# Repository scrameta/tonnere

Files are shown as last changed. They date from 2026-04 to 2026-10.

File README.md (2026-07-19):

# Project Tonnere

The EclaireXL was a partially open Atari XL FPGA implementation designed almost
a decade ago. This project is intended to be a fully open community follow-up
version. (It is being renamed **MegaXE**; *tonnere* — deliberately misspelt, to
match "EclaireXL" — is French for thunder, following on from the EclaireXL's
lightning.)

## The Atari core

The FPGA Atari core itself is **not** duplicated here. It lives in the shared
[**atari_xl_fpga_common**](https://github.com/scrameta/atari_xl_fpga_common)
repository — the same core used by the multi-board
[atari_xl_fpga](https://github.com/scrameta/atari_xl_fpga) project — and is
included in this repo as a git submodule at `atari_800xl/common`. This board
project provides the hardware design plus the board-specific top level, clocking,
pin mapping and I/O wrapped around that common core.

## Getting the code

The shared core is a submodule, so clone recursively:

```sh
git clone --recursive https://github.com/scrameta/tonnere

# …or, if you already cloned without --recursive:
git submodule update --init --recursive
```

The core then appears under `atari_800xl/common`. To move onto a newer core
revision, bump the submodule pointer:

```sh
cd atari_800xl/common
git checkout <desired-commit-or-branch>
cd -
git add atari_800xl/common
git commit -m "Bump common core to <rev>"
```

See the
[common repo](https://github.com/scrameta/atari_xl_fpga_common#using-this-repository)
for more on the submodule workflow.

## Status

For now there is only a hardware design, from which a physical board has been
produced. The design goals of this are described below.

## Memory

3 independent banks of RAM from FPGA

- 512KB 16-bit wide 10ns SRAM (for VBXE)
- 2048KB 16-bit wide 10ns SRAM (primary Atari core)
- 32MB 16-bit wide SDRAM (secondary Atari core etc - for large memory expansions, cartridge emulation etc)

## Video output

- HDMI driven directly by FPGA
- Analog video driven by FPGA (3 pins/channel - ~8-bit/channel resolution) filtered/buffered by THS7316.
- NTSC in 480i or 480p, PAL in 576i or 576p
- Polyphasic and area-based scaler allowing 720p, 1080i etc

## Audio output

- PCM5102A DAC

## Audio input

- 12-bit ADC for PBI, SIO, 3.5mm left/right on STM microcontroller

## Joystick ports 1-4

- Directly connected to FPGA (via level shifters)
- Paddle support using STM ADC inputs

## Six USB ports

- 1 USB A internal for keyboard
- 3 USB A external for joystick, keyboard etc
- 1 USB C for power only (next to power switch)
- 1 rear USB C for STM32 DFU (to program it), or to be a mass-storage slave to a PC to copy data on.

## Atari peripheral emulator (ESP32 microcontroller/almost Fujinet)

- Wifi support
- Serial connection to STM32
- SPI master to FPGA (for DMA to RAM, faster than serial via STM)
- SIO pins (all)
- Audio out DAC goes to SIO audio in
- Slave to STM32
- Slave to Atari via SIO
- JTAG for debugging

## Firmware/control (STM32)

- SPI master to FPGA SPI flash chip (to program)
- Can restart FPGA
- SRAM port connected to FPGA (for DMA to Atari core RAM + RAM banks)
- IRQ from FPGA
- 4-bit external SD card interface
- SPI to internal micro SD card (will appear as IDE hard drive to Atari core)
- ADC for sampling (see audio in)
- Serial connection for communication for Atari peripheral emulator
- USB port + stack
- DFU mode for programming, can then program FPGA flash and ESP32 via serial (+BOOT etc).
- HDMI i2c link (to get mode support)
- PLL i2c link (6 programmable clocks for FPGA)
- SWD port for debugging
- UART port for debugging/expansion
- Will run menus etc, via DMA to Atari core (+ potentially framebuffer)

## Atari core (Cyclone 10 LP FPGA)

- Core Atari XL and Atari 800 support
- 2x/4x colour clock Antic/GTIA support
- VBXE
- PokeyMAX
- HDD via IDE emulation on microsd
- Turbo freezer
- Common cartridge banking logic (on RAM)

## Atari ports

- Left cartridge
- PBI with standard extensions (enabled/selected via jumper), 50 pin edge and 50 pin header option.
- SIO (with motor control, without 12V)
- Start/select/option/reset switch headers
- 4 joystick ports

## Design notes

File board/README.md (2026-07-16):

# Board status
## 0.51

| Component | Status | Comment |
| --- | --- | --- |
| Audio DAC |  🟢 | Played a multi-frequency sine wave fine |
| ESP32 |  🟢 | Ran simple pin toggler, also checked it appears on JTAG | 
| ESP32 audio DAC | ⚪ | |
| ESP32 WIFI | ⚪ | |
| FPGA |  🟢 | Working fine. Caution: Do not use clock input pins as outputs!  | 
| FPGA FLASH |  🟢 | Working fine. Only tested one IC.  | 
| HDMI port |  🟢 | Tested DVI video output  | 
| JOYSTICK DIR |  🟢 | Tested toggling pins |
| JOYSTICK PADDLES  | ⚪ |  |
| PLL1 |  🟢 | Programmed via I2C and checked they produce clocks |
| PLL2 |  🟢 | Programmed via I2C and checked they produce clocks |
| SDCARD(EXT) | ⚪ |  | 
| SDCARD(INT) | ⚪ |  | 
| SDRAM |  🟢 | Boots to ready | 
| SRAM1 |  🟡 | Used input pins on FPGA, had to correct with a few wires  | 
| SRAM2 |  🟡 | Used input pins on FPGA, had to correct with a few wires  | 
| STM32 ADC | ⚪ |  | 
| STM32 CORE |  🟢 | Code running fine. SWD works. USART debug works. | 
| STM32 DFU |  🟡 | DFU slow to start due to PB5 connected to FPGA flash chip during boot  | 
| STM32 RTC |  ⚪ | | 
| STM32 FSMC |  🟢 | Checked basic SRAM access via FPGA from STM | 
| PBI |  🟢 | Tested toggling pins | 
| SIO |  🟡 | Tested toggling pins. Motor control did not go via level shifter. | 
| USB |  🟢 | Tested keyboard in all ports. STM needed patches hub (class + reconnect fix) |
| Video DAC |  🟡 | Single pin was too aggressive for sigma delta (very low oversampling). Too noisy. Added 2nd pin and used fixed patterns. Achieved 6-bit |

## 0.60

Not made yet...

## Key
| Symbol | Status |
| --- | --- |
| ⚪ | Not checked yet |
| 🔴 | Failed |
| 🟡 | Works with workaround |
| 🟢 | Passed |

Passed does not mean thoroughly checked...

<!--
| Feature A | ⚪ | Not checked yet |
| Feature C | 🟡 | Works with workaround |
| Feature D | 🟢 | Passed |
-->

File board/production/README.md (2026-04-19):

# Actual board production files
Not done as tags but as an explicit file per version, for ease of visibility/access
Repo should be tagged though as of this version

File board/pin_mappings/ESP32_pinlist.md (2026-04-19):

# ESP32 module (U34: ESP32‑WROVER‑E) pin usage summary and pinlist

Derived from the KiCad netlist (`tonnere.net`). The ESP32 GPIO matrix allows
flexible peripheral routing, so this is primarily a *wiring* pinlist showing
which module pads are used and what they connect to.

## Connectivity overview

- **SPI to FPGA**: 4 pins (SCK/MOSI/MISO/CS) — direct to Cyclone 10 U30,
  no level-shifter. FPGA is bus master.
- **Atari SIO**: 8 pins — directly wired to the SIO signals (shared with FPGA
  U30 via bus switch U31). The ESP32 can participate in SIO traffic
  independently of the FPGA.
- **UART to STM32**: 2 pins (RXD0/TXD0) — direct to STM32 USART6 (PC6/PC7).
  Also broken out on J18 (ESP PGM header).
- **GPIO handshake to/from STM32**: 4 pins — 3 input-only (SGPI0-2 from
  STM32 PG8-10) + 1 output (SGPIO to STM32 PA9). None pass through the FPGA.
- **JTAG**: 4 pins (optional, directly on ESP GPIOs via GPIO matrix).
- **Audio**: 1 pin (ESPAUD.SIO via bus switch U31).
- **BOOT/EN**: IO0 (boot strap) and EN (chip enable), directly also connected to
  STM32 (PG6/PG7) and broken out on J18 header.

## Pinlist
| Module pad | ESP32 signal | GPIO | Function | Net | Notes |
|---:|---|---|---|---|---|
| 3 | EN |  | EN (chip enable/reset) | /ESP32/ESP.EN | Pull-up (R99); also on J18 ESP PGM header |
| 4 | SENSOR_VP/IO36 | IO36 | GPIO from STM32 | /ESP32/ESP.SGPI0 | Input-only; <- STM32 PG8 |
| 5 | SENSOR_VN/IO39 | IO39 | GPIO from STM32 | /ESP32/ESP.SGPI1 | Input-only; <- STM32 PG9 |
| 6 | IO34 | IO34 | GPIO from STM32 | /ESP32/ESP.SGPI2 | Input-only; <- STM32 PG10 |
| 7 | IO35 | IO35 | Atari SIO | /AtariInterfaces/SIO.MOTOR | Also to FPGA U30; ext pull-up +5V (R30) |
| 8 | IO32 | IO32 | Atari SIO | /AtariInterfaces/SIO.INTERRUPT | Also to FPGA U30; ext pull-up +5V (RN3) |
| 9 | IO33 | IO33 | Atari SIO | /AtariInterfaces/SIO.COMMAND | Also to FPGA U30; ext pull-up +5V (RN3) |
| 10 | IO25 | IO25 | Atari SIO | /AtariInterfaces/SIO.DATA_IN | Also to FPGA U30; ext pull-up +5V (RN4) |
| 11 | IO26 | IO26 | Audio SIO | /Audio/ESPAUD.SIO | Audio SIO; via bus switch U31 |
| 12 | IO27 | IO27 | Atari SIO | /AtariInterfaces/SIO.PROCEED | Also to FPGA U30; ext pull-up +5V (RN3) |
| 13 | IO14 | IO14 | JTAG (optional) | /ESP32/ESPJTAG.TMS | Via GPIO matrix |
| 14 | IO12 | IO12 | JTAG (optional) | /ESP32/ESPJTAG.TDI | Via GPIO matrix |
| 16 | IO13 | IO13 | JTAG (optional) | /ESP32/ESPJTAG.TCK | Via GPIO matrix |
| 23 | IO15 | IO15 | JTAG (optional) | /ESP32/ESPJTAG.TDO | Via GPIO matrix |
| 24 | IO2 | IO2 | GPIO to STM32 | /ESP32/ESP.SGPIO | -> STM32 PA9 |
| 25 | IO0 | IO0 | BOOT strap (GPIO0) | /ESP32/ESP.BOOT | Low=bootloader; also STM32 PG6 and J18 header |
| 26 | IO4 | IO4 | Atari SIO | /AtariInterfaces/SIO.CLOCK_OUT | Also to FPGA U30; ext pull-up +5V (RN4) |
| 29 | IO5 | IO5 | SPI to FPGA (U30) | /ESP32/ESP.CS | CS active low; pull-up to +3V3 (R94) |
| 30 | IO18 | IO18 | SPI to FPGA (U30) | /ESP32/ESP.SCK | Direct to FPGA U30 |
| 31 | IO19 | IO19 | SPI to FPGA (U30) | /ESP32/ESP.MISO | Direct to FPGA U30 |
| 33 | IO21 | IO21 | Atari SIO | /AtariInterfaces/SIO.CLOCK_IN | Also to FPGA U30; ext pull-up +5V (RN4) |
| 34 | RXD0 | RXD0 | UART to STM32 | /ESP32/UART1.TX | STM32 USART6 RX (PC7); also on J18 header |
| 35 | TXD0 | TXD0 | UART to STM32 | /ESP32/UART1.RX | STM32 USART6 TX (PC6); also on J18 header |
| 36 | IO22 | IO22 | Atari SIO | /AtariInterfaces/SIO.DATA_OUT | Also to FPGA U30; ext pull-up +5V (RN4) |
| 37 | IO23 | IO23 | SPI to FPGA (U30) | /ESP32/ESP.MOSI | Direct to FPGA U30 |

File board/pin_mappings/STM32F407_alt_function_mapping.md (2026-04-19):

# STM32F407ZG (U19) pin usage and alternate functions (from tonnere.net)

## FSMC (47 pins)
AF used: **AF12** (FSMC/FMC). Total FSMC-related pins in netlist: 47.
See the CSV/XLSX for the full per-pin list.

## SPI (4 pins)
| STM32 pin | Package pin | Signal | AF | Net | Note |
|---|---:|---|---|---|---|
| PB4 | 134 | SPI1_MISO | AF5 | /FPGA/SPI.MISO |  |
| PB5 | 135 | SPI1_MOSI | AF5 | /FPGA/SPI.MOSI |  |
| PB6 | 136 | SPI1_NSS1 (GPIO or NSS) | AF5 | /FPGA/SPI.CS1 | Chip-select likely GPIO (or SPI NSS depending config) |
| PB7 | 137 | SPI1_NSS2 (GPIO) | AF5 | /FPGA/SPI.CS2 | Chip-select likely GPIO (or SPI NSS depending config) |

## USART/UART (7 pins)
| STM32 pin | Package pin | Signal | AF | Net | Note |
|---|---:|---|---|---|---|
| PB10 | 69 | USART3_TX | AF7 (USART3) | /Microcontroller/USART1.TX |  |
| PB11 | 70 | USART3_RX | AF7 (USART3) | /Microcontroller/USART1.RX |  |
| PB12 | 73 | USART3_CK | AF7 (USART3) | /Microcontroller/USART1.CK |  |
| PB13 | 74 | USART3_CTS | AF7 (USART3) | /Microcontroller/USART1.CTS |  |
| PB14 | 75 | USART3_RTS | AF7 (USART3) | /Microcontroller/USART1.RTS |  |
| PC6 | 96 | USART6_TX | AF8 (USART6) | /ESP32/UART1.TX |  |
| PC7 | 97 | USART6_RX | AF8 (USART6) | /ESP32/UART1.RX |  |

## I2C (3 pins)
| STM32 pin | Package pin | Signal | AF | Net | Note |
|---|---:|---|---|---|---|
| PB8 | 139 | I2C1_SCL | AF4 | /Microcontroller/STM.SCL |  |
| PB9 | 140 | I2C1_SDA | AF4 | /Microcontroller/STM.SDA |  |
| PC5 | 45 | I2C | AF4 | /Microcontroller/STM.I2CRESET | Reset line for I2C devices? (GPIO) |

## GPIO/Other (46 pins)
| STM32 pin | Package pin | Signal | AF | Net | Note |
|---|---:|---|---|---|---|
| PA0 | 34 | JOY2.POT4 | None | /AtariInterfaces/JOY2.POT4 | Analog input (ADC) for paddle/pot |
| PA1 | 35 | JOY2.POT5 | None | /AtariInterfaces/JOY2.POT5 | Analog input (ADC) for paddle/pot |
| PA13 | 105 | Net-(J9-Pin_2) | None | Net-(J9-Pin_2) |  |
| PA14 | 109 | Net-(J9-Pin_3) | None | Net-(J9-Pin_3) |  |
| PA2 | 36 | STMAUD.ADC.L | None | /Audio/STMAUD.ADC.L |  |
| PA3 | 37 | STMAUD.ADC.R | None | /Audio/STMAUD.ADC.R |  |
| PA4 | 40 | JOY2.POT6 | None | /AtariInterfaces/JOY2.POT6 | Analog input (ADC) for paddle/pot |
| PA5 | 41 | JOY2.POT7 | None | /AtariInterfaces/JOY2.POT7 | Analog input (ADC) for paddle/pot |
| PA6 | 42 | STMAUD.ADC.PBI | None | /Audio/STMAUD.ADC.PBI |  |
| PA7 | 43 | STMAUD.ADC.SIO | None | /Audio/STMAUD.ADC.SIO |  |
| PB2 | 48 | BOOT1 | None | /Microcontroller/BOOT1 |  |
| PB3 | 133 | Net-(U19-PB3) | None | Net-(U19-PB3) |  |
| PC0 | 26 | JOY.POT0 | None | /AtariInterfaces/JOY.POT0 | Analog input (ADC) for paddle/pot |
| PC1 | 27 | JOY.POT1 | None | /AtariInterfaces/JOY.POT1 | Analog input (ADC) for paddle/pot |
| PC10 | 111 | Net-(RN10-R2.2) | None | Net-(RN10-R2.2) |  |
| PC11 | 112 | Net-(RN10-R1.2) | None | Net-(RN10-R1.2) |  |
| PC12 | 113 | Net-(RN7-R4.2) | None | Net-(RN7-R4.2) |  |
| PC13 | 7 | Net-(RN7-R3.2) | None | Net-(RN7-R3.2) |  |
| PC14 | 8 | Net-(U19-PC14) | None | Net-(U19-PC14) |  |
| PC15 | 9 | Net-(U19-PC15) | None | Net-(U19-PC15) |  |
| PC2 | 28 | JOY.POT2 | None | /AtariInterfaces/JOY.POT2 | Analog input (ADC) for paddle/pot |
| PC3 | 29 | JOY.POT3 | None | /AtariInterfaces/JOY.POT3 | Analog input (ADC) for paddle/pot |
| PC8 | 98 | Net-(RN10-R4.2) | None | Net-(RN10-R4.2) |  |
| PC9 | 99 | Net-(RN10-R3.2) | None | Net-(RN10-R3.2) |  |
| PD2 | 116 | Net-(RN7-R1.2) | None | Net-(RN7-R1.2) |  |
| PD3 | 117 | Net-(RN7-R2.2) | None | Net-(RN7-R2.2) |  |
| PF10 | 22 | Net-(J10-Pin_3) | None | Net-(J10-Pin_3) |  |
| PF6 | 18 | Net-(J10-Pin_7) | None | Net-(J10-Pin_7) |  |
| PF7 | 19 | Net-(J10-Pin_6) | None | Net-(J10-Pin_6) |  |
| PF8 | 20 | Net-(J10-Pin_5) | None | Net-(J10-Pin_5) |  |
| PF9 | 21 | Net-(J10-Pin_4) | None | Net-(J10-Pin_4) |  |
| PG11 | 126 | FPGA.PS_N | None | /FPGA/FPGA.PS_N |  |
| PG12 | 127 | FPGA.IRQ | None | /FPGA/FPGA.IRQ |  |
| PG13 | 128 | FPGA.CONFIG_N | None | /FPGA/FPGA.CONFIG_N |  |
| PG14 | 129 | FPGA.STATUS_N | None | /FPGA/FPGA.STATUS_N |  |
| PG15 | 132 | FPGA.CONF_DONE | None | /FPGA/FPGA.CONF_DONE |  |
| PG6 | 91 | ESP.BOOT | None | /ESP32/ESP.BOOT |  |
| PG7 | 92 | ESP.EN | None | /ESP32/ESP.EN |  |
| PG8 | 93 | ESP.SGPI0 | None | /ESP32/ESP.SGPI0 |  |
| PG9 | 124 | ESP.SGPI1 | None | /ESP32/ESP.SGPI1 |  |
| PG10 | 125 | ESP.SGPI2 | None | /ESP32/ESP.SGPI2 |  |
| PA9 | 101 | ESP.SGPIO | None | /ESP32/ESP.SGPIO |  |
| PH0 | 23 | Net-(U19-PH0) | None | Net-(U19-PH0) |  |
| PH1 | 24 | Net-(U19-PH1) | None | Net-(U19-PH1) |  |
| nan | 25 | NRST | None | /Microcontroller/NRST |  |
| nan | 138 | Net-(JP1-C) | None | Net-(JP1-C) |  |

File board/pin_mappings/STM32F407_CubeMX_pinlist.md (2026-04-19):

# STM32F407ZG (U19) CubeMX-style summary and pinlist

Derived from the KiCad netlist (`tonnere.net`). Reflects which STM32 pins are
wired to which functions, with alternate-function assignments where applicable.

## Peripheral summary

- **FMC/FSMC** (AF12): 47 pins — external bus to FPGA U30 (address/data/control).
  Direct wiring, no bus switch.
- **SPI** (AF5): 4 pins (PB3-PB7) — shared active-serial/SD/flash SPI bus.
  PB3 (SCK) via series R52.  PB6/PB7 are chip-selects (CS1=SD, CS2=FPGA flash).
- **USART3** (AF7): 5 pins (PB10-PB14) — general-purpose USART.
  Note: net labels say USART1 but the STM32 AF7 on PB10-14 is USART3.
- **USART6** (AF8): 2 pins (PC6/PC7) — UART to ESP32 (RXD0/TXD0).
  Also broken out on J18 (ESP PGM header).
- **I2C1** (AF4): 2 pins (PB8/PB9) + 1 GPIO reset (PC5).
- **SDIO** (AF12): 6 pins (PC8-PC12, PD2) — SD card interface via series
  resistor networks RN7 (CMD/CK) and RN10 (D0-D3). PC13 is SD card detect (GPIO).
- **Debug**: PA13/PA14 (SWDIO/SWCLK) on J9 SWD header.
  PC14/PC15 are OSC32_IN/OUT (32.768 kHz RTC crystal Y2).
- **ADC analog inputs**: joystick pots (PA0-1/PA4-5/PC0-3) and audio ADC (PA2-3/PA6-7).
- **ESP32 GPIO**: PG6/PG7 -> ESP32 IO0/EN (boot/reset control, also on J18).
  PG8-10 -> ESP32 input-only SGPI0-2.  PA9 <- ESP32 SGPIO (IO2).
- **FPGA control**: PG11 -> MSEL1, PG12 <- IRQ, PG13 -> nCONFIG,
  PG14 <- nSTATUS, PG15 <- CONF_DONE.

## Pinlist
| STM32 pin | LQFP pin | Mode (CubeMX) | AF | User label | Net | Notes |
|---|---:|---|---|---|---|---|
| PA13 | 105 | Debug |  | SWDIO | Net-(J9-Pin_2) | J9 SWD header pin 2 |
| PA14 | 109 | Debug |  | SWCLK | Net-(J9-Pin_3) | J9 SWD header pin 3 |
| PA11 | 103 | FSMC (AF12) | AF12 | FSMC | Net-(U19-PA11) |  |
| PA12 | 104 | FSMC (AF12) | AF12 | FSMC | Net-(U19-PA12) |  |
| PD0 | 114 | FSMC (AF12) | AF12 | FSMC_D2 | /FPGA/FSMC.D2 |  |
| PD1 | 115 | FSMC (AF12) | AF12 | FSMC_D3 | /FPGA/FSMC.D3 |  |
| PD10 | 79 | FSMC (AF12) | AF12 | FSMC_D15 | /FPGA/FSMC.D15 |  |
| PD11 | 80 | FSMC (AF12) | AF12 | FSMC_A16 | /FPGA/FSMC.A16 |  |
| PD12 | 81 | FSMC (AF12) | AF12 | FSMC_A17 | /FPGA/FSMC.A17 |  |
| PD13 | 82 | FSMC (AF12) | AF12 | FSMC_A18 | /FPGA/FSMC.A18 |  |
| PD14 | 85 | FSMC (AF12) | AF12 | FSMC_D0 | /FPGA/FSMC.D0 |  |
| PD15 | 86 | FSMC (AF12) | AF12 | FSMC_D1 | /FPGA/FSMC.D1 |  |
| PD4 | 118 | FSMC (AF12) | AF12 | FSMC_NOE | /FPGA/FSMC.NOE |  |
| PD5 | 119 | FSMC (AF12) | AF12 | FSMC_NWE | /FPGA/FSMC.NWE |  |
| PD6 | 122 | FSMC (AF12) | AF12 | FSMC_NWAIT | /FPGA/FSMC.NWAIT |  |
| PD7 | 123 | FSMC (AF12) | AF12 | FSMC_NE1 | /FPGA/FSMC.NE1 |  |
| PD8 | 77 | FSMC (AF12) | AF12 | FSMC_D13 | /FPGA/FSMC.D13 |  |
| PD9 | 78 | FSMC (AF12) | AF12 | FSMC_D14 | /FPGA/FSMC.D14 |  |
| PE0 | 141 | FSMC (AF12) | AF12 | FSMC_NBL0 | /FPGA/FSMC.NBL0 |  |
| PE1 | 142 | FSMC (AF12) | AF12 | FSMC_NBL1 | /FPGA/FSMC.NBL1 |  |
| PE10 | 63 | FSMC (AF12) | AF12 | FSMC_D7 | /FPGA/FSMC.D7 |  |
| PE11 | 64 | FSMC (AF12) | AF12 | FSMC_D8 | /FPGA/FSMC.D8 |  |
| PE12 | 65 | FSMC (AF12) | AF12 | FSMC_D9 | /FPGA/FSMC.D9 |  |
| PE13 | 66 | FSMC (AF12) | AF12 | FSMC_D10 | /FPGA/FSMC.D10 |  |
| PE14 | 67 | FSMC (AF12) | AF12 | FSMC_D11 | /FPGA/FSMC.D11 |  |
| PE15 | 68 | FSMC (AF12) | AF12 | FSMC_D12 | /FPGA/FSMC.D12 |  |
| PE3 | 2 | FSMC (AF12) | AF12 | FSMC_A19 | /FPGA/FSMC.A19 |  |
| PE4 | 3 | FSMC (AF12) | AF12 | FSMC_A20 | /FPGA/FSMC.A20 |  |
| PE5 | 4 | FSMC (AF12) | AF12 | FSMC_A21 | /FPGA/FSMC.A21 |  |
| PE6 | 5 | FSMC (AF12) | AF12 | FSMC_A22 | /FPGA/FSMC.A22 |  |
| PE7 | 58 | FSMC (AF12) | AF12 | FSMC_D4 | /FPGA/FSMC.D4 |  |
| PE8 | 59 | FSMC (AF12) | AF12 | FSMC_D5 | /FPGA/FSMC.D5 |  |
| PE9 | 60 | FSMC (AF12) | AF12 | FSMC_D6 | /FPGA/FSMC.D6 |  |
| PF0 | 10 | FSMC (AF12) | AF12 | FSMC_A0 | /FPGA/FSMC.A0 |  |
| PF1 | 11 | FSMC (AF12) | AF12 | FSMC_A1 | /FPGA/FSMC.A1 |  |
| PF12 | 50 | FSMC (AF12) | AF12 | FSMC_A6 | /FPGA/FSMC.A6 |  |
| PF13 | 53 | FSMC (AF12) | AF12 | FSMC_A7 | /FPGA/FSMC.A7 |  |
| PF14 | 54 | FSMC (AF12) | AF12 | FSMC_A8 | /FPGA/FSMC.A8 |  |
| PF15 | 55 | FSMC (AF12) | AF12 | FSMC_A9 | /FPGA/FSMC.A9 |  |
| PF2 | 12 | FSMC (AF12) | AF12 | FSMC_A2 | /FPGA/FSMC.A2 |  |
| PF3 | 13 | FSMC (AF12) | AF12 | FSMC_A3 | /FPGA/FSMC.A3 |  |
| PF4 | 14 | FSMC (AF12) | AF12 | FSMC_A4 | /FPGA/FSMC.A4 |  |
| PF5 | 15 | FSMC (AF12) | AF12 | FSMC_A5 | /FPGA/FSMC.A5 |  |
| PG0 | 56 | FSMC (AF12) | AF12 | FSMC_A10 | /FPGA/FSMC.A10 |  |
| PG1 | 57 | FSMC (AF12) | AF12 | FSMC_A11 | /FPGA/FSMC.A11 |  |
| PG2 | 87 | FSMC (AF12) | AF12 | FSMC_A12 | /FPGA/FSMC.A12 |  |
| PG3 | 88 | FSMC (AF12) | AF12 | FSMC_A13 | /FPGA/FSMC.A13 |  |
| PG4 | 89 | FSMC (AF12) | AF12 | FSMC_A14 | /FPGA/FSMC.A14 |  |
| PG5 | 90 | FSMC (AF12) | AF12 | FSMC_A15 | /FPGA/FSMC.A15 |  |
| NRST | 25 | GPIO (TBD) |  | NRST | /Microcontroller/NRST |  |
| Net-(JP1-C) | 138 | GPIO (TBD) |  | Net-(JP1-C) | Net-(JP1-C) |  |
| PA0 | 34 | GPIO (TBD) |  | JOY2.POT4 | /AtariInterfaces/JOY2.POT4 | Analog input (ADC) for paddle/pot |
| PA1 | 35 | GPIO (TBD) |  | JOY2.POT5 | /AtariInterfaces/JOY2.POT5 | Analog input (ADC) for paddle/pot |
| PA2 | 36 | GPIO (TBD) |  | STMAUD.ADC.L | /Audio/STMAUD.ADC.L |  |
| PA3 | 37 | GPIO (TBD) |  | STMAUD.ADC.R | /Audio/STMAUD.ADC.R |  |
| PA4 | 40 | GPIO (TBD) |  | JOY2.POT6 | /AtariInterfaces/JOY2.POT6 | Analog input (ADC) for paddle/pot |
| PA5 | 41 | GPIO (TBD) |  | JOY2.POT7 | /AtariInterfaces/JOY2.POT7 | Analog input (ADC) for paddle/pot |
| PA6 | 42 | GPIO (TBD) |  | STMAUD.ADC.PBI | /Audio/STMAUD.ADC.PBI |  |
| PA7 | 43 | GPIO (TBD) |  | STMAUD.ADC.SIO | /Audio/STMAUD.ADC.SIO |  |
| PA9 | 101 | GPIO (TBD) |  | ESP.SGPIO | /ESP32/ESP.SGPIO | ESP32 IO2 (SGPIO) via R92 |
| PB2 | 48 | GPIO (TBD) |  | BOOT1 | /Microcontroller/BOOT1 |  |
| PC0 | 26 | GPIO (TBD) |  | JOY.POT0 | /AtariInterfaces/JOY.POT0 | Analog input (ADC) for paddle/pot |
| PC1 | 27 | GPIO (TBD) |  | JOY.POT1 | /AtariInterfaces/JOY.POT1 | Analog input (ADC) for paddle/pot |
| PC2 | 28 | GPIO (TBD) |  | JOY.POT2 | /AtariInterfaces/JOY.POT2 | Analog input (ADC) for paddle/pot |
| PC3 | 29 | GPIO (TBD) |  | JOY.POT3 | /AtariInterfaces/JOY.POT3 | Analog input (ADC) for paddle/pot |
| PD3 | 117 | GPIO (TBD) |  | Net-(RN7-R2.2) | Net-(RN7-R2.2) |  |
| PF10 | 22 | GPIO (TBD) |  | Net-(J10-Pin_3) | Net-(J10-Pin_3) |  |
| PF6 | 18 | GPIO (TBD) |  | Net-(J10-Pin_7) | Net-(J10-Pin_7) |  |
| PF7 | 19 | GPIO (TBD) |  | Net-(J10-Pin_6) | Net-(J10-Pin_6) |  |
| PF8 | 20 | GPIO (TBD) |  | Net-(J10-Pin_5) | Net-(J10-Pin_5) |  |
| PF9 | 21 | GPIO (TBD) |  | Net-(J10-Pin_4) | Net-(J10-Pin_4) |  |
| PG10 | 125 | GPIO (TBD) |  | ESP.SGPI2 | /ESP32/ESP.SGPI2 | ESP32 input-only IO34 (SGPI2) |
| PG11 | 126 | GPIO (TBD) |  | FPGA.PS_N | /FPGA/FPGA.PS_N |  |
| PG12 | 127 | GPIO (TBD) |  | FPGA.IRQ | /FPGA/FPGA.IRQ |  |
| PG13 | 128 | GPIO (TBD) |  | FPGA.CONFIG_N | /FPGA/FPGA.CONFIG_N |  |
| PG14 | 129 | GPIO (TBD) |  | FPGA.STATUS_N | /FPGA/FPGA.STATUS_N |  |
| PG15 | 132 | GPIO (TBD) |  | FPGA.CONF_DONE | /FPGA/FPGA.CONF_DONE |  |
| PG6 | 91 | GPIO (TBD) |  | ESP.BOOT | /ESP32/ESP.BOOT | ESP32 IO0 boot strap; also on J18 header |
| PG7 | 92 | GPIO (TBD) |  | ESP.EN | /ESP32/ESP.EN | ESP32 EN; also on J18 header |
| PG8 | 93 | GPIO (TBD) |  | ESP.SGPI0 | /ESP32/ESP.SGPI0 | ESP32 input-only IO36 (SGPI0) |
| PG9 | 124 | GPIO (TBD) |  | ESP.SGPI1 | /ESP32/ESP.SGPI1 | ESP32 input-only IO39 (SGPI1) |
| PH0 | 23 | GPIO (TBD) |  | Net-(U19-PH0) | Net-(U19-PH0) |  |
| PH1 | 24 | GPIO (TBD) |  | Net-(U19-PH1) | Net-(U19-PH1) |  |
| PB8 | 139 | I2C (AF4) | AF4 | I2C1_SCL | /Microcontroller/STM.SCL |  |
| PB9 | 140 | I2C (AF4) | AF4 | I2C1_SDA | /Microcontroller/STM.SDA |  |
| PC5 | 45 | I2C (AF4) | AF4 | I2C | /Microcontroller/STM.I2CRESET | Reset line for I2C devices? (GPIO) |
| PC14 | 8 | RTC |  | OSC32_IN | Net-(U19-PC14) | 32.768 kHz crystal Y2 |
| PC15 | 9 | RTC |  | OSC32_OUT | Net-(U19-PC15) | 32.768 kHz crystal Y2 |
| PC10 | 111 | SDIO (AF12) | AF12 | SDIO_D2 | Net-(RN10-R2.2) | Via RN10 to SD card D2 |
| PC11 | 112 | SDIO (AF12) | AF12 | SDIO_D3 | Net-(RN10-R1.2) | Via RN10 to SD card D3 |
| PC12 | 113 | SDIO (AF12) | AF12 | SDIO_CK | Net-(RN7-R4.2) | Via RN7 to SD card CLK |
| PC13 | 7 | SDIO |  | SD_DETECT | Net-(RN7-R3.2) | Via RN7 to SD card detect |
| PC8 | 98 | SDIO (AF12) | AF12 | SDIO_D0 | Net-(RN10-R4.2) | Via RN10 to SD card D0 |
| PC9 | 99 | SDIO (AF12) | AF12 | SDIO_D1 | Net-(RN10-R3.2) | Via RN10 to SD card D1 |
| PD2 | 116 | SDIO (AF12) | AF12 | SDIO_CMD | Net-(RN7-R1.2) | Via RN7 to SD card CMD |
| PB3 | 133 | SPI (AF5) | AF5 | SPI1_SCK | Net-(U19-PB3) | Via series R52 to SPI.SCK bus |
| PB4 | 134 | SPI (AF5) | AF5 | SPI1_MISO | /FPGA/SPI.MISO |  |
| PB5 | 135 | SPI (AF5) | AF5 | SPI1_MOSI | /FPGA/SPI.MOSI |  |
| PB6 | 136 | SPI (AF5) | AF5 | SPI1_NSS1 (GPIO or NSS) | /FPGA/SPI.CS1 | Chip-select likely GPIO (or SPI NSS depending config) |
| PB7 | 137 | SPI (AF5) | AF5 | SPI1_NSS2 (GPIO) | /FPGA/SPI.CS2 | Chip-select likely GPIO (or SPI NSS depending config) |
| PB10 | 69 | USART/UART (AF7 (USART3)) | AF7 (USART3) | USART3_TX | /Microcontroller/USART1.TX |  |
| PB11 | 70 | USART/UART (AF7 (USART3)) | AF7 (USART3) | USART3_RX | /Microcontroller/USART1.RX |  |
| PB12 | 73 | USART/UART (AF7 (USART3)) | AF7 (USART3) | USART3_CK | /Microcontroller/USART1.CK |  |
| PB13 | 74 | USART/UART (AF7 (USART3)) | AF7 (USART3) | USART3_CTS | /Microcontroller/USART1.CTS |  |
| PB14 | 75 | USART/UART (AF7 (USART3)) | AF7 (USART3) | USART3_RTS | /Microcontroller/USART1.RTS |  |
| PC6 | 96 | USART/UART (AF8 (USART6)) | AF8 (USART6) | USART6_TX | /ESP32/UART1.TX | ESP32 RXD0; also on J18 header |
| PC7 | 97 | USART/UART (AF8 (USART6)) | AF8 (USART6) | USART6_RX | /ESP32/UART1.RX | ESP32 TXD0; also on J18 header |

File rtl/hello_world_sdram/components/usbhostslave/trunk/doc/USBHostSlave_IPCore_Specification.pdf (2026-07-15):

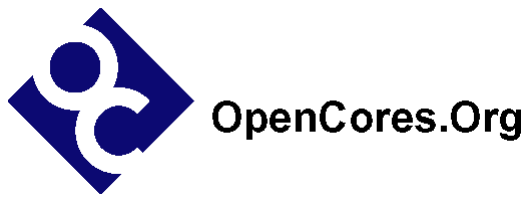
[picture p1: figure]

# USBHostSlave IP Core Specification

### Author: Steve Fielding sfielding@base2designs.com

### Rev. 1.2 June 8, 2008

OpenCores | 6/8/2008

This page has been intentionally left blank.

www.opencores.org | Rev 1.2 | ii

## Revision History

Rev. | Date | Author | Description
0.1 | 10/01/04 | Sfielding | Created
0.2 | 12/05/04 | Sfielding | Fixed frame_num register description
0.3 | 01/11/05 | Sfielding | Added host slave mode register
0.4 | 01/25/05 | Sfielding | Added Version number register, and changed host and slave frameNum registers
0.5 | 02/10/05 | Sfielding | Added instructions for clearing interrupt registers
0.6 | 02/25/05 | Sfielding | Added isochronous mode control. Altered descriptions of endpoint control and status registers
0.7 | 06/04/05 | Sfielding | Added SOF timer register Split version number into major, and minor Added HOST_RX_FIFO_DATA reg to register memory map
1.0 | 10/14/05 | Sfielding | Seperated bus clock and usb clock. Updated Wishbone datasheet. Removed Tx and Rx fifo status registers, and removed TX fifo data count register. Added RESET_CORE bit to HOST_SLAVE_CONTROL_REG. Fixed slave mode bug which caused receive fifo to be filled with incoming data when the slave was responding with a NAK, and the data should have been discarded.
1.1 | 3/24/06 | Sfielding | Fixed 48MHz clock tolerance requirement, and added note to clock chapter about 48MHz oscillator on Development boards.
1.2 | 6/06/08 | Sfielding | Added slave register descriptions, and pin descriptions for VBUS detect, and D+ D- pull-up control. Changed minimum bus clock frequency.
www.opencores.org | Rev 1.2 | iii

# Contents

www.opencores.org | Rev 1.2 | iv

1

# Introduction

USBHostSlave is a USB 1.1 Host and Device IP core.
– Supports full speed (12Mbps) and low speed (1.5Mbps) operation.
– USB Device has four endpoints, each with their own independent FIFO.
– Supports the four types of USB data transfer; control, bulk, interrupt, and isochronous transfers.
– Host can automatically generate SOF packets.
– 8-bit Wishbone slave bus interface.
– FIFO depth configurable via parameters.
www.opencores.org | Rev 1.1 | 1 of 30

2

# Architecture

The USBhostSlave IP core consists of five major functional blocks (see Figure (1) ). USBSerialInterfaceEngine – Supports the lowest level of the USB 1.1 protocol layer. On the transmit path, USBSerialInterfaceEngine implements, sync insertion, CRC calculation and insertion, parallel to serial conversion, bit stuffing, and NRZI encoding. On the receive path, USBSerialInterfaceEngine, implements connection state detection, sync detection and stripping, clock recovery, NRZI decoding, bit de-stuffing, CRC calculation and checking, and serial to parallel conversion.
HostSlaveMux – Allows host and slave controllers to share access to the USBSerialInterfaceEngine.
USBSlaveControl – Supports the USB 1.1 Device specific portion of the USB 1.1 protocol layer. Supports all USB 1.1 transaction types; bulk, setup, interrupt, and isochronous.
USBHostControl – Supports the USB 1.1 Host specific portion of the USB 1.1 protocol layer. Supports all USB 1.1 transaction types; bulk, setup, interrupt, and isochronous. Supports automatic preamble insertion, and automatic SOF generation and transmission WishBoneBI – Provides Wishbone compatible interface to host/slave controllers and the transmit/receive FIFOs.

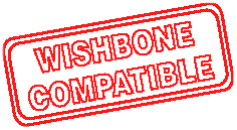
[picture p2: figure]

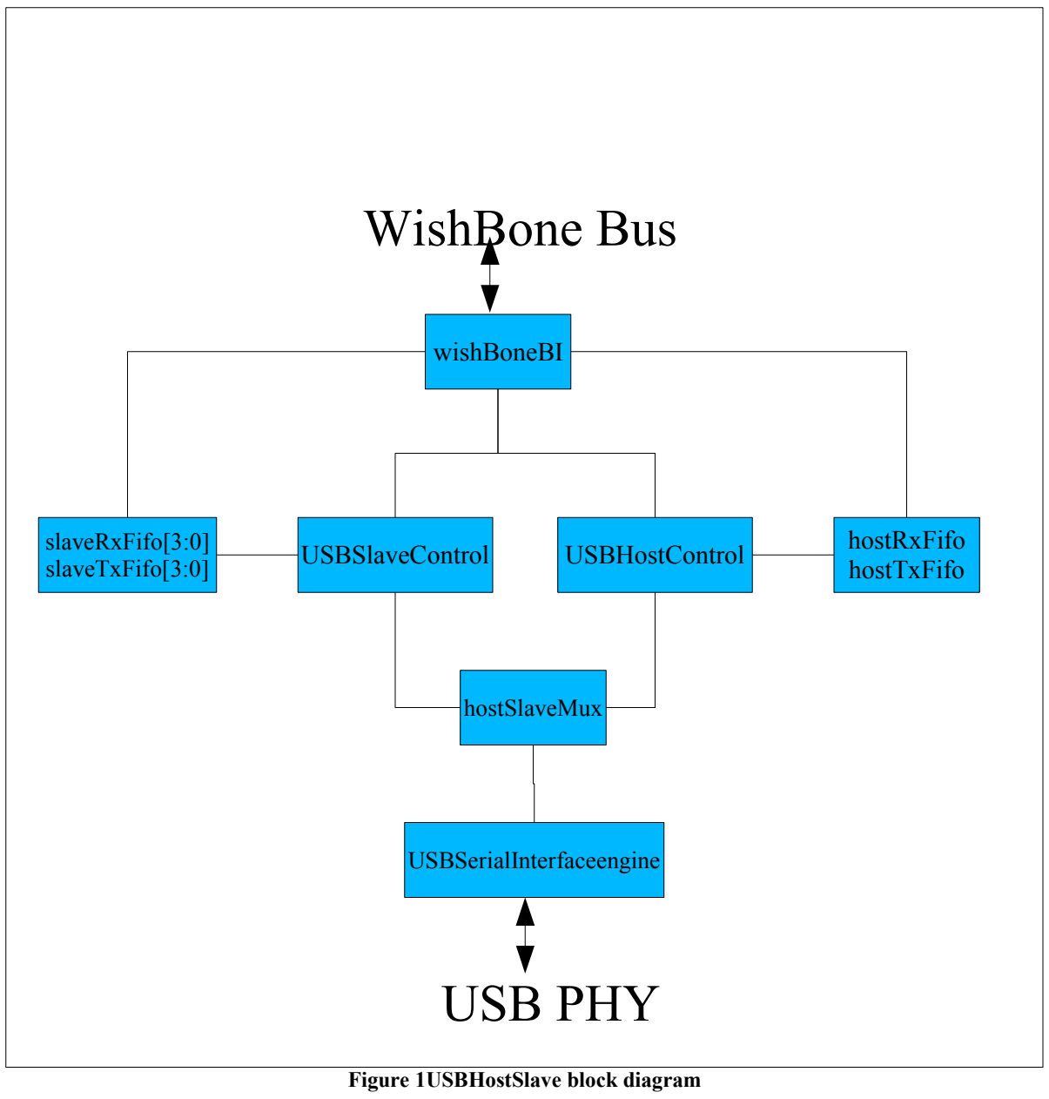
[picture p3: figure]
Figure 1USBHostSlave block diagram; wishBoneBI; WishBone Bus; hostTxFifo; slaveRxFifo[3:0] slaveTxFifo[3:0]; hostSlaveMux; USBSerialInterfaceengine; USB PHY

USBSlaveControl | USBHostControl | hostRxFifo

3

# Operation

Consider a system consisting of a USBHostSlave IP core, a USB PHY (eg Fairchild USB1T11A), and a microprocessor (see figure (2) ).

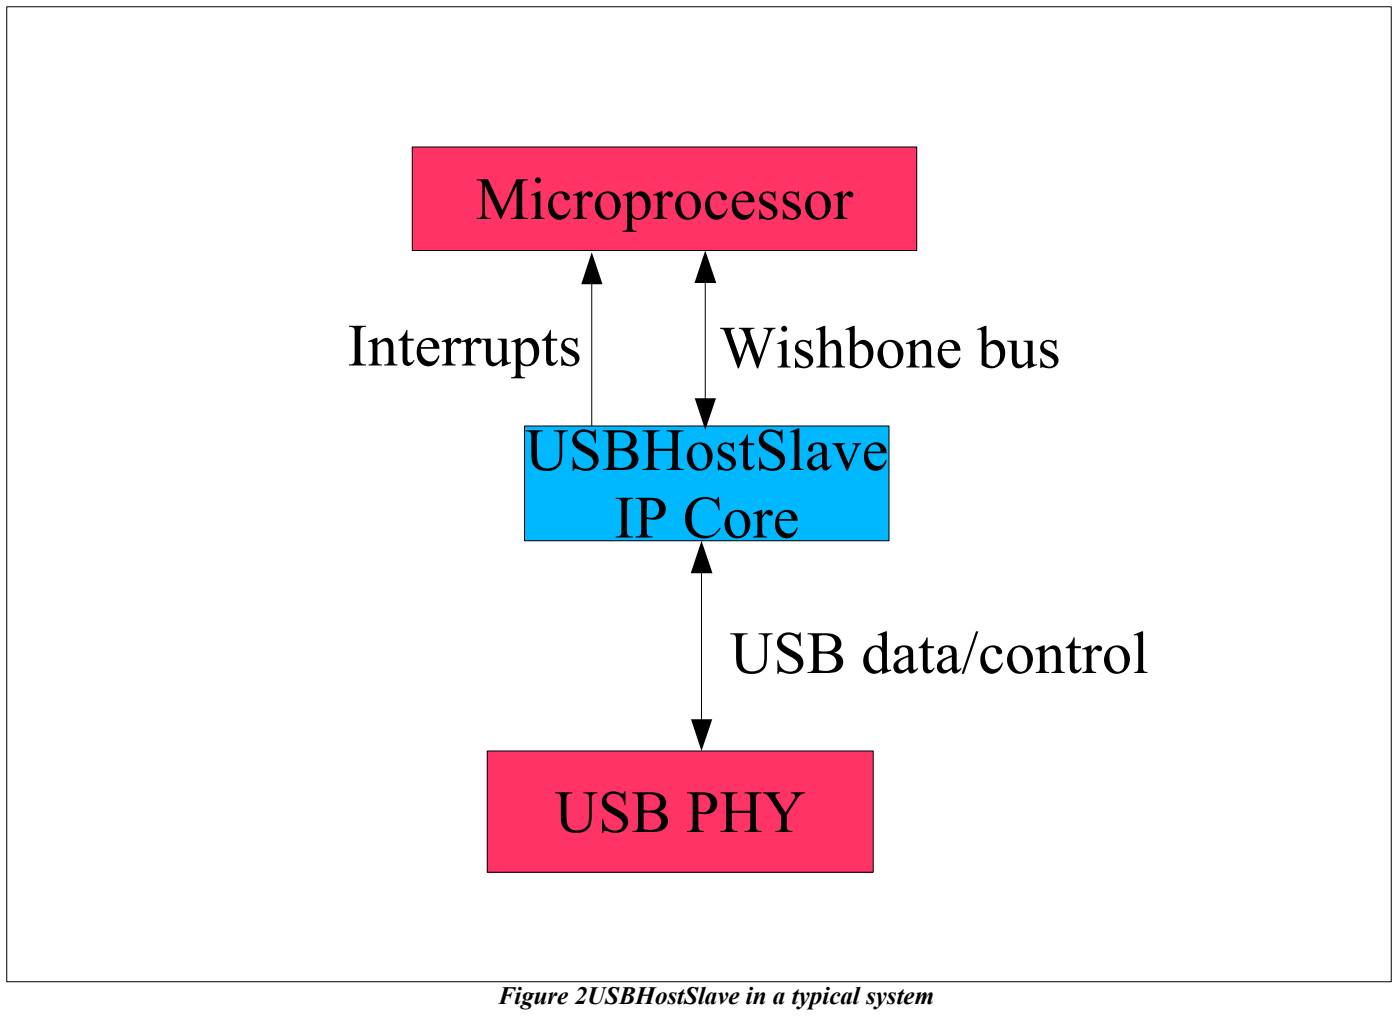
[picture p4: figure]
USBHostSlave IP Core; Wishbone bus; USB data/control; Interrupts; Microprocessor; USB PHY

Figure 2USBHostSlave in a typical system

There are two scenarios to consider. Firstly where a USBHostSlave is configured as a USB Host, and the second where it is configured as USB Device.
Let's consider the Host configuration first. On power up, the microprocessor will configure USBHostSlave as a USB Host. If the Host is not connected to a USB Device, then USBHostSlave will report that the USB line is in a disconnect state. When the Host is connected to a Device, USBHostSlave will report the connection event and the connection speed. Now the following USBHostSlave parameters can be configured;
- USB speed.
- USB polarity.
- The USB address of the attached Device (Address zero is the default Device address).
- The USB endpoint (endpoint zero is used for set up) within the attached Device.
Now that the Host has been configured, the Host can attempt to complete a transfer with the attached USB Device. Let's use the example of the Host sending data to the USB Device. First the USBHostSlave transmit FIFO will be loaded with data, then the transaction type will be set, and finally the transaction request flag will be set. The microprocessor detects that the transaction is complete by checking for the transaction done flag to be set, or waiting for the transaction done interrupt.

Now let's take a look at the case where USBHostSlave is configured as a USB Device. On power up, the microprocessor will configure USBHostSlave as a USB Device. If the Device is not connected to a USB Host, then USBHostSlave will report that the USB line is in a reset state. When the Device is connected to a Host, USBHostSlave will report the connection event and the connection speed. Now the following USBHostSlave parameters can be configured;
- USB speed.
- USB polarity.
- The USB address (Address zero is the default Device address).
- Set the global endpoint enable flag
If the Device is expecting a transaction then it must be prepared to accept the transaction. If an incoming data packet is expected then simply set the enable flag for the endpoint that is expecting a transaction, and wait for the transaction done flag (or transaction done interrupt) to be set. If the expected transaction involves outgoing data, then the endpoint FIFO will have to be loaded with data before the enable flag is set.

4

# Registers

### USB Host Slave Common Registers

Register Address | Name
0xe0 | HOST_SLAVE_CONTROL_REG
0xe1 | HOST_SLAVE_VERSION_REG

HOST_SLAVE_CONTROL_REG
Bit Position | Name | Description
0 | HOST_MODE | Set to 1 to enable host mode. Set to 0 to enable slave mode.
1 | RESET_CORE | Write only. Value is not latched. Set to 1 to reset all the logic including registers. Must wait 10 usbClk cycles for reset to complete.

HOST_SLAVE_VERSION_REG
Bit Position | Name | Description
[7:4] | VERSION_NUM_MAJOR | Major revision number
[3:0] | VERSION_NUM_MINOR | Minor revision number

### USB Host

Register Address | Name
0x0 | HOST_TX_CONTROL_REG
0x1 | HOST_TX_TRANS_TYPE_REG
0x2 | HOST_TX_LINE_CONTROL_REG
0x3 | HOST_TX_SOF_ENABLE_REG
0x4 | HOST_TX_ADDR_REG
0x5 | HOST_TX_ENDP_REG

Register Address | Name
0x6 | HOST_FRAME_NUM_MSP_REG
0x7 | HOST_FRAME_NUM_LSP_REG
0x8 | HOST_INTERRUPT_STATUS_REG
0x9 | HOST_INTERRUPT_MASK_REG
0xa | HOST_RX_STATUS_REG
0xb | HOST_RX_PID_REG
0xc | HOST_RX_ADDR_REG
0xd | HOST_RX_ENDP_REG
0xe | HOST_RX_CONNECT_STATE_REG
0xf | HOST_SOF_TIMER_MSB_REG
0x20 | HOST_RX_FIFO_DATA
0x21 | Reserved
0x22 | HOST_RX_FIFO_DATA_COUNT_MSB
0x23 | HOST_RX_FIFO_DATA_COUNT_LSB
0x24 | HOST_RX_FIFO_CONTROL_REG
0x30 | HOST_TX_FIFO_DATA
0x31 | Reserved
0x32 | Reserved
0x33 | Reserved
0x34 | HOST_TX_FIFO_CONTROL_REG

HOST_TX_CONTROL_REG
Bit Position | Name | Description
0 | TRANS_REQ_BIT | Set to 0 to disable transaction. Set to 1 to enable transaction, automatically cleared when transaction complete.
1 | SOF_SYNC_BIT | Set to 1 to syncrhonize transaction with the end of SOF transmission.Transaction will be scheduled for transmission immediately after SOF transmission.
2 | PREAMBLE_ENABLE_BIT | Set to 1 to enable preamble. Should only be enabled when the host is connected to a low speed device via a hub. The preamble is a token which is prefixed to all packet transmissions, and is transmitted at full speed irrespective of the state of the FULL_SPEED_LINE_RATE_BIT.

Bit Position | Name | Description
3 | ISO_ENABLE_BIT | Set to 1 to enable isochronous mode. In isochronous mode, no acknowledgements are sent or received. Note, the TRANS_TYPE_REG must be set to either IN_TRANS or OUTDATA0_TRANS. Isochronous mode is not allowed with any other transaction types.

HOST_RX_CONNECT_STATE_REG
Bit Position | Name | Description
[1:0] | RX_LINE_STATE | The contents of RX_CONNECT_STATE_REG reflect the current connection state, where; DISCONNECT = 0 LOW_SPEED_CONNECT = 1 FULL_SPEED_CONNECT = 2

HOST_INTERRUPT_STATUS_REG
Bit Position | Name | Description
0 | TRANS_DONE_BIT | Automatically set to 1 when a transaction is completed. Must be cleared by writing 1.
1 | RESUME_INT_BIT | Automatically set to 1 when resume state is detected. Must be cleared by writing 1.
2 | CONNECTION_EVENT_BIT | Automatically set to 1 when a connect or disconnect occurs. Must be cleared by writing 1.
3 | SOF_SENT_BIT | Automatically set to 1 when a SOF transmission occurs. Must be cleared by writing 1.

HOST_INTERRUPT_MASK_REG
Bit Position | Name | Description
0 | TRANS_DONE_BIT | Set to 1 to enable interrupt on transaction completion.
1 | RESUME_INT_BIT | Set to 1 to enable interrupt on resume detected.

Bit Position | Name | Description
2 | CONNECTION_EVENT_BIT | Set to 1 to enable interrupt on connect or disconnect event.
3 | SOF_SENT_BIT | Set to 1 to enable interrupt on SOF transmission.

HOST_RX_STATUS_REG
Bit Position | Name | Description
0 | CRC_ERROR_BIT | When set to 1, indicates CRC error detected on the last transaction.
1 | BIT_STUFF_ERROR_BIT | When set to 1, indicates bit stuff error detected on the last transaction.
2 | RX_OVERFLOW_BIT | When set to 1, indicates insufficient free space in RX fifo to accept entire data packet.
3 | RX_TIME_OUT_BIT | When set to 1, indicates no response from USB device.
4 | NAK_RXED_BIT | When set to 1, indicates NAK received from USB device.
5 | STALL_RXED_BIT | When set to 1, indicates STALL received from USB device.
6 | ACK_RXED_BIT | When set to 1, indicates ACK received from USB device.
7 | DATA_SEQUENCE_BIT | If the last transaction was of type IN_TRANS, then this bit indicates the sequence number of the last receive packet. DATA0 = 0, DATA1 = 1.

HOST_TX_TRANS_TYPE_REG
Bit Position | Name | Description
[1:0] | TRANSACTION_TYPE | SETUP_TRANS = 0 IN_TRANS = 1 OUTDATA0_TRANS = 2 OUTDATA1_TRANS = 3 These are the four basic types of transaction. The transaction types detailed in USB 1.1 (Setup, bulk, and isochronous) are composed of a series of one or more of these basic atomic transactions.

HOST_TX_LINE_CONTROL_REG

Bit Position | Name | Description
[1:0] | TX_LINE_STATE | When DIRECT_CONTROL_BIT=1,T X_LINE_STATE directly controls the state of the USB physical wires, where; TX_LINE_STATE [1] = D+ TX_LINE_STATE [0] = D-
2 | DIRECT_CONTROL_BIT | Set to 1 to allow direct control the state of the USB physical wires. Clear to 0 for normal operation.
3 | FULL_SPEED_LINE_POLARITY_BIT | Set to 1 to enable full speed line
| | polarity. That is J= differential
| | 1, K= differential 0.
| | Clear to zero to enable low
| | speed line poarity. That is J=
| | differential 0, K= differential 1.
| | If the host is communicating
| | with a full speed device, then
| | full speed line polarity should
| | be enabled. If the host is
| | communicating with a low
| | speed device directly then full
| | speed line polarity should be
| | disabled. If the host is
| | communicating with a low
| | speed device via a hub, then
| | full speed line polarity should
| | be enabled.
4 | FULL_SPEED_LINE_RATE_BIT | Set to 1 to enable full speed line
| | rate of 12Mbps. Clear to 0 to
| | enable low speed line rate of
| | 1.5Mbps. If the host is
| | communicating with a full
| | speed device, then full speed
| | line rate should be enabled. If
| | the host is communicating with
| | a low speed device full speed
| | line rate should be disabled.

HOST_TX_SOF_ENABLE_REG
Bit Position | Name | Description
0 | SOF_EN_BIT | If FULL_SPEED_LINE_POLARITY_BIT is set, then setting this bit to 1 to enables automatic transmission

Bit Position | Name | Description
| | of SOF tokens every 1mS. Note that SOF tokens will be transmitted at full speed line rate irrespective of the state of FULL_SPEED_LINE_RATE_BIT. If FULL_SPEED_LINE_POLARITY_BIT is clear, then setting this bit to 1 to enables automatic transmission of low speed EOP keep alive every 1mS. Transition from 0 to 1 causes transmission of resume state prior to EOP transmission. Note that this mode is only used when the host is connected directly to a low speed device. Clear to 0 to disable automatic SOF/EOP transmission, and allow any devices attached to the host to enter the suspend state.

HOST_TX_ADDR_REG
Bit Position | Name | Description
[6:0] | DEVICE_ADDRESS | USB Device address.

HOST_TX_ENDP_REG
Bit Position | Name | Description
[3:0] | ENDP_ADDRESS | Endpoint address.

HOST_FRAME_NUM_MSP_REG
Bit Position | Name | Description
[2:0] | FRAME_NUM_MSP | Most significant part of the frame number used for SOF transmission. That is FRAME_NUM_MSP = FRAME_NUM[10:8].

HOST_FRAME_NUM_LSP_REG
Bit Position | Name | Description
[7:0] | FRAME_NUM_LSP | Least significant part of the frame number used for SOF transmission. That is FRAME_NUM_LSP = FRAME_NUM[7:0].

HOST_SOF_TIMER_MSB_REG

Bit Position | Name | Description
[7:0] | HOST_SOF_TIMER_MSB | Most significant byte of the SOF timer used

Bit Position | Name | Description
| | for SOF transmission. Timer is incremented at 48MHz, thus there are 48000 ticks in a 1mS frame. This register can be used to calculate the number of ticks remaining in a frame. Trem = 0xbb - HOST_SOF_TIMER_MSB

HOST_RX_PID_REG
Bit Position | Name | Description
[3:0] | RECEIVE_PID | Packet identifier for the last packet received.

HOST_RX_ADDR_REG
Bit Position | Name | Description
[6:0] | RECEIVE_ADDRESS | Address from which the last receive packet was sent.

HOST_RX_ENDP_REG
Bit Position | Name | Description
[3:0] | RECEIVE_ENDP | End point from which the last receive packet was sent.

HOST_RX_FIFO_DATA
Bit Position | Name | Description
[7:0] | RX_FIFO_DATA | If the last transaction was an IN_TRANS, then the receive payload can be retrieved by reading RX_FIFO_DATA

HOST_TX_FIFO_DATA
Bit Position | Name | Description
[7:0] | TX_FIFO_DATA | Prior to requesting an OUTDATA0_TRANS or an OUTDATA1_TRANS , load transmit fifo with data by writing to TX_FIFO_DATA.

HOST_RX_FIFO_DATA_COUNT_MSB

Bit Position | Name | Description
[7:0] | FIFO_DATA_COUNT_MSB | MSByte of FIFO_DATA_COUNT. Indicates the number of data entries within the fifo.

HOST_RX_FIFO_DATA_COUNT_LSB
Bit Position | Name | Description
[7:0] | FIFO_DATA_COUNT_LSB | LSByte of FIFO_DATA_COUNT. Indicates the number of data entries within the fifo.

HOST_[T,R]X_FIFO_CONTROL
Bit Position | Name | Description
0 | FIFO_FORCE_EMPTY | Write only. Set to 1 to delete all the data samples within the fifo.

### USB Slave (Device)

Register Address | Name
0x40 | ENDPOINT0_CONTROL_REG
0x41 | ENDPOINT0_STATUS_REG
0x42 | ENDPOINT0_TRANSTYPE_STATUS_REG
0x43 | ENDPOINT0_NAK_TRANSTYPE_STATUS_REG
0x44 | ENDPOINT1_CONTROL_REG
0x45 | ENDPOINT1_STATUS_REG
0x46 | ENDPOINT1_TRANSTYPE_STATUS_REG
0x47 | ENDPOINT1_NAK_TRANSTYPE_STATUS_REG
0x48 | ENDPOINT2_CONTROL_REG
0x49 | ENDPOINT2_STATUS_REG
0x4a | ENDPOINT2_TRANSTYPE_STATUS_REG
0x4b | ENDPOINT2_NAK_TRANSTYPE_STATUS_REG

Register Address | Name
0x4c | ENDPOINT3_CONTROL_REG
0x4d | ENDPOINT3_STATUS_REG
0x4e | ENDPOINT3_TRANSTYPE_STATUS_REG
0x4f | ENDPOINT3_NAK_TRANSTYPE_STATUS_REG
0x50 | SC_CONTROL_REG
0x51 | SC_LINE_STATUS_REG
0x52 | SC_INTERRUPT_STATUS_REG
0x53 | SC_INTERRUPT_MASK_REG
0x54 | SC_ADDRESS
0x55 | SC_FRAME_NUM_MSP
0x56 | SC_FRAME_NUM_LSP
0x60 | EP0_RX_FIFO_DATA
0x61 | Reserved
0x62 | EP0_RX_FIFO_DATA_COUNT_MSB
0x63 | EP0_RX_FIFO_DATA_COUNT_LSB
0x64 | EP0_RX_FIFO_CONTROL_REG
0x70 | EP0_TX_FIFO_DATA
0x71 | Reserved
0x72 | Reserved
0x73 | Reserved
0x74 | EP0_TX_FIFO_CONTROL_REG
0x80 | EP1_RX_FIFO_DATA
0x81 | Reserved
0x82 | EP1_RX_FIFO_DATA_COUNT_MSB
0x83 | EP1_RX_FIFO_DATA_COUNT_LSB
0x84 | EP1_RX_FIFO_CONTROL_REG
0x90 | EP1_TX_FIFO_DATA
0x91 | Reserved
0x92 | Reserved
0x93 | Reserved
0x94 | EP1_TX_FIFO_CONTROL_REG
0xa0 | EP2_RX_FIFO_DATA
0xa1 | Reserved
0xa2 | EP2_RX_FIFO_DATA_COUNT_MSB
0xa3 | EP2_RX_FIFO_DATA_COUNT_LSB
0xa4 | EP2_RX_FIFO_CONTROL_REG
0xb0 | EP2_TX_FIFO_DATA
0xb1 | Reserved

Register Address | Name
0xb2 | Reserved
0xb3 | Reserved
0xb4 | EP2_TX_FIFO_CONTROL_REG
0xc0 | EP3_RX_FIFO_DATA
0xc1 | Reserved
0xc2 | EP3_RX_FIFO_DATA_COUNT_MSB
0xc3 | EP3_RX_FIFO_DATA_COUNT_LSB
0xc4 | EP3_RX_FIFO_CONTROL_REG
0xd0 | EP3_TX_FIFO_DATA
0xd1 | Reserved
0xd2 | Reserved
0xd3 | Reserved
0xd4 | EP3_TX_FIFO_CONTROL_REG

ENDPOINT[3..0]_CONTROL_REG
Bit Position | Name | Description
0 | ENDPOINT_ENABLE_BIT | Set to 1 to enable the endpoint. If endpoint is not enabled then it will not respond to any transactions. If endpoint is enabled, not ready, and not in isochronous mode, then all transactions will be NAK'd.
1 | ENDPOINT_READY_BIT | Set to 1 make the endpoint ready. If endpoint is enabled and ready then it can respond to a host inititiated transaction. Automatically cleared to 0 when transaction is complete.
2 | ENDPOINT_OUTDATA_SEQUENCE_BIT | If set to 1 then the endpoint will respond to a host IN request with a DATA1 packet, otherwise it will respond with a DATA0 packet.
3 | ENDPOINT_SEND_STALL_BIT | If set to 1 and endpoint is enabled, ready, and not in isochronous mode, then endpoint will send STALL in response to a host inititiated transaction.

Bit Position | Name | Description
4 | ENDPOINT_ISO_ENABLE_BIT | Set to 1 to enable isochronous transfers. In isochronous mode the endpoint does not send acknowledgements, nor does it expect to receive acknowledgements.

ENDPOINT[3..0]_STATUS_REG
Bit Position | Name | Description
0 | SC_CRC_ERROR_BIT | When set to 1, indicates CRC error detected on the last transaction.
1 | SC_BIT_STUFF_ERROR_BIT When set to 1, indicates bit stuff error | detected on the last transaction.
2 | SC_RX_OVERFLOW_BIT | When set to 1, indicates insufficient free space in RX fifo to accept entire data packet.
3 | SC_RX_TIME_OUT_BIT | When set to 1, indicates no response from USB host.
4 | SC_NAK_SENT_BIT | When set to 1, indicates NAK sent to USB host.
5 | SC_STALL_SENT_BIT | When set to 1, indicates STALL sent to USB host.
6 | SC_ACK_RXED_BIT | When set to 1, indicates ACK received from USB host.
7 | SC_DATA_SEQUENCE_BIT | If the last transaction was of type OUT_TRANS, then this bit indicates the sequence number of the last receive packet. DATA0 = 0, DATA1 = 1.

Note that SC_NAK_SENT_BIT refers to the last host inititiated transaction that occurred whilst the endpoint was enabled, but not ready. The other bits in this register are not effected by host transactions that are NAK'd, and they refer to the last transaction which
resulted in | ENDPOINT_READY_BIT being changed from 1 to 0.
SC_NAK_SENT_BIT is cleared to zero immediately after an enabled/ready transaction is completed. Note that the usb slave endpoint cannot NAK a host transmission when the endpoint is enabled and ready. So the NAK_SENT_BIT never refers to a transaction which resulted in ENDPOINT_READY_BIT being changed from 1 to 0

ENDPOINT[3..0]_TRANSTYPE_STATUS_REG
Bit Position | Name | Description
[1:0] | TRANSACTION_TYPE | SC_SETUP_TRANS = 0 SC_IN_TRANS = 1

Bit Position | Name | Description
| | SC_OUTDATA_TRANS = 2 This is the transaction type of the last transaction which resulted in ENDPOINT_READY_BIT being changed from 1 to 0

ENDPOINT[3..0]_NAK_TRANSTYPE_STATUS_REG
Bit Position | Name | Description
[1:0] | TRANSACTION_TYPE | SC_SETUP_TRANS = 0 SC_IN_TRANS = 1 SC_OUTDATA_TRANS = 2 This is the transaction type of the last transaction which resulted in a NAK being sent to the host.

SC_CONTROL_REG
Bit Position | Name | Description
0 | SC_GLOBAL_ENABLE_BIT | When cleared to 0, all endpoints are disabled, and the slave will not respond to any host inititiated transactions.
[2:1] | SC_TX_LINE_STATE | When SC_DIRECT_CONTROL_BIT=1 ,SC_TX_LINE_STATE directly controls the state of the USB physical wires, where; SC_TX_LINE_STATE [2] = D+ SC_TX_LINE_STATE [1] = D-
3 | SC_DIRECT_CONTROL_BIT | Set to 1 to allow direct control the state of the USB physical wires. Clear to 0 for normal operation.
4 | SC_FULL_SPEED_LINE_POLARITY_BIT | Set to 1 to enable full speed line polarity. That is J= differential 1, K= differential 0. Clear to zero to enable low speed line poarity. That is J= differential 0, K= differential 1.
5 | SC_FULL_SPEED_LINE_RATE_BIT | Set to 1 to enable full speed line rate of 12Mbps. Clear to 0 to enable low speed line rate of

Bit Position | Name | Description
| | 1.5Mbps.
6 | SC_CONNECT_TO_HOST_BIT | Controls the activation of the D+ and D- pull-ups. If set to 1, and FULL_SPEED_LINE_RATE is asserted, then the D+ line will be pulled high. If set to 1, and FULL_SPEED_LINE_RATE is de-asserted, then the D- line will be pulled high. If cleared to 0 then neither D+ or D- will be pulled high. The mechanism for controlling the pull up resistors is dependent on the USB PHY that is used.

SC_LINE_STATUS_REG
Bit Position | Name | Description
[1:0] | RX_LINE_STATE | The contents of RX_CONNECT_STATE_REG reflect the current connection state, where; RESET = 0 LOW_SPEED_CONNECT = 1 FULL_SPEED_CONNECT = 2
2 | VBUS_STATE | 1 = +5V USB supply present. 0 = +5V USB supply absent.

SC_INTERRUPT_STATUS_REG
Bit Position | Name | Description
0 | SC_TRANS_DONE_BIT | Set to 1 when a transaction is completed. Must be cleared by writing 1.
1 | SC_RESUME_INT_BIT | Set to 1 when resume state is detected. Must be cleared by writing 1.
2 | SC_RESET_EVENT_BIT | Set to 1 when a change in reset state (D+ and D- low) is detected. ie either entered or left reset state. Must be cleared by writing 1.
3 | SC_SOF_RECEIVED_BIT | Set to 1 when a SOF packet is received. Must be cleared by writing 1.
4 | SC_NAK_SENT_INT_BIT | Set to 1 when a NAK sent. Must be cleared by writing 1.

Bit Position | Name | Description
5 | VBUS_DET_INT_BIT | Set to 1 when a change VBUS presence is detected. Must be cleared by writing 1.

SC_INTERRUPT_MASK_REG
Bit Position | Name | Description
0 | SC_TRANS_DONE_BIT | Set to 1 to enable interrupt on transaction complete.
1 | SC_RESUME_INT_BIT | Set to 1 to enable interrupt on resume detected.
2 | SC_RESET_EVENT_BIT | Set to 1 to enable interrupt on reset detected.
3 | SC_SOF_RECEIVED_BIT | Set to 1 to enable interrupt on SOF received.
4 | SC_NAK_SENT_INT_BIT | Set to 1 to enable interrupt on NAK'd transaction.

SC_ADDRESS
Bit Position | Name | Description
[6:0] | DEVICE_ADDRESS | USB Device address.

SC_FRAME_NUM_MSP
Bit Position | Name | Description
[2:0] | SC_FRAME_NUM_MSP | Most significant part of the frame number received in the last SOF transmission. That is SC_FRAME_NUM_MSP = FRAME_NUM[10:8].

SC_FRAME_NUM_LSP
Bit Position | Name | Description
[7:0] | SC_FRAME_NUM_LSP | Least significant part of the frame number received in the last SOF transmission. That is SC_FRAME_NUM_LSP = FRAME_NUM[7:0].

EP[3..0]_TX_FIFO_DATA
Bit Position | Name | Description
[7:0] | TX_FIFO_DATA | Prior to receiving a IN_TRANS, load transmit fifo with data by writing to TX_FIFO_DATA.

EP[3..0]_RX_FIFO_DATA
Bit Position | Name | Description
[7:0] | RX_FIFO_DATA | After receiving an OUTDATA_TRANS, or a SETUP_TRANS, get receive data from fifo by reading from RX_FIFO_DATA.

EP[3..0]_RX_FIFO_DATA_COUNT_MSB
Bit Position | Name | Description
[7:0] | FIFO_DATA_COUNT_MSB | MSByte of FIFO_DATA_COUNT. Indicates the number of data samples within the fifo.

EP[3..0]_RX_FIFO_DATA_COUNT_LSB
Bit Position | Name | Description
[7:0] | FIFO_DATA_COUNT_LSB | LSByte of FIFO_DATA_COUNT. Indicates the number of data samples within the fifo.

EP[3..0]_[T,R]X_FIFO_CONTROL
Bit Position | Name | Description
0 | FIFO_FORCE_EMPTY | Write only. Set to 1 to delete all the data samples within the fifo.

5

# Clocks

Name | Source | Rates (MHz) | Remarks | Description
Max | Min | Res
usbClk | Input Pad | 48.024 | 47.976 | - | Duty cycle 50/50. | USB system clock.
clk_i | Input Pad | 240 | UsbClk/2 | | Duty cycle 50/50. | Wishbone bus clock.

Table 1: List of clocks

Several Development kits, such as the Altera Nios Development Kit Cyclone Edition, come with a 50MHz oscillator. Although the Cyclone PLL in the NIOS Development Kit can be used to derive a 48.076923MHz clock, and this complies with the low speed frequency tolerance (+/- 0.25%), it is not sufficient for full speed operation where a +/-0.05% frequency tolerance is required. The 48MHz socketed half can oscillator on the NIOS Development Kit can be replaced with a 50MHz oscillator (eg ECS ECS-2200B-480, Digikey part number XC280-ND)

6

# IO Ports

Port | Width | Direction | Description
usbClk | 1 | input | usb logic clock. 48MHz +/- 0.25%
clk_i | 1 | input | WISHBONE clock input. Can be asynchronous to usbClk. 24MHz <= clk_i <= 240MHz
rst_i | 1 | input | WISHBONE reset. Synchronous to clk_i. Resets all logic.
address_i | 8 | input | WISHBONE address input
data_i | 8 | input | WISHBONE data input
data_o | 8 | output | WISHBONE data output
writeEn | 1 | input | WISHBONE write enable
strobe_i | 1 | input | WISHBONE strobe input
ack_o | 1 | output | WISHBONE acknowledge output
hostSOFSentIntOut | 1 | output | Host SOF sent interrupt
hostConnEventIntOut | 1 | output | Host connection event interrupt
hostResumeIntOut | 1 | output | Host resume interrupt
hostTransDoneIntOut | 1 | output | Host transaction done interrupt
slaveSOFRxedIntOut | 1 | output | SlaveSOF received interrupt
slaveResetEventIntOut | 1 | output | Slave reset event interrupt
slaveResumeIntOut | 1 | output | Slave resume interrupt
slaveTransDoneIntOut | 1 | output | Slave transaction done interrupt
slaveNAKSentIntOut | 1 | output | Slave NAK sent interrupt
USBWireDataIn | 2 | input | USB wire differential data input USBWireDataIn[1] = D+ USBWireDataIn[0] = D-
USBWireDataOut | 2 | output | USB wire differential data output USBWireDataOut[1] = D+ USBWireDataOut[0] = D-
USBWireDataOutTick | 1 | output | Debug output. 6MHz in full speed mode, 750KHz in low speed mode.
USBWireDataInTick | 1 | output | Debug output. 6MHz in full speed mode, 750KHz in low speed mode.
USBWireCtrlOut | 1 | output | USB tansmit output enable. Connect to OE pin on USB PHY (eg invert and connect to OE_n on USB1T11A)

Port | Width | Direction | Description
USBFullSpeed | 1 | output | USB full speed enable. 1 = Full speed, 0 = low speed. Connect to FULL_SPEED pin on USB PHY. Typically used to control the USB line edge rate, which is different or full and low speed. (eg connect to SPEED on USB1T11A)
USBDPlusPullup | 1 | output | Enable USB device D+ 1.5K pull-up resistor. 1 = enable, 0 = disable. (eg connect to ISP1102 SOFTCON pin). Note that this output is only used in slave mode.
USBDMinusPullup | 1 | output | Enable USB device D- 1.5K pull-up resistor. 1 = enable, 0 = disable. Note that this output is only used in slave mode, and is only required for implementations that require low speed support.
VBusDetect | 1 | input | USB +5V voltage detector. 1 = +5V present. (eg connect to ISP1102 VBUSDET pin). Note that this input is only used in slave mode.

Table 2: List of IO ports

7

# Wishbone Datasheet

WISHBONE DATASHEET
for USBHostSlave IP Core
Description | Specification
General Description: | 8-bit slave input and output port
Supported cycles: | SLAVE READ/WRITE
Data port Size: | 8-bit
Data port granularity: | 8-bit
Data port, max operand size: | 8-bit
Data transfer ordering: | N/A
Data transfer sequencing: | Undefined
Supported signal list and cross reference to equivalet WISHBONE signals: | Signal Name | WISHBONE Equiv.
| address_i | ADR_I
| data_i[7:0] | DAT_I()
| data_o[7:0] | DAT_O()
| we_i | WE_I
| strobe_i | STB_I
| ack_o | ACK_O
| clk_i | CLK_I
| rst_i | RST_I

Table 3: WISHBONE data sheet

8

# Resource Utilization

Design Entity | Logic Cells | Memory bits
USBHostControl | 508 | 0
USBSlaveControl | 545 | 0
USBSerialInterfaceEngine | 984 | 0
WishBoneBI | 49 | 0
HostSlaveMux | 16 | 0
8 slave FIFOs each 64x8-bit | 412 | 4096
2 host FIFOs each 64x8-bit | 103 | 1024
USBHostSlave (top level) | 2617 | 5120

Table 4 Resource utilization for Altera CycloneEP1C20

9

# USB Transceivers

The core must be used with a USB transciver that is capable of driving the USB cable, and complies with the USB 1.1 specification. There are many options available, one of the simplest is the Fairchild USB1T11A. The USB1T11A has seperate pins for transmit and receive paths, and is available in a large SOIC package (nice for prototyping and cheap PCBs), and a very small (3mm x 3mm) MLP package. The USB1T11A will connect directly to the core apart from an inverter between ' USBWireCtrlOut' and USB1T11A OEn.
Other parts such as the Philips ISP1105 offer more features such as larger I/O voltage range, and soft connect. The ISP1105 and many other USB transcievers use a single pair of pins for transmit and receive. Thus a tri-state buffer must be implemented in order to connect the two seperate transmit receive pairs between the core and the transceiver, with 'USBWireCtrlOut' used to control the tri-state buffer output enable.

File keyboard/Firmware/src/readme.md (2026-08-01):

# Decent MegaXE

*A 60% keyboard designed for the MegaXE FPGA retro computer*

* Keyboard Maintainer: [Bertrand Le roy](https://github.com/bleroy/3d-junkyard/blob/main/DecenTKL/)
* Hardware Supported: Decent MegaXE (RP2040 based)
* Hardware Availability: Custom built but open-source

Make example for this keyboard (after setting up your QMK build environment):

```
qmk compile -kb decent/megaxe -km default
```

Flashing example for this keyboard:

```
qmk flash -kb decent/megaxe -km default
```

See the [build environment setup](https://docs.qmk.fm/#/getting_started_build_tools) and the [make instructions](https://docs.qmk.fm/#/getting_started_make_guide) for more information. Brand new to QMK? Start with our [Complete Newbs Guide](https://docs.qmk.fm/#/newbs).

## Bootloader

Press the escape key or the button on the back of the Pi while connecting the keyboard.

If the keyboard has previously been flashed with a version of this firmware, it can be put into bootloader mode by pressing both shift keys and 'B'.
The keyboard then appears as a disk volume and can be flashed by dragging and dropping the new `.uf2` firmware file onto its root.

## Special commands

`[Control]+[Atari] + 1`: Toggle RGB lighting
`[Control]+[Atari] + Up`: Next RGB effect
`[Control]+[Atari] + Down`: Previous RGB effect
`[Control]+[Atari] + X`: Change RGB hue
`[Control]+[Atari] + S`: Lower RGB brightness
`[Control]+[Atari] + W`: Raise RGB brightness
`[Control]+[Atari] + Left`: Lower RGB animation speed
`[Control]+[Atari] + Right`: Raise RGB animation speed

`[Both shifts] + B`: go into bootloader mode without unplugging the keyboard
`[Both shifts] + \`: delete configuration data

## Layout

```
     /─────/─────/─────/─────/─────/─────/─────/─────/─────/
    /F1   /F2   /F3   /F4   /Help /Start/Slect/Optin/Reset/
   /─────/─────/─────/─────/─────/─────/─────/─────/─────/
┌───┬───┬───┬───┬───┬───┬───┬───┬───┬───┬───┬───┬───┬───────┐
│Esc│ 1!│ 2@│ 3#│ 4%│ 5%│ 6^│ 7&│ 8*│ 9(│ 0)│ - │ = │ Backsp│
├───┴─┬─┴─┬─┴─┬─┴─┬─┴─┬─┴─┬─┴─┬─┴─┬─┴─┬─┴─┬─┴─┬─┴─┬─┴─┬─────┤
│ Tab │ Q │ W │ E │ R │ T │ Y │ U │ I │ O │ P │ [{│ ]}│  \| │
├─────┴┬──┴┬──┴┬──┴┬──┴┬──┴┬──┴┬──┴┬──┴┬──┴┬──┴┬──┴┬──┴─────┤
│ Caps │ A │ S │ D │ F │ G │ H │ J │ K │ L │ ;:│ '"│  Enter │
├──────┴─┬─┴─┬─┴─┬─┴─┬─┴─┬─┴─┬─┴─┬─┴─┬─┴─┬─┴─┬─┴─┬─┴────────┤
│ Shift  │ Z │ X │ C │ V │ B │ N │ M │ ,<│ .>│ /?│    Shift │
├────┬───┴┬──┴─┬─┴───┴───┴───┴───┴───┴──┬┴───┼───┴┬────┬────┤
│Ctrl│ GUI│ Brk│                        │  ← │  ↑ │  ↓ │  → │
└────┴────┴────┴────────────────────────┴────┴────┴────┴────┘
```

`[Control] + ←`: Home
`[Control] + →`: End
`[Control] + ↑`: PgUp
`[Control] + ↓`: PgDn

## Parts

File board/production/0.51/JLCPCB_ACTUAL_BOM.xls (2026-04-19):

Comment | Designator | Footprint | JLCPCB Part#(optional)
0.5A | F1,F4,F8,F7,F5,F3,F6 | R_0603_1608Metric | C269152
SN74CB3T16211DGVR | U31,U33,U27,U29 | DGV56 | C2674751
SMAJ5.0A | D1 | D_SMA | C83329
22 | R68,R62,R93,R81,R103,R82,R98,R107,R67,R69,R100,R52,R72 | R_0603_1608Metric | C23345
0.1uF | C97,C78,C87,C43,C93,C61,C44,C58,C96,C76,C31,C86,C71,C62,C67,C70,C85,C66,C100,C27,C10,C56,C79,C73,C95,C57,C88,C98,C69,C91,C48,C81,C72,C68,C75,C8,C92,C63,C24,C60,C77,C53,C40,C28,C29,C55,C25,C46,C64,C89 | C_0603_1608Metric | C108079
2.2uF | C54,C6,C21,C4,C83,C82,C18,C51,C1 | C_0603_1608Metric | C415535
47k | R22,R36,R37,R16,R10,R21 | R_0603_1608Metric | C25819
10uF | C9,C94,C30,C52,C39,C14,C37 | C_0805_2012Metric | C1713
PCA9546APWR | U22 | TSSOP-16_L5.0-W4.4-P0.65-LS6.4-BL | C400705
70@100MHz | FB6,FB5,FB7,FB3,FB2,FB1,FB4 | L_0805_2012Metric | C1012
300SP1J1BLKM7QE | SW1 | SW-TH_300SP1J1BLKM7QE | C22449118
CR2032 | BT1 | BAT-TH_BS-05-A1BJ001 | C964752
4k7 | R78,R11,R77,R14,R49,R15,R54,R106,R85,R108,R63,R32,R53,R3,R12 | R_0603_1608Metric | C23162
2k7 | R13,R73,R29,R79,R70,R30,R71 | R_0603_1608Metric | C13167
FPGA JTAG | J21 | IDC-Header_2x05_P2.54mm_Vertical | C5665
TYPE-C-31-M-19 | USB2,USB1 | USB-C-TH_TYPE-C-31-M-19 | C2689968
SD_Card_Receptacle | Card2 | SD_TE_2041021 | C125615
1m | R33,R8,R1,R19,R9,R96 | R_0603_1608Metric | C22935
1k | R80,R48,R44,R31,R83,R43,R7,R89,R95,R59,R46,R41,R42,R26,R50,R58 | R_0603_1608Metric | C21190
TPD4E02B04DQA | U2,U39,U38,U1,U40,U11,U36,U3 | USON-10_2.5x1.0mm_P0.5mm | C106794
10k | R84,R23,R51,R86,R92,R25,R105,R20,R99,R94,R47,R97,R91,R87,R90,R66,R64,R61,R65,R24,R60,R88,R27 | R_0603_1608Metric | C130232
STM USART TTL | J12 | PinHeader_1x06_P2.54mm_Vertical | C37208
470 | R6,R2 | R_0603_1608Metric | C23179
270 | RN2,RN1 | R_Array_Convex_4x0603 | C1966
47nF | C36,C13,C49,C65,C33,C59,C47,C11 | C_0603_1608Metric | C1622
THS7316DR | U21 | SOIC-8_L5.0-W4.0-P1.27-LS6.1-BL | C544774
HDD | Card1 | TF-SMD_472192001 | C164170
18pF | C20,C101,C19,C102 | C_0603_1608Metric | C107040
DualJoy | J15,J11 | DualDSub9Male | C5431655
TPS62903RPJR | U18,U14,U15 | VQFN-HR-9_L2.0-W1.5-P0.50-TL | C2866502
4k7 | RN5,RN3,RN4,RN6,RN11,RN9 | R_Array_Convex_4x0603 | C1980
PBI Option | J8 | PinSocket_2x04_P2.54mm_Vertical | C225519
PCM5102A | U17 | TSSOP-20_4.4x6.5mm_P0.65mm | C107671
STM SWD | J9 | PinHeader_1x05_P2.54mm_Vertical | C225480
USB2514B_Bi | U37 | QFN-36-1EP_6x6mm_P0.5mm_EP3.7x3.7mm | C16251
PJ-325C5-G | J1 | Jack_3.5mm_CUI_SJ1-3535NG_Horizontal | C692438
100uF | C7,C74,C99,C5,C45,C80 | C_1206_3216Metric | C6119961
10nF | C23,C35,C90,C12 | C_0603_1608Metric | C1589
ESP PGM | J18 | PinHeader_1x05_P2.54mm_Vertical | C225480
32k4 | R28 | R_0603_1608Metric | C13187
22uF | C50,C17,C34,C41 | C_0805_2012Metric | C29277
73725-1180RLF | J24,J25,J20 | USB-A-FLAG | C26235
STM BOOT0 | JP1 | PinHeader_1x03_P2.54mm_Vertical | C49257
1uF | C84,C22 | C_0805_2012Metric | C28323
75 | R56,R57,R55 | R_0603_1608Metric | C4275
FPGA GPIO | J17 | PinSocket_1x07_P2.54mm_Vertical | C225482
10CL040f484 | U30 | FBGA484_WIREBOND_A-2.40_INT | C1521940
100 | R38,R39 | R_0603_1608Metric | C22775
1uF/DFE252012F-1R0M=P2 | L1,L3,L2 | L_1008_2520Metric | C435392
47k | RN12,RN8,RN13 | R_Array_Convex_4x0603 | C102673
2.2nF | C2,C3 | C_0603_1608Metric | C77033
SPI CFG | J14 | PinSocket_2x03_P2.54mm_Vertical | C225518
16pF | C15,C16 | C_0603_1608Metric | C327125
4.7nF | C38,C32,C26,C42 | C_0603_1608Metric | C85980
PJ-325C5-BL | J2 | Jack_3.5mm_CUI_SJ1-3535NG_Horizontal | C2884946
TPD8E003DQDR | U16,U4,U8,U7,U6,U12,U13,U5,U20,U25,U9 | DQD8_1P2X0P4 | C2867469
5k1 | R5,R17,R4,R18 | R_0603_1608Metric | C23186
I2C | J26 | PinHeader_2x02_P2.54mm_Vertical | C225517
25MHz | Y6,Y3 | Crystal_SMD_3225-4Pin_3.2x2.5mm | C337661
USB_A | J19 | USB_A_Molex_105057_Vertical | C586225
74LVC1G17 | U10 | SOT-23-5 | C7836
Conn_01x01 | J7 | PinSocket_1x01_P2.54mm_Vertical | C492400
100k | R104,R109,R40,R101,R102 | R_0603_1608Metric | C25803
Si5351A-B-GT | Y4,Y7 | MSOP-10_3x3mm_P0.5mm | C529366
12k | R110 | R_0603_1608Metric | C22790
STM32F407ZGTx | U19 | LQFP-144_20x20mm_P0.5mm | C19156
1N4148WS | D2 | D_SOD-323 | C2128
22 | RN7,RN10 | R_Array_Convex_4x0603 | C12008
0.1A | F2 | R_0603_1608Metric | C3760613
32.768KHz | Y2 | Crystal_SMD_3215-2Pin_3.2x1.5mm | C32346
26k1 | R35,R45 | R_0603_1608Metric | C23356
IS61WV25616BLL-10BLI | U28 | TF-BGA-48L_ISI | C1349085
IS61WV102416BLL-10BLI | U32 | TF-BGA-48L_ISI | C1348743
ASE-27MHz | Y5 | Oscillator_SMD_Abracon_ASE-4Pin_3.2x2.5mm | C37635418
M25PX32-VMW | U23 | SOIC-8_5.3x6.2mm_P1.27mm | C6215302
DE15_Pins_HighDensity_MountingHoles | J6 | DSUB-15-HD_Pins_Horizontal_P2.29x2.54mm_EdgePinOffset8.35mm_Housed_MountingHolesOffset10.89mm | C7498158
SPI SEL | J16 | PinHeader_1x03_P2.54mm_Vertical | C49257
8MHz | Y1 | Crystal_SMD_3225-4Pin_3.2x2.5mm | C2924617
2N7002 | Q2 | SOT-23 | C8545
24MHz | Y8 | Crystal_SMD_3225-4Pin_3.2x2.5mm | C5122304
FSUSB42UMX-TP | U24 | XQFN-10_L1.8-W1.4-P0.40-TL | C42370490
1k8 | R75,R74,R76 | R_0603_1608Metric | C4177
STM GPIO | J10 | PinSocket_1x07_P2.54mm_Vertical | C225482
Conn_01x04_Pin | J22 | PinHeader_1x04_P2.54mm_Vertical | C152150
ESP JTAG | J23 | IDC-Header_2x05_P2.54mm_Vertical | C5665
BCX51 | Q1 | SOT-89-3 | C475643
HDMI_A | J4 | HDMI-SMD_19P-P0.50-H-F | C138388
ESP32-WROVER-E-N8R8 | U34 | WIFI-SMD_ESP32-WROVER-IE8MB | C529589
40k2 | R34 | R_0603_1608Metric | C12447
AS4C16M16SA | U35 | TSOP-II-54_22.2x10.16mm_P0.8mm | C62246

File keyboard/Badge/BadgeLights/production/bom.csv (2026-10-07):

Designator | Footprint | Quantity | Value | LCSC Part #
C24, C25, C26, C27, C28, C29, C30, C31 | 0805 | 8 | 100nF
D1, D2, D3, D4, D5, D6, D7, D8 | LED_WS2812B_PLCC4_5.0x5.0mm_P3.2mm | 8 | WS2812B
PRG | PinHeader_2x03_P2.54mm_Vertical | 1 | Conn_02x03_Odd_Even
PWR | PinHeader_1x02_P2.54mm_Vertical | 1 | Conn_01x02_Pin
QWIIC_2, QWIIC | PinHeader_1x04_P2.54mm_Vertical | 2 | Conn_01x04
R1 | R_Axial_DIN0207_L6.3mm_D2.5mm_P7.62mm_Horizontal | 1 | R
RGB OUT | PinHeader_1x03_P2.54mm_Vertical | 1 | Conn_01x03_Pin
U1 | DIP-8_W7.62mm | 1 | ATtiny85-20P

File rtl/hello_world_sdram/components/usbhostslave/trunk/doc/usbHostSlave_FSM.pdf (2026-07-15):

# Active-HDL PDF Export

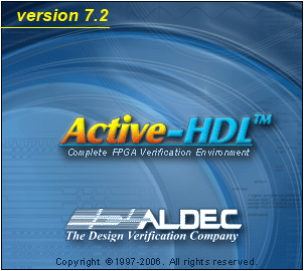
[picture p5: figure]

Copyright 2006 ALDEC, Inc. Henderson, NV USA All Rights Reserved.

ALDEC, Inc. homepage http://www.aldec.com

Contents

### 1 Table of Contents

2 usbhostslave

2.1 usbTxWireArbiter.asf

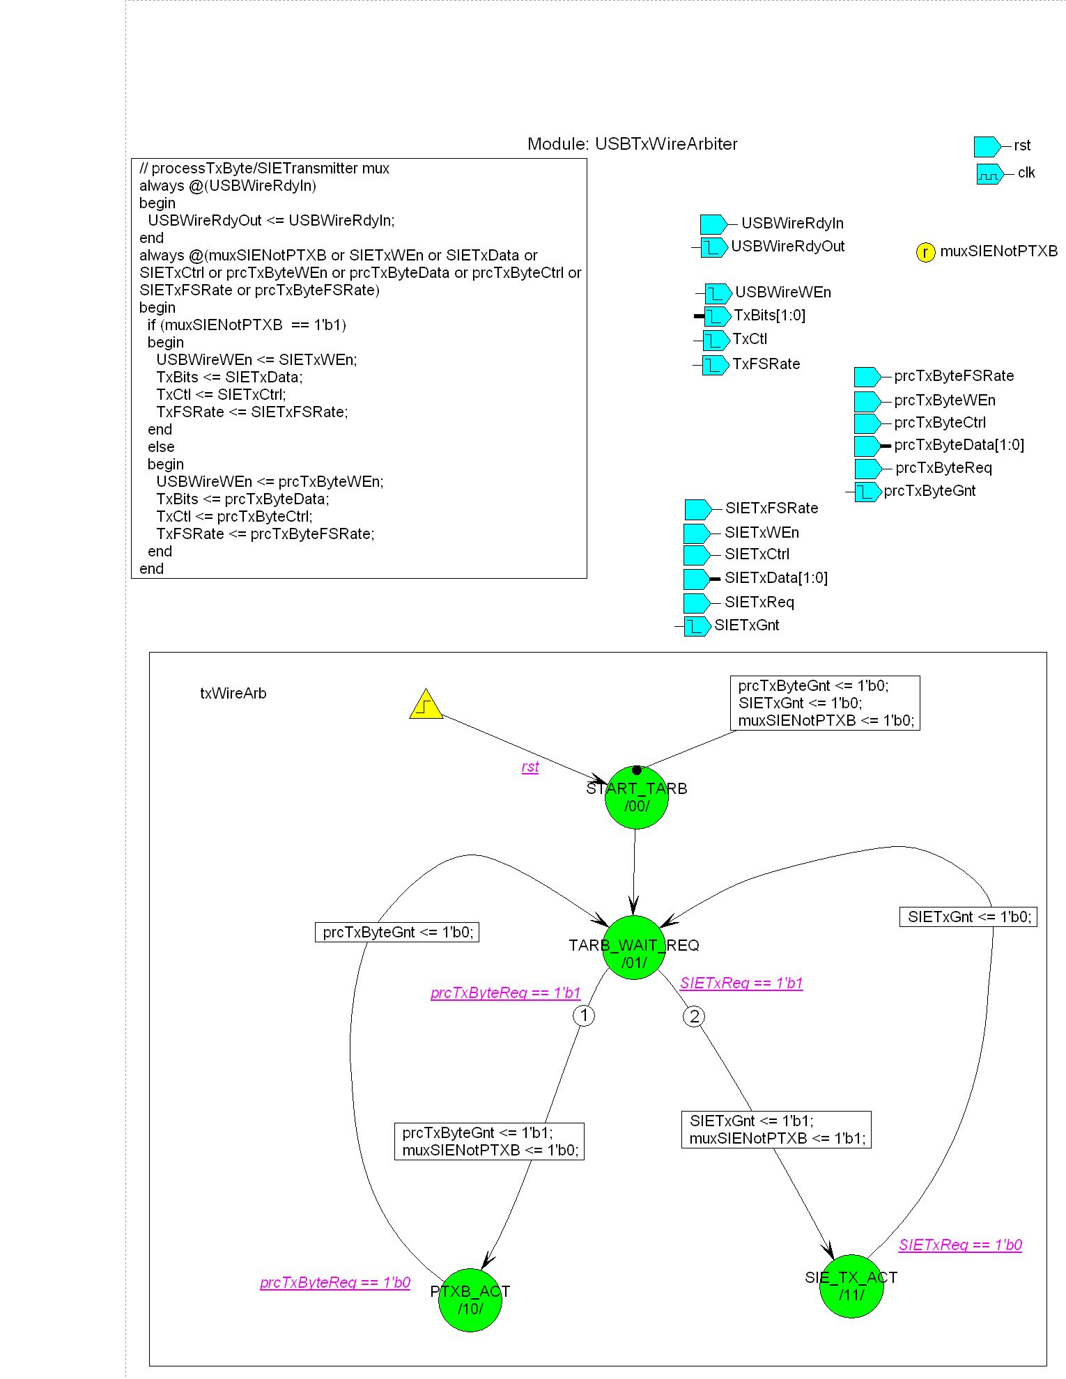
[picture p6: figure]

1

2.2 directcontrol.asf

2

2.2.1 DRCT_CNTL

3

2.2.2 IDLE

4

2.3 getpacket.asf

5

2.3.1 PROC_PKT

6

2.3.1.1 DATA

7

2.3.1.1.1 LOOP

8

2.4 hctxportarbiter.asf

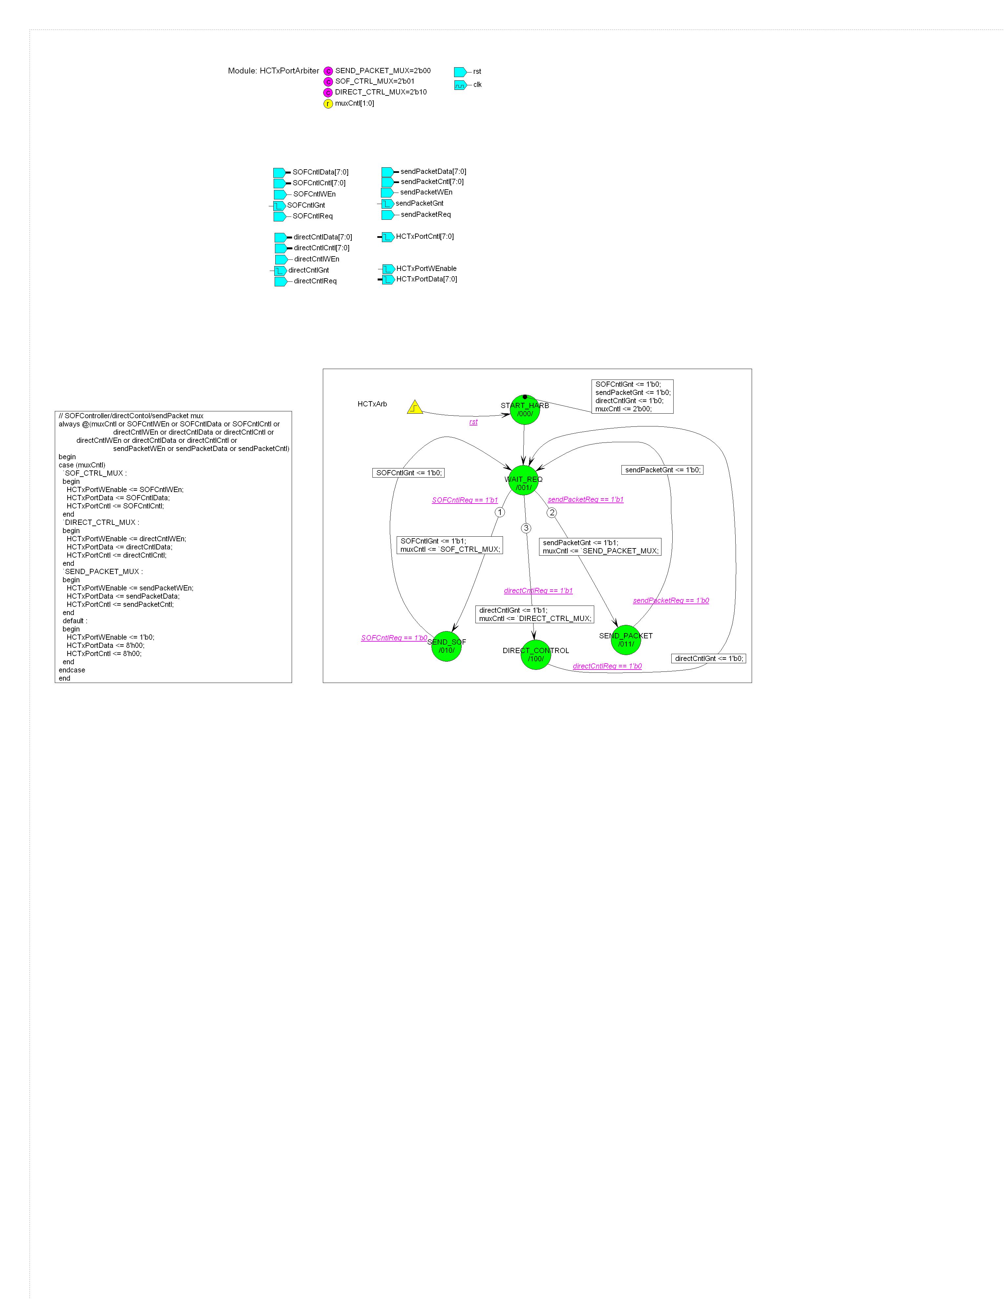
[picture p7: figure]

9

2.5 hostcontroller.asf

10

2.5.1 SETUP

11

2.5.2 IN

12

2.5.3 OUT0

13

2.5.4 OUT1

14

2.6 processRxBit.asf

15

2.6.1 IDLE

16

2.6.2 DATA_RX

17

2.6.2.1 DATA

18

2.6.2.2 BYTE

19

2.6.2.3 ERROR

20

2.6.3 RES_RX

21

2.6.4 RES_END

22

2.7 processRxByte.asf

23

2.7.1 CHK_PID

24

2.7.1.1 FIRST_BYTE

25

2.7.2 HSHAKE

26

2.7.3 TOKEN

27

2.7.4 DATA

28

2.7.5 IDLE

29

2.7.6 CHK_SYNC

30

2.8 processTxByte.asf

31

2.8.1 SEND_BYTE

32

2.8.2 STOP

33

2.8.3 LS_START

34

2.9 sctxportarbiter.asf

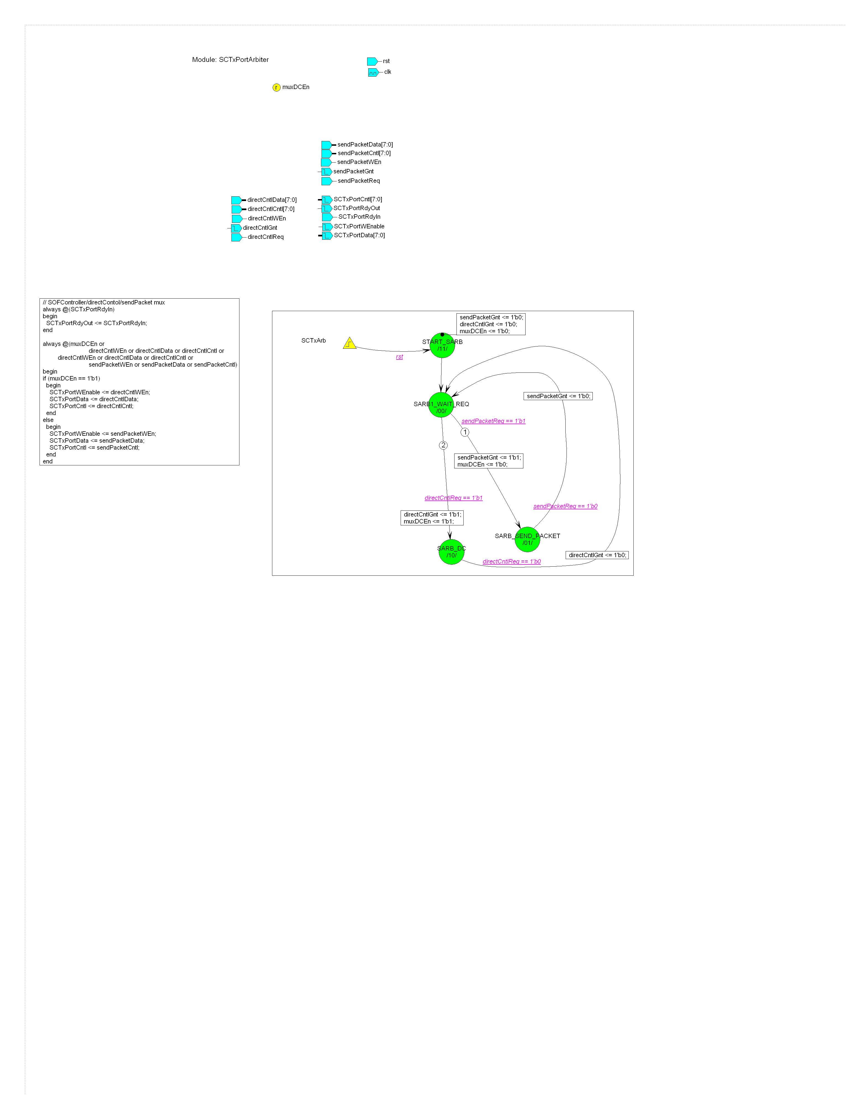
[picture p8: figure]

35

2.10 sendpacket.asf

36

2.10.1 SEND_PID

37

2.10.2 OUT_IN_SETUP

38

2.10.3 SEND_SOF

39

2.10.4 DATA0_DATA1

40

2.10.5 LS_EOP

41

2.11 sendpacketarbiter.asf

42

2.12 sendpacketcheckpreamble.asf

43

2.12.1 PREAM_PKT

44

2.12.2 REG_PKT

45

2.13 siereceiver.asf

46

2.13.1 DISCNCT

47

2.13.2 WAIT_FS_CONN

48

2.13.3 WAIT_LS_CONN

49

2.13.4 LS_CONN

50

2.13.5 FS_CONN

51

2.13.6 WAIT_LS_DIS

52

2.13.7 WAIT_FS_DIS

53

2.14 SIETransmitter.asf

54

2.14.1 RES_ST

55

2.14.2 DIR_CTL

56

2.14.3 PKT_ST

57

2.14.3.1 SPCL

58

2.14.3.2 DATA

59

2.14.3.2.1 PID

60

2.14.3.2.2 CRC

61

2.14.3.2.3 DATA

62

2.14.3.3 HS

63

2.14.3.4 TKN

64

2.14.3.4.1 PID

65

2.14.3.4.2 BYTE1

66

2.14.3.4.3 CRC

67

2.14.4 TX_LS_EOP

68

2.15 slavecontroller.asf

69

2.15.1 GET_TOKEN

70

2.15.2 SETUP_OUT

71

2.15.3 IN

72

2.15.3.1 RESP

73

2.15.4 START

74

2.16 slaveDirectcontrol.asf

75

2.16.1 DRCT_CNTL

76

2.16.2 IDLE

77

2.17 slaveGetpacket.asf

78

2.17.1 PROC_PKT

79

2.17.1.1 DATA

80

2.17.1.1.1 LOOP

81

2.18 slaveSendpacket.asf

82

2.18.1 SP_SEND_PID

83

2.18.2 SP_D0_D1

84

2.19 sofcontroller.asf

85

2.20 softransmit.asf

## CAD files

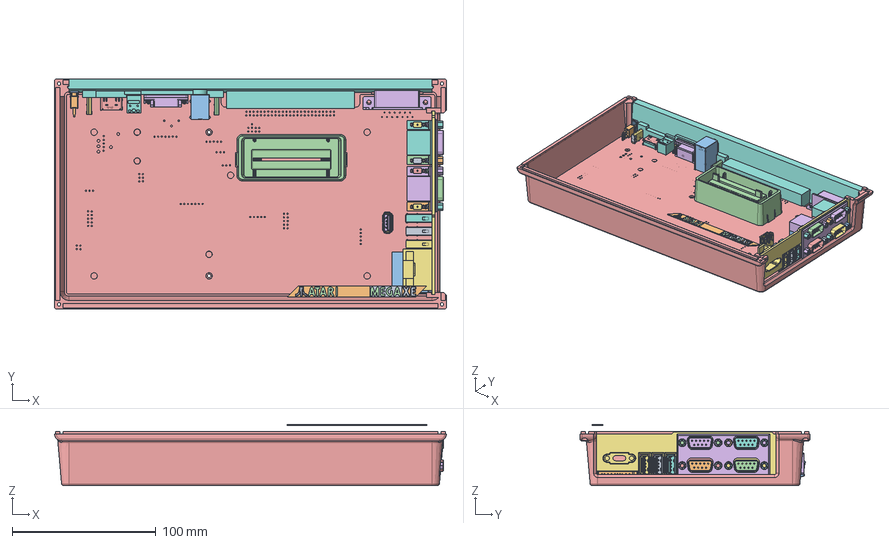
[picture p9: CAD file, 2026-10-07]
enclosure/MegaXE_case.FCStd
272.8 x 160.0 x 42.5 mm
Badge_copper
Badge_soldermask
Badge_soldermask001
Badge_PCB
Case bottom
Joystick port filler
Right ports panel
Back ports panel
SW-TH_SA-0-102-C04-0004-WP002
SW-TH_SA-0-102-C04-0004-WP003
SW-TH_SA-0-102-C04-0004-WP004
USB-C-TH_TYPE-C-31-M-004
USB-C-TH_TYPE-C-31-M-005
USB-C-TH_TYPE-C-31-M-006
USB-C-TH_TYPE-C-31-M-007
USB-C-TH_TYPE-C-31-M-008
USB-C-TH_TYPE-C-31-M-009
USB-C-TH_TYPE-C-31-M-010
USB-C-TH_TYPE-C-31-M-011
USB-C-TH_TYPE-C-31-M-012
USB-C-TH_TYPE-C-31-M-013
USB-C-TH_TYPE-C-31-M-014
USB-C-TH_TYPE-C-31-M-015
USB-C-TH_TYPE-C-31-M-016
USB-C-TH_TYPE-C-31-M-017
USB-C-TH_TYPE-C-31-M-018
USB-C-TH_TYPE-C-31-M-019
USB-C-TH_TYPE-C-31-M-020
SD-SMD_SD-006M002
SD-SMD_SD-006M003
SD-SMD_SD-006M004
SD-SMD_SD-006M005
SD-SMD_SD-006M006
SD-SMD_SD-006M007
SD-SMD_SD-006M008
DSUB-TH_HYC33-VGA18A-158
DSUB-TH_HYC33-VGA18A-159
DSUB-TH_HYC33-VGA18A-160
DSUB-TH_HYC33-VGA18A-161
DSUB-TH_HYC33-VGA18A-162
DSUB-TH_HYC33-VGA18A-163
DSUB-TH_HYC33-VGA18A-164
DSUB-TH_HYC33-VGA18A-165
DSUB-TH_HYC33-VGA18A-166
DSUB-TH_HYC33-VGA18A-167
DSUB-TH_HYC33-VGA18A-168
DSUB-TH_HYC33-VGA18A-169
DSUB-TH_HYC33-VGA18A-170
DSUB-TH_HYC33-VGA18A-171
DSUB-TH_HYC33-VGA18A-172
DSUB-TH_HYC33-VGA18A-173
DSUB-TH_HYC33-VGA18A-174
DSUB-TH_HYC33-VGA18A-175
DSUB-TH_HYC33-VGA18A-176
DSUB-TH_HYC33-VGA18A-177
DSUB-TH_HYC33-VGA18A-178
DSUB-TH_HYC33-VGA18A-179
DSUB-TH_HYC33-VGA18A-180
DSUB-TH_HYC33-VGA18A-181
DSUB-TH_HYC33-VGA18A-182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

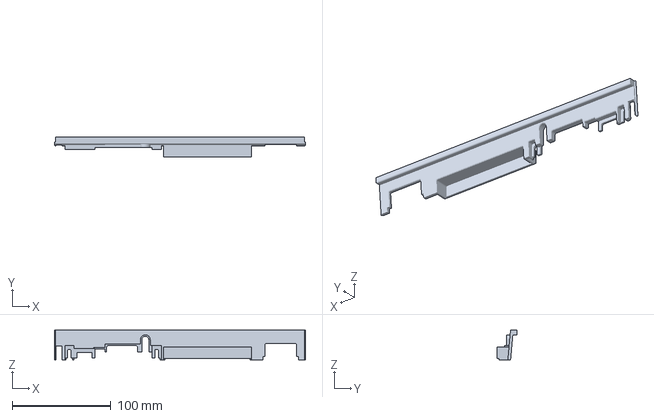
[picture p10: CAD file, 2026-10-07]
enclosure/MegaXE-Case-Back-panel.3mf
254.4 x 20.6 x 30.0 mm

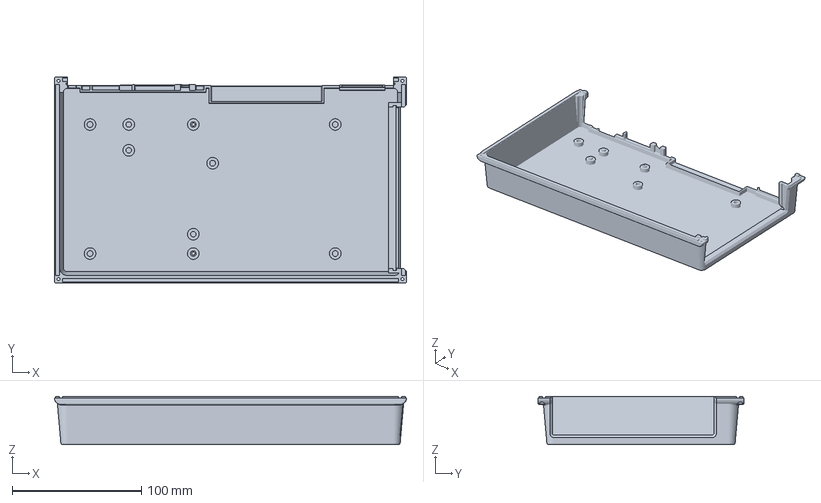
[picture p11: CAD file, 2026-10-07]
enclosure/MegaXE-Case-Bottom.3mf
272.8 x 160.0 x 37.5 mm

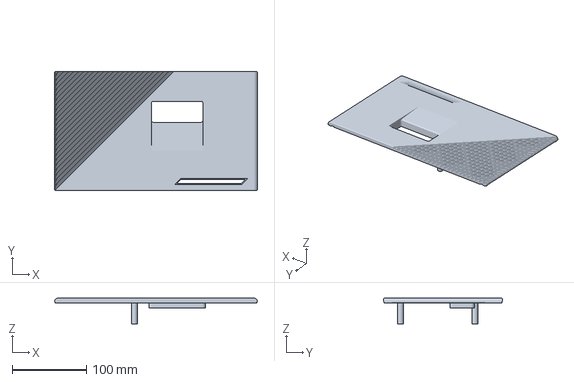
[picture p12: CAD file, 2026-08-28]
enclosure/MegaXE-Case-Top.3mf
272.8 x 160.0 x 34.9 mm

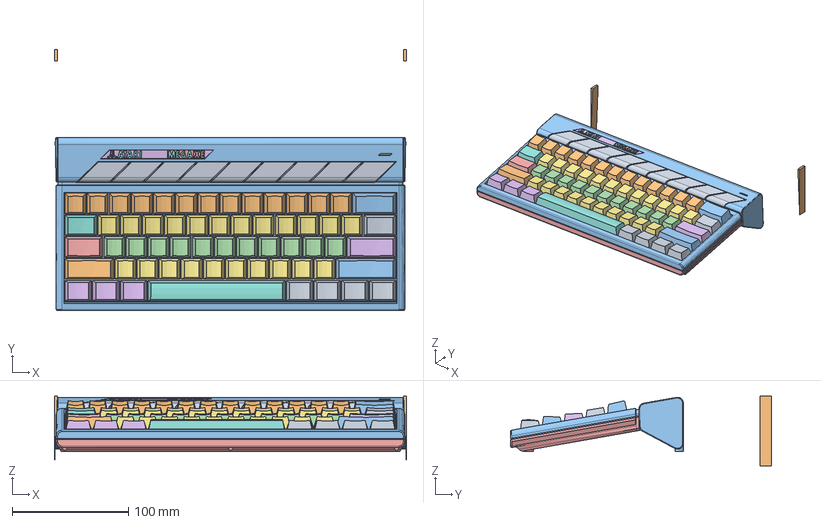
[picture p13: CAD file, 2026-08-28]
enclosure/MegaXE_keyboard_case.FCStd
303.0 x 224.9 x 60.0 mm
MegaXE-plate_PCB
USB_C_Receptacle_16P_TopMnt_Horizontal_GCT_USB4105-xx-A
PinHeader_1x04_P254mm_Horizontal
MegaXE-keyboard_PCB
Badge_copper
Badge_soldermask
Badge_soldermask001
Badge_PCB
Console key
Master sketches
Top
Power LED window
Bottom
OEM002
OEM004
OEM Space Bar
OEM005
OEM007
OEM009
OEM011
OEM013
OEM015
OEM017
OEM019
OEM021
OEM023
OEM025

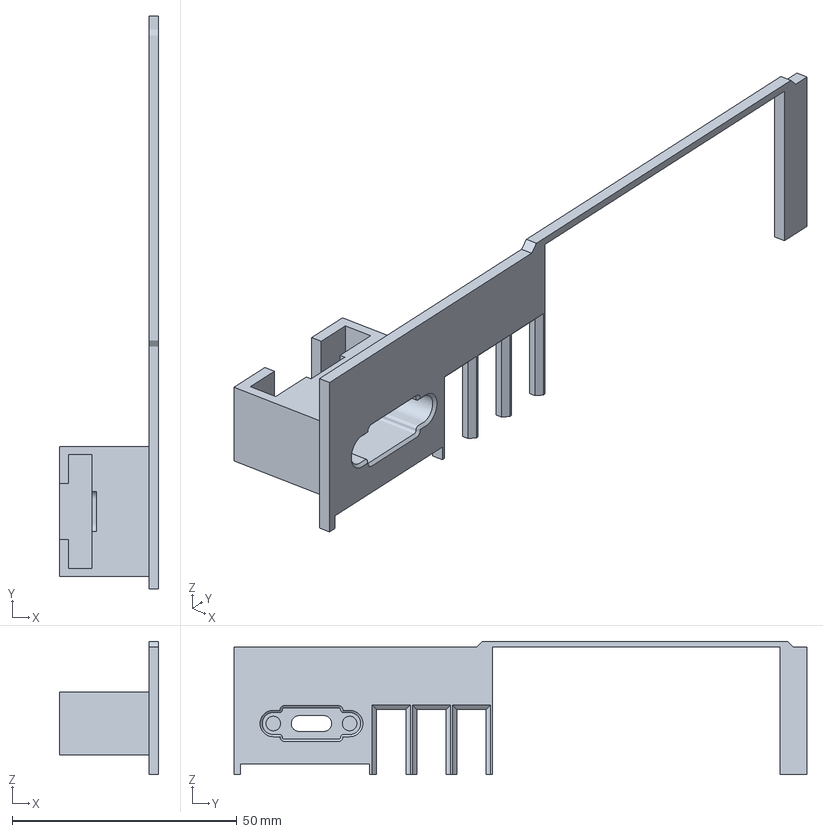
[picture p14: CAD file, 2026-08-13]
enclosure/MegaXE-Case-Right-panel-front-keyboard-USB.3mf
22.1 x 127.6 x 29.7 mm

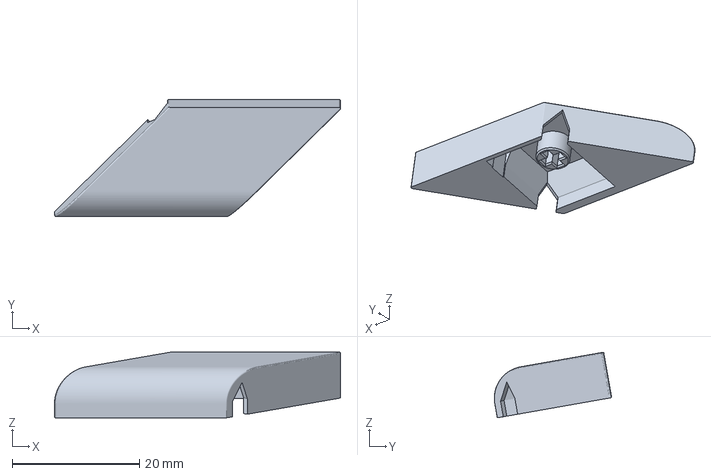
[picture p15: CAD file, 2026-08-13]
enclosure/MegaXE-Console key.3mf
44.9 x 18.4 x 10.3 mm

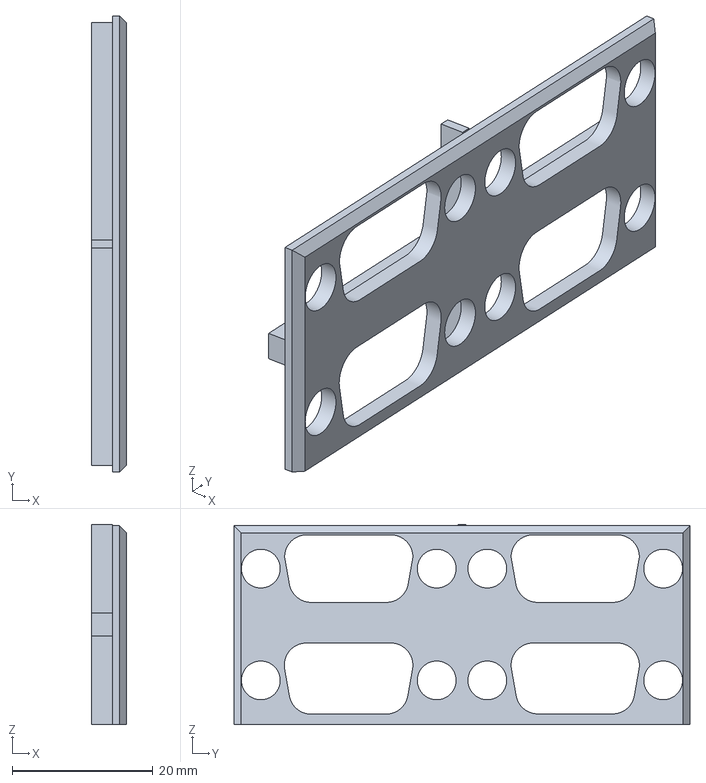
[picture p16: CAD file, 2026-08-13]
enclosure/MegaXE-Case-Joystick-port-frame.3mf
5.00 x 64.8 x 28.4 mm

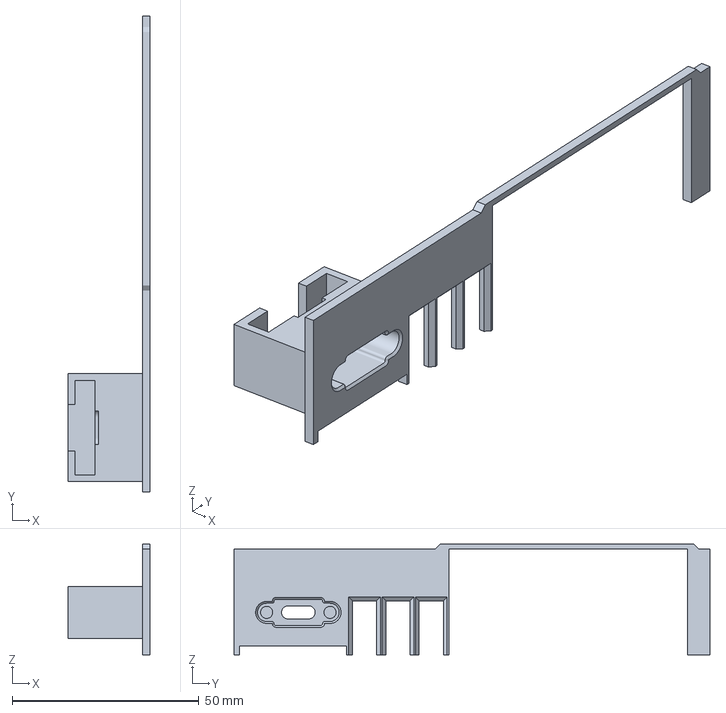
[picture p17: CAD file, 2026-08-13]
enclosure/MegaXE-Case-Right-panel.3mf
22.1 x 127.6 x 29.7 mm

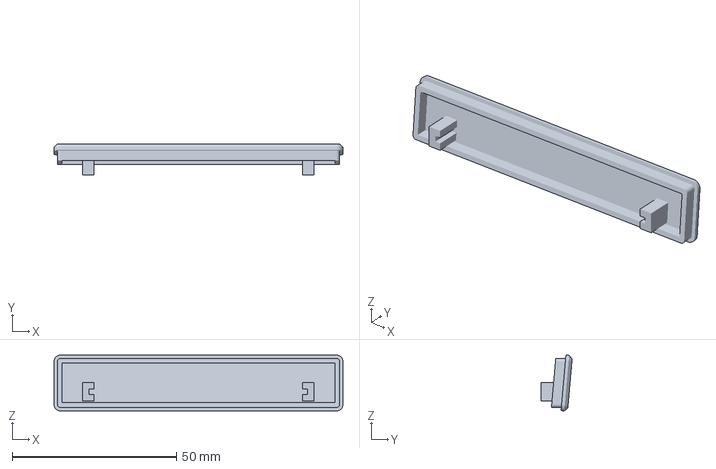
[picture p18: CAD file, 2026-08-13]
enclosure/MegaXE-Case-PBI-plug.3mf
88.0 x 9.54 x 17.0 mm

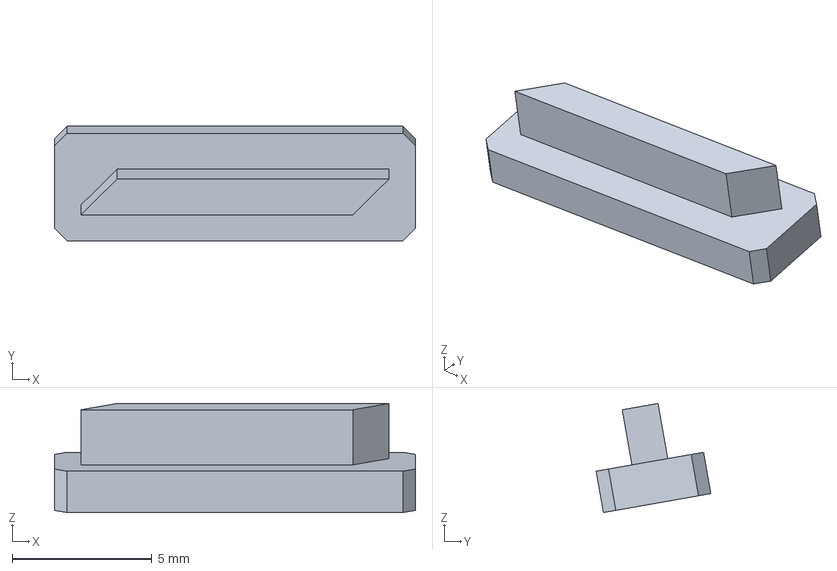
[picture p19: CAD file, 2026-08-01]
enclosure/MegaXE-Power LED window.3mf
12.9 x 4.10 x 3.90 mm

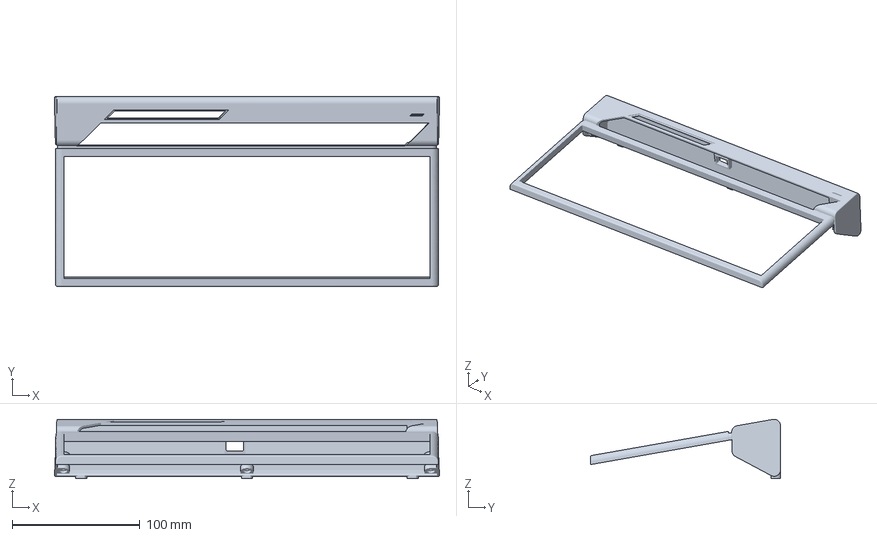
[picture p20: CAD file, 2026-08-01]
enclosure/MegaXE-Keyboard-case-Top.3mf
301.7 x 148.9 x 46.5 mm

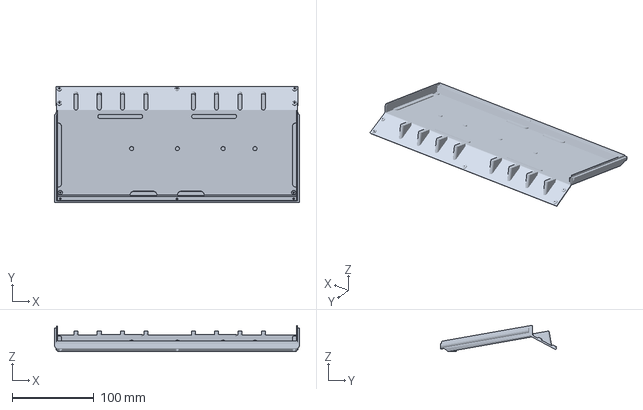
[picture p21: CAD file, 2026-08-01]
enclosure/MegaXE-Keyboard-case-Bottom.3mf
300.0 x 142.5 x 32.4 mm

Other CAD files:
rtl/hello_world_sdram/components/usbhostslave/trunk/usbDevice/syn/Actel/usbDeviceActelTop/designer/impl1/usbDeviceActelTop.stp
enclosure/MegaXE_case-Case bottom-front-keyboard-USB.3mf

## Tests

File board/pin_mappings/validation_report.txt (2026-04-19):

Validation summary for updated pin mappings

Netlist: tonnere.net

Updated FPGA mapping rows: 283

Checks passed:

- CSV rows match filtered U30 netlist pins one-for-one

- QSF assignments count matches CSV and each ball/net/port matches

- VHD entity ports cover every CSV port name/index

Key U30 changes detected vs previous U29 mapping:

- A12: Net-(U29J-CLK7) -> Net-(U30J-CLK8)
- D1: /FPGA/SPI.MISO -> /FPGA/SPI.MOSI
- G21: Net-(U29J-CLK4) -> Net-(U30J-CLK4)
- G22: Net-(U29J-CLK5) -> Net-(U30J-CLK5)
- K1: /FPGA/SPI.MOSI -> /FPGA/SPI.MISO
- N16: [new] -> /FPGA/SDRAM1.A9
- N17: /FPGA/SDRAM1.CLK -> /FPGA/SDRAM1.A11
- P15: /FPGA/SDRAM1.A11 -> [removed/unconnected]
- P16: /FPGA/SDRAM1.A9 -> [removed/unconnected]
- R15: [new] -> /FPGA/SRAM2.A16
- R16: /FPGA/SRAM2.A16 -> /FPGA/SDRAM1.CLK
- T1: Net-(U29J-CLK3) -> Net-(U30J-CLK3)
- T2: Net-(U29J-CLK2) -> Net-(U30J-CLK2)
- T7: [new] -> /FPGA/SRAM1.D1
- T8: [new] -> /FPGA/SRAM1.W_N
- T21: Net-(U29J-CLK6) -> Net-(U30J-CLK6)
- T22: Net-(U29J-CLK7) -> [removed/unconnected]
- U1: /FPGA/HDMI.CKN -> [removed/unconnected]
- U2: /FPGA/HDMI.CKP -> [removed/unconnected]
- V4: /FPGA/SRAM1.UB_N -> /FPGA/SRAM1.A4
- V5: /FPGA/SRAM1.D1 -> /FPGA/SRAM1.UB_N
- W6: /FPGA/SRAM1.D5 -> /FPGA/SRAM1.CE_N
- Y4: /FPGA/SRAM1.A2 -> /FPGA/SRAM1.A1
- Y6: /FPGA/SRAM1.D7 -> /FPGA/SRAM1.D5
- Y7: /FPGA/SRAM1.W_N -> /FPGA/SRAM1.D7
- AA3: /FPGA/SRAM1.A1 -> /FPGA/HDMI.CKP
- AA4: /FPGA/SRAM1.CE_N -> /FPGA/SRAM1.A2
- AB3: /FPGA/SRAM1.A4 -> /FPGA/HDMI.CKN
- AB11: Net-(U29J-CLK14) -> Net-(U30J-CLK14)

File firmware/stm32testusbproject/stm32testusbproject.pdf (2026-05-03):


02/05/2026

stm32testusbproject Project Configuration Report

## 1. Description

### 1.1. Project

Project Name | stm32testusbproject
Board Name | custom
Generated with: | STM32CubeMX 6.17.0
Date | 05/02/2026

### 1.2. MCU

MCU Series | STM32F4
MCU Line | STM32F407/417
MCU name | STM32F407ZGTx
MCU Package | LQFP144
MCU Pin number | 144

### 1.3. Core(s) information

Core(s) | Arm Cortex-M4

## 2. Pinout Configuration

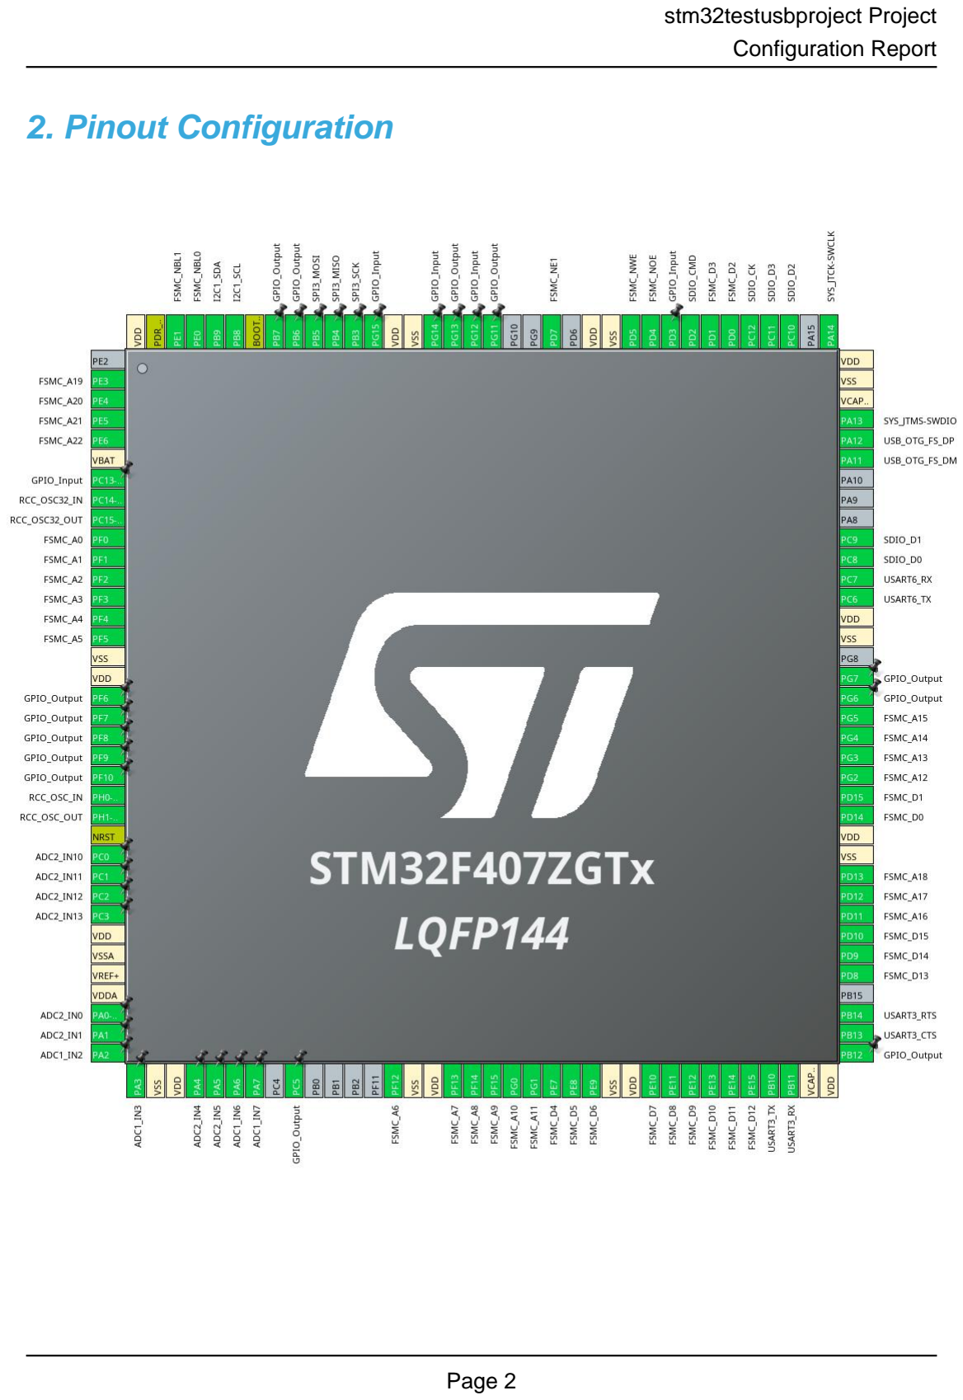
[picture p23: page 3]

## 3. Pins Configuration

Pin Number LQFP144 | Pin Name (function after reset) | Pin Type | Alternate Function(s) | Label
2 | PE3 | I/O | FSMC_A19
3 | PE4 | I/O | FSMC_A20
4 | PE5 | I/O | FSMC_A21
5 | PE6 | I/O | FSMC_A22
6 | VBAT | Power
7 | PC13-ANTI_TAMP * | I/O | GPIO_Input
8 | PC14-OSC32_IN | I/O | RCC_OSC32_IN
9 | PC15-OSC32_OUT | I/O | RCC_OSC32_OUT
10 | PF0 | I/O | FSMC_A0
11 | PF1 | I/O | FSMC_A1
12 | PF2 | I/O | FSMC_A2
13 | PF3 | I/O | FSMC_A3
14 | PF4 | I/O | FSMC_A4
15 | PF5 | I/O | FSMC_A5
16 | VSS | Power
17 | VDD | Power
18 | PF6 * | I/O | GPIO_Output
19 | PF7 * | I/O | GPIO_Output
20 | PF8 * | I/O | GPIO_Output
21 | PF9 * | I/O | GPIO_Output
22 | PF10 * | I/O | GPIO_Output
23 | PH0-OSC_IN | I/O | RCC_OSC_IN
24 | PH1-OSC_OUT | I/O | RCC_OSC_OUT
25 | NRST | Reset
26 | PC0 | I/O | ADC2_IN10
27 | PC1 | I/O | ADC2_IN11
28 | PC2 | I/O | ADC2_IN12
29 | PC3 | I/O | ADC2_IN13
30 | VDD | Power
31 | VSSA | Power
32 | VREF+ | Power
33 | VDDA | Power
34 | PA0-WKUP | I/O | ADC2_IN0
35 | PA1 | I/O | ADC2_IN1
36 | PA2 | I/O | ADC1_IN2
37 | PA3 | I/O | ADC1_IN3

Pin Number LQFP144 | Pin Name (function after reset) | Pin Type | Alternate Function(s) | Label
38 | VSS | Power
39 | VDD | Power
40 | PA4 | I/O | ADC2_IN4
41 | PA5 | I/O | ADC2_IN5
42 | PA6 | I/O | ADC1_IN6
43 | PA7 | I/O | ADC1_IN7
45 | PC5 * | I/O | GPIO_Output
50 | PF12 | I/O | FSMC_A6
51 | VSS | Power
52 | VDD | Power
53 | PF13 | I/O | FSMC_A7
54 | PF14 | I/O | FSMC_A8
55 | PF15 | I/O | FSMC_A9
56 | PG0 | I/O | FSMC_A10
57 | PG1 | I/O | FSMC_A11
58 | PE7 | I/O | FSMC_D4
59 | PE8 | I/O | FSMC_D5
60 | PE9 | I/O | FSMC_D6
61 | VSS | Power
62 | VDD | Power
63 | PE10 | I/O | FSMC_D7
64 | PE11 | I/O | FSMC_D8
65 | PE12 | I/O | FSMC_D9
66 | PE13 | I/O | FSMC_D10
67 | PE14 | I/O | FSMC_D11
68 | PE15 | I/O | FSMC_D12
69 | PB10 | I/O | USART3_TX
70 | PB11 | I/O | USART3_RX
71 | VCAP_1 | Power
72 | VDD | Power
73 | PB12 * | I/O | GPIO_Output
74 | PB13 | I/O | USART3_CTS
75 | PB14 | I/O | USART3_RTS
77 | PD8 | I/O | FSMC_D13
78 | PD9 | I/O | FSMC_D14
79 | PD10 | I/O | FSMC_D15
80 | PD11 | I/O | FSMC_A16
81 | PD12 | I/O | FSMC_A17
82 | PD13 | I/O | FSMC_A18

Pin Number LQFP144 | Pin Name (function after reset) | Pin Type | Alternate Function(s) | Label
83 | VSS | Power
84 | VDD | Power
85 | PD14 | I/O | FSMC_D0
86 | PD15 | I/O | FSMC_D1
87 | PG2 | I/O | FSMC_A12
88 | PG3 | I/O | FSMC_A13
89 | PG4 | I/O | FSMC_A14
90 | PG5 | I/O | FSMC_A15
91 | PG6 * | I/O | GPIO_Output
92 | PG7 * | I/O | GPIO_Output
94 | VSS | Power
95 | VDD | Power
96 | PC6 | I/O | USART6_TX
97 | PC7 | I/O | USART6_RX
98 | PC8 | I/O | SDIO_D0
99 | PC9 | I/O | SDIO_D1
103 | PA11 | I/O | USB_OTG_FS_DM
104 | PA12 | I/O | USB_OTG_FS_DP
105 | PA13 | I/O | SYS_JTMS-SWDIO
106 | VCAP_2 | Power
107 | VSS | Power
108 | VDD | Power
109 | PA14 | I/O | SYS_JTCK-SWCLK
111 | PC10 | I/O | SDIO_D2
112 | PC11 | I/O | SDIO_D3
113 | PC12 | I/O | SDIO_CK
114 | PD0 | I/O | FSMC_D2
115 | PD1 | I/O | FSMC_D3
116 | PD2 | I/O | SDIO_CMD
117 | PD3 * | I/O | GPIO_Input
118 | PD4 | I/O | FSMC_NOE
119 | PD5 | I/O | FSMC_NWE
120 | VSS | Power
121 | VDD | Power
123 | PD7 | I/O | FSMC_NE1
126 | PG11 * | I/O | GPIO_Output
127 | PG12 * | I/O | GPIO_Input
128 | PG13 * | I/O | GPIO_Output
129 | PG14 * | I/O | GPIO_Input

Pin Number LQFP144 | Pin Name (function after reset) | Pin Type | Alternate Function(s) | Label
130 | VSS | Power
131 | VDD | Power
132 | PG15 * | I/O | GPIO_Input
133 | PB3 | I/O | SPI3_SCK
134 | PB4 | I/O | SPI3_MISO
135 | PB5 | I/O | SPI3_MOSI
136 | PB6 * | I/O | GPIO_Output
137 | PB7 * | I/O | GPIO_Output
138 | BOOT0 | Boot
139 | PB8 | I/O | I2C1_SCL
140 | PB9 | I/O | I2C1_SDA
141 | PE0 | I/O | FSMC_NBL0
142 | PE1 | I/O | FSMC_NBL1
143 | PDR_ON | Reset
144 | VDD | Power

* The pin is affected with an I/O function

## 4. Clock Tree Configuration

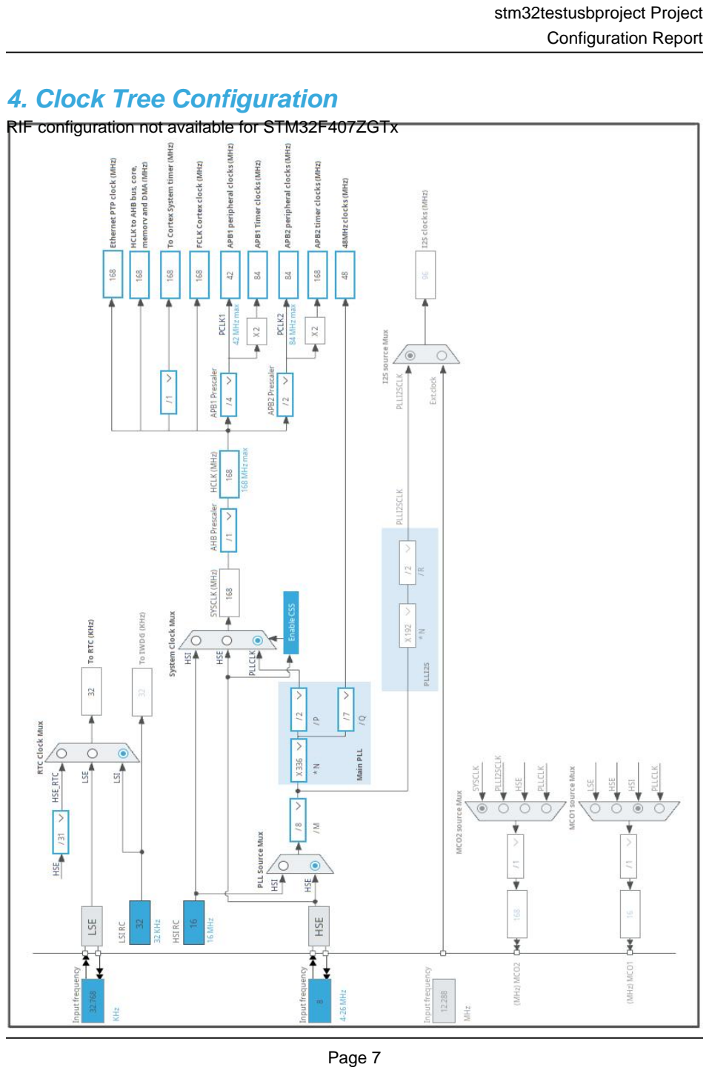
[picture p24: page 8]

RIF configuration not available for STM32F407ZGTx

## 1. Power Consumption Calculator report

### 1.1. Microcontroller Selection

Series | STM32F4
Line | STM32F407/417
MCU | STM32F407ZGTx
Datasheet | DS8626_Rev8

### 1.2. Parameter Selection

Temperature | 25
Vdd | 3.3

### 1.3. Battery Selection

Battery | Li-SOCL2(A3400)
Capacity | 3400.0 mAh
Self Discharge | 0.08 %/month
Nominal Voltage | 3.6 V
Max Cont Current | 100.0 mA
Max Pulse Current | 200.0 mA
Cells in series | 1
Cells in parallel | 1

### 1.4. Sequence

Step | Step1 | Step2
Mode | RUN | STOP
Vdd | 3.3 | 3.3
Voltage Source | Battery | Battery
Range | Scale1-High | No Scale
Fetch Type | FLASH | n/a
CPU Frequency | 168 MHz | 0 Hz
Clock Configuration | HSE PLL | Regulator_LP Flash-PwrDwn
Clock Source Frequency | 4 MHz | 0 Hz
Peripherals
Additional Cons. | 0 mA | 0 mA
Average Current | 46 mA | 280 µA
Duration | 0.1 ms | 0.9 ms
DMIPS | 210.0 | 0.0
Ta Max | 98.93 | 104.96
Category | In DS Table | In DS Table

### 1.5. Results

Sequence Time | 1 ms | Average Current | 4.85 mA
Battery Life | 29 days, 4 hours | Average DMIPS | 210.0 DMIPS

### 1.6. Chart

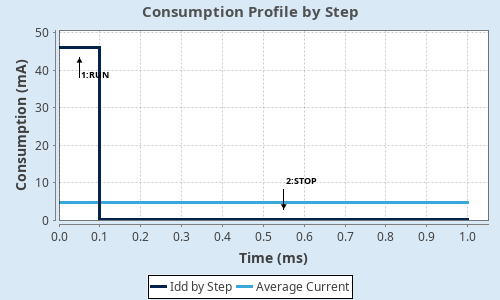
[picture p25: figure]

## 2. Software Project

### 2.1. Project Settings

Name | Value
Project Name | stm32testusbproject
Project Folder | /home/markw/git/tonnere/firmware/stm32testusbproject
Toolchain / IDE | CMake
Firmware Package Name and Version | STM32Cube FW_F4 V1.28.3
Application Structure | Advanced
Generate Under Root | No
Do not generate the main() | No
Minimum Heap Size | 0x200
Minimum Stack Size | 0x400

### 2.2. Code Generation Settings

Name | Value
STM32Cube MCU packages and embedded software | Copy only the necessary library files
Generate peripheral initialization as a pair of '.c/.h' files | No
Backup previously generated files when re-generating | No
Keep User Code when re-generating | Yes
Delete previously generated files when not re-generated | Yes
Set all free pins as analog (to optimize the power consumption) | No
Enable Full Assert | No

### 2.3. Advanced Settings - Generated Function Calls

Rank | Function Name | Peripheral Instance Name
1 | SystemClock_Config | RCC
2 | MX_GPIO_Init | GPIO
3 | MX_RTC_Init | RTC
4 | MX_USB_OTG_FS_HCD_Init | USB_OTG_FS
5 | MX_FSMC_Init | FSMC
6 | MX_ADC1_Init | ADC1
7 | MX_ADC2_Init | ADC2
8 | MX_I2C1_Init | I2C1
9 | MX_SDIO_SD_Init | SDIO
10 | MX_SPI3_Init | SPI3
11 | MX_USART3_UART_Init | USART3

Rank | Function Name | Peripheral Instance Name
12 | MX_USART6_UART_Init | USART6

## 3. Peripherals and Middlewares Configuration

### 3.1. ADC1

mode: IN2
mode: IN3
mode: IN6
mode: IN7
3.1.1. Parameter Settings:

ADCs_Common_Settings:

Mode | Independent mode
ADC_Settings:
Clock Prescaler | PCLK2 divided by 4
Resolution | 12 bits (15 ADC Clock cycles)
Data Alignment | Right alignment
Scan Conversion Mode | Disabled
Continuous Conversion Mode | Disabled
Discontinuous Conversion Mode | Disabled
DMA Continuous Requests | Disabled
End Of Conversion Selection | EOC flag at the end of single channel conversion
ADC_Regular_ConversionMode:
Number Of Conversion | 1
External Trigger Conversion Source | Regular Conversion launched by software
External Trigger Conversion Edge | None
Rank | 1
Channel | Channel 2
Sampling Time | 3 Cycles
ADC_Injected_ConversionMode:
Number Of Conversions | 0
WatchDog:
Enable Analog WatchDog Mode | false

### 3.2. ADC2

mode: IN0
mode: IN1
mode: IN4
mode: IN5

mode: IN10
mode: IN11
mode: IN12
mode: IN13
3.2.1. Parameter Settings:

ADCs_Common_Settings:

Mode | Independent mode
ADC_Settings:
Clock Prescaler | PCLK2 divided by 4
Resolution | 12 bits (15 ADC Clock cycles)
Data Alignment | Right alignment
Scan Conversion Mode | Disabled
Continuous Conversion Mode | Disabled
Discontinuous Conversion Mode | Disabled
DMA Continuous Requests | Disabled
End Of Conversion Selection | EOC flag at the end of single channel conversion
ADC_Regular_ConversionMode:
Number Of Conversion | 1
External Trigger Conversion Source | Regular Conversion launched by software
External Trigger Conversion Edge | None
Rank | 1
Channel | Channel 1 *
Sampling Time | 3 Cycles
ADC_Injected_ConversionMode:
Number Of Conversions | 0
WatchDog:
Enable Analog WatchDog Mode | false

### 3.3. FSMC

NOR Flash/PSRAM/SRAM/ROM/LCD 1 Chip Select: NE1
Memory type: SRAM
Address: 23 bits
Data: 16 bits
Byte enable: set

3.3.1. NOR/PSRAM 1:

NOR/PSRAM control:

Memory type | SRAM
Bank | Bank 1 NOR/PSRAM 1
Write operation | Enabled *
Extended mode | Disabled
NOR/PSRAM timing:
Address setup time in HCLK clock cycles | 15
Data setup time in HCLK clock cycles | 255
Bus turn around time in HCLK clock cycles | 15

### 3.4. I2C1

I2C: I2C
3.4.1. Parameter Settings:

Master Features:

I2C Speed Mode | Standard Mode
I2C Clock Speed (Hz) | 100000
Slave Features:
Clock No Stretch Mode | Disabled
Primary Address Length selection | 7-bit
Dual Address Acknowledged | Disabled
Primary slave address | 0
General Call address detection | Disabled

### 3.5. RCC

High Speed Clock (HSE): Crystal/Ceramic Resonator Low Speed Clock (LSE) : Crystal/Ceramic Resonator
3.5.1. Parameter Settings:

System Parameters:

VDD voltage (V) | 3.3
Instruction Cache | Enabled
Prefetch Buffer | Enabled
Data Cache | Enabled
Flash Latency(WS) | 5 WS (6 CPU cycle)

RCC Parameters:

HSI Calibration Value | 16
HSE Startup Timout Value (ms) | 100
LSE Startup Timout Value (ms) | 5000
Power Parameters:
Power Regulator Voltage Scale | Power Regulator Voltage Scale 1

### 3.6. RTC

mode: Activate Clock Source
3.6.1. Parameter Settings:

General:

Hour Format | Hourformat 24
Asynchronous Predivider value | 127
Synchronous Predivider value | 255

### 3.7. SDIO

Mode: SD 4 bits Wide bus
3.7.1. Parameter Settings:

SDIO parameters:

Clock transition on which the bit capture is made | Rising transition
SDIO Clock divider bypass | Disable
SDIO Clock output enable when the bus is idle | Disable the power save for the clock
SDIO hardware flow control | The hardware control flow is disabled
SDIOCLK clock divide factor | 0

### 3.8. SPI3

Mode: Full-Duplex Master
3.8.1. Parameter Settings:

Basic Parameters:

Frame Format | Motorola
Data Size | 8 Bits
First Bit | MSB First

Clock Parameters:

Prescaler (for Baud Rate) | 2
Baud Rate | 21.0 MBits/s *
Clock Polarity (CPOL) | Low
Clock Phase (CPHA) | 1 Edge
Advanced Parameters:
CRC Calculation | Disabled
NSS Signal Type | Software

### 3.9. SYS

Debug: Serial Wire
Timebase Source: TIM6

### 3.10. USART3

Mode: Asynchronous
Hardware Flow Control (RS232): CTS/RTS
3.10.1. Parameter Settings:

Basic Parameters:

Baud Rate | 115200
Word Length | 8 Bits (including Parity)
Parity | None
Stop Bits | 1
Advanced Parameters:
Data Direction | Receive and Transmit
Over Sampling | 16 Samples

### 3.11. USART6

Mode: Asynchronous
3.11.1. Parameter Settings:

Basic Parameters:

Baud Rate | 115200
Word Length | 8 Bits (including Parity)
Parity | None
Stop Bits | 1

Advanced Parameters:

Data Direction | Receive and Transmit
Over Sampling | 16 Samples

### 3.12. USB_OTG_FS

Mode: Host_Only
3.12.1. Parameter Settings:
Speed | Host Full Speed 12MBit/s
Signal start of frame | Disabled

### 3.13. STMicroelectronics.X-CUBE-AZRTOS-F4.1.1.0

mode: RTOSJjThreadX
mode: USBJjUSBX
3.13.1. AzureRTOS Application:

Memory Configuration:

Memory Allocation | Use Static MemPool Allocation
ThreadX memory pool size | 1024
UXHost memory pool size | 1024
3.13.2. ThreadX:

Version:

ThreadX version | 6.1.7
Core:
TX_MINIMUM_STACK | 200
TX_THREAD_USER_EXTENSION
TX_DISABLE_STACK_FILLING | Disabled
TX_ENABLE_STACK_CHECKING | Disabled
TX_DISABLE_PREEMPTION_THRESHOLD | Enabled
TX_DISABLE_REDUNDANT_CLEARING | Disabled
TX_DISABLE_NOTIFY_CALLBACKS | Enabled
TX_INLINE_THREAD_RESUME_SUSPEND | Disabled
TX_NOT_INTERRUPTABLE | Disabled
TX_MAX_PRIORITIES | 32
TX_ENABLE_EXECUTION_CHANGE_NOTIFY | Disabled

TX_THREAD_GET_SYSTEM_STATE | _tx_thread_system_state
TX_THREAD_SYSTEM_RETURN_CHECK (c) | _tx_thread_preempt_disable
TX_TIMER_TICKS_PER_SECOND | 100
ALIGN_TYPE_DEFINED | Disabled
TX_MEMSET | memset
TX_ENABLE_IAR_LIBRARY_SUPPORT | Disabled
TX_SAFETY_CRITICAL | Disabled
TX_NO_FILEX_POINTER | Disabled
Timer:
TX_TIMER_PROCESS_IN_ISR | Disabled
TX_REACTIVATE_INLINE | Disabled
TX_TIMER_THREAD_STACK_SIZE | 1024
TX_TIMER_THREAD_PRIORITY | 0
3.13.3. USBX:

Version:

USBX version | 6.1.7
Host Core:
UX_THREAD_STACK_SIZE | 2048
UX_HOST_ENUM_THREAD_STACK_SIZE | 2048
UX_HOST_HCD_THREAD_STACK_SIZE | 2048
UX_HOST_HNP_POLLING_THREAD_STACK | 2048
UX_MAX_HCD | USB 1.1
UX_PERIODIC_RATE | 1000
UX_HOST_SIDE_ONLY | Enabled
UX_THREAD_PRIORITY_HCD | 2
UX_NO_TIME_SLICE | 0
UX_MAX_CLASS_DRIVER | 3
UX_MAX_TT | 8
Host Controller:
UX_MAX_ED | 80
UX_MAX_TD | 128
UX_MAX_ISO_TD | 1
Host HID Core:
UX_HOST_CLASS_HID_DECOMPRESSION_BUFFER | 4096
UX_HOST_CLASS_HID_USAGES | 2048
Host Class HID Keyboard:
UX_HOST_CLASS_HID_KEYBOARD_EVENTS_KEY_CHANGES_MODE | Disabled
UX_THREAD_PRIORITY_KEYBOARD | 20
Core Utilities:

UX_ENFORCE_SAFE_ALIGNMENT | Disabled
UX_DEBUG_LOG_SIZE | 16384
UX_THREAD_PRIORITY_ENUM | 20
UX_THREAD_PRIORITY_CLASS | 20

* User modified value

## 4. System Configuration

### 4.1. GPIO configuration

IP | Pin | Signal | GPIO mode | GPIO pull/up pull down

Max
Speed

User Label

ADC1 | PA2 | ADC1_IN2 | Analog mode | No pull-up and no pull-down | n/a
| PA3 | ADC1_IN3 | Analog mode | No pull-up and no pull-down | n/a
| PA6 | ADC1_IN6 | Analog mode | No pull-up and no pull-down | n/a
| PA7 | ADC1_IN7 | Analog mode | No pull-up and no pull-down | n/a
ADC2 | PC0 | ADC2_IN10 | Analog mode | No pull-up and no pull-down | n/a
| PC1 | ADC2_IN11 | Analog mode | No pull-up and no pull-down | n/a
| PC2 | ADC2_IN12 | Analog mode | No pull-up and no pull-down | n/a
| PC3 | ADC2_IN13 | Analog mode | No pull-up and no pull-down | n/a
| PA0-WKUP | ADC2_IN0 | Analog mode | No pull-up and no pull-down | n/a
| PA1 | ADC2_IN1 | Analog mode | No pull-up and no pull-down | n/a
| PA4 | ADC2_IN4 | Analog mode | No pull-up and no pull-down | n/a
| PA5 | ADC2_IN5 | Analog mode | No pull-up and no pull-down | n/a
FSMC | PE3 | FSMC_A19 | Alternate Function Push Pull | No pull-up and no pull-down | Very High
| PE4 | FSMC_A20 | Alternate Function Push Pull | No pull-up and no pull-down | Very High
| PE5 | FSMC_A21 | Alternate Function Push Pull | No pull-up and no pull-down | Very High
| PE6 | FSMC_A22 | Alternate Function Push Pull | No pull-up and no pull-down | Very High
| PF0 | FSMC_A0 | Alternate Function Push Pull | No pull-up and no pull-down | Very High
| PF1 | FSMC_A1 | Alternate Function Push Pull | No pull-up and no pull-down | Very High
| PF2 | FSMC_A2 | Alternate Function Push Pull | No pull-up and no pull-down | Very High
| PF3 | FSMC_A3 | Alternate Function Push Pull | No pull-up and no pull-down | Very High
| PF4 | FSMC_A4 | Alternate Function Push Pull | No pull-up and no pull-down | Very High
| PF5 | FSMC_A5 | Alternate Function Push Pull | No pull-up and no pull-down | Very High
| PF12 | FSMC_A6 | Alternate Function Push Pull | No pull-up and no pull-down | Very High
| PF13 | FSMC_A7 | Alternate Function Push Pull | No pull-up and no pull-down | Very High
| PF14 | FSMC_A8 | Alternate Function Push Pull | No pull-up and no pull-down | Very High
| PF15 | FSMC_A9 | Alternate Function Push Pull | No pull-up and no pull-down | Very High
| PG0 | FSMC_A10 | Alternate Function Push Pull | No pull-up and no pull-down | Very High
| PG1 | FSMC_A11 | Alternate Function Push Pull | No pull-up and no pull-down | Very High
| PE7 | FSMC_D4 | Alternate Function Push Pull | No pull-up and no pull-down | Very High
| PE8 | FSMC_D5 | Alternate Function Push Pull | No pull-up and no pull-down | Very High
| PE9 | FSMC_D6 | Alternate Function Push Pull | No pull-up and no pull-down | Very High
| PE10 | FSMC_D7 | Alternate Function Push Pull | No pull-up and no pull-down | Very High
| PE11 | FSMC_D8 | Alternate Function Push Pull | No pull-up and no pull-down | Very High
| PE12 | FSMC_D9 | Alternate Function Push Pull | No pull-up and no pull-down | Very High
| PE13 | FSMC_D10 | Alternate Function Push Pull | No pull-up and no pull-down | Very High
| PE14 | FSMC_D11 | Alternate Function Push Pull | No pull-up and no pull-down | Very High

IP | Pin | Signal | GPIO mode | GPIO pull/up pull down | Max Speed | User Label
| PE15 | FSMC_D12 | Alternate Function Push Pull | No pull-up and no pull-down | Very High
| PD8 | FSMC_D13 | Alternate Function Push Pull | No pull-up and no pull-down | Very High
| PD9 | FSMC_D14 | Alternate Function Push Pull | No pull-up and no pull-down | Very High
| PD10 | FSMC_D15 | Alternate Function Push Pull | No pull-up and no pull-down | Very High
| PD11 | FSMC_A16 | Alternate Function Push Pull | No pull-up and no pull-down | Very High
| PD12 | FSMC_A17 | Alternate Function Push Pull | No pull-up and no pull-down | Very High
| PD13 | FSMC_A18 | Alternate Function Push Pull | No pull-up and no pull-down | Very High
| PD14 | FSMC_D0 | Alternate Function Push Pull | No pull-up and no pull-down | Very High
| PD15 | FSMC_D1 | Alternate Function Push Pull | No pull-up and no pull-down | Very High
| PG2 | FSMC_A12 | Alternate Function Push Pull | No pull-up and no pull-down | Very High
| PG3 | FSMC_A13 | Alternate Function Push Pull | No pull-up and no pull-down | Very High
| PG4 | FSMC_A14 | Alternate Function Push Pull | No pull-up and no pull-down | Very High
| PG5 | FSMC_A15 | Alternate Function Push Pull | No pull-up and no pull-down | Very High
| PD0 | FSMC_D2 | Alternate Function Push Pull | No pull-up and no pull-down | Very High
| PD1 | FSMC_D3 | Alternate Function Push Pull | No pull-up and no pull-down | Very High
| PD4 | FSMC_NOE | Alternate Function Push Pull | No pull-up and no pull-down | Very High
| PD5 | FSMC_NWE | Alternate Function Push Pull | No pull-up and no pull-down | Very High
| PD7 | FSMC_NE1 | Alternate Function Push Pull | No pull-up and no pull-down | Very High
| PE0 | FSMC_NBL0 | Alternate Function Push Pull | No pull-up and no pull-down | Very High
| PE1 | FSMC_NBL1 | Alternate Function Push Pull | No pull-up and no pull-down | Very High
I2C1 | PB8 | I2C1_SCL | Alternate Function Open Drain | No pull-up and no pull-down | Very High *
| PB9 | I2C1_SDA | Alternate Function Open Drain | No pull-up and no pull-down | Very High *
RCC | PC14-OSC32_IN | RCC_OSC32_IN | n/a | n/a | n/a
| PC15-OSC32_OU T | RCC_OSC32_O UT | n/a | n/a | n/a
| PH0-OSC_IN | RCC_OSC_IN | n/a | n/a | n/a
| PH1-OSC_OUT | RCC_OSC_OUT | n/a | n/a | n/a
SDIO | PC8 | SDIO_D0 | Alternate Function Push Pull | No pull-up and no pull-down | Very High
| PC9 | SDIO_D1 | Alternate Function Push Pull | No pull-up and no pull-down | Very High
| PC10 | SDIO_D2 | Alternate Function Push Pull | No pull-up and no pull-down | Very High
| PC11 | SDIO_D3 | Alternate Function Push Pull | No pull-up and no pull-down | Very High
| PC12 | SDIO_CK | Alternate Function Push Pull | No pull-up and no pull-down | Very High
| PD2 | SDIO_CMD | Alternate Function Push Pull | No pull-up and no pull-down | Very High
SPI3 | PB3 | SPI3_SCK | Alternate Function Push Pull | No pull-up and no pull-down | Very High *

IP | Pin | Signal | GPIO mode | GPIO pull/up pull down

Max
Speed

User Label

| PB4 | SPI3_MISO | Alternate Function Push Pull | No pull-up and no pull-down | Very High
*
| PB5 | SPI3_MOSI | Alternate Function Push Pull | No pull-up and no pull-down | Very High
*
SYS | PA13 | SYS_JTMS- SWDIO | n/a | n/a | n/a
| PA14 | SYS_JTCK- SWCLK | n/a | n/a | n/a
USART3 | PB10 | USART3_TX | Alternate Function Push Pull | No pull-up and no pull-down | Very High
*
| PB11 | USART3_RX | Alternate Function Push Pull | No pull-up and no pull-down | Very High
*
PB13 | USART3_CTS Alternate Function Push Pull | No pull-up and no pull-down | Very High
*
PB14 | USART3_RTS Alternate Function Push Pull | No pull-up and no pull-down | Very High
*
USART6 | PC6 | USART6_TX | Alternate Function Push Pull | No pull-up and no pull-down | Very High
*
| PC7 | USART6_RX | Alternate Function Push Pull | No pull-up and no pull-down | Very High
*
USB_OTG_ FS | PA11 | USB_OTG_FS_ DM | Alternate Function Push Pull | No pull-up and no pull-down | Very High
*
| PA12 | USB_OTG_FS_ DP | Alternate Function Push Pull | No pull-up and no pull-down | Very High
*
GPIO | PC13- ANTI_TAMP | GPIO_Input | Input mode | No pull-up and no pull-down | n/a
| PF6 | GPIO_Output | Output Push Pull | No pull-up and no pull-down | Low
| PF7 | GPIO_Output | Output Push Pull | No pull-up and no pull-down | Low
| PF8 | GPIO_Output | Output Push Pull | No pull-up and no pull-down | Low
| PF9 | GPIO_Output | Output Push Pull | No pull-up and no pull-down | Low
| PF10 | GPIO_Output | Output Push Pull | No pull-up and no pull-down | Low
| PC5 | GPIO_Output | Output Push Pull | No pull-up and no pull-down | Low
| PB12 | GPIO_Output | Output Push Pull | No pull-up and no pull-down | Low
| PG6 | GPIO_Output | Output Push Pull | No pull-up and no pull-down | Low
| PG7 | GPIO_Output | Output Push Pull | No pull-up and no pull-down | Low
| PD3 | GPIO_Input | Input mode | No pull-up and no pull-down | n/a
| PG11 | GPIO_Output | Output Push Pull | No pull-up and no pull-down | Low
| PG12 | GPIO_Input | Input mode | No pull-up and no pull-down | n/a
| PG13 | GPIO_Output | Output Push Pull | No pull-up and no pull-down | Low

IP | Pin | Signal | GPIO mode | GPIO pull/up pull down | Max Speed | User Label
| PG14 | GPIO_Input | Input mode | No pull-up and no pull-down | n/a
| PG15 | GPIO_Input | Input mode | No pull-up and no pull-down | n/a
| PB6 | GPIO_Output | Output Push Pull | No pull-up and no pull-down | Low
| PB7 | GPIO_Output | Output Push Pull | No pull-up and no pull-down | Low

### 4.2. DMA configuration

nothing configured in DMA service

### 4.3. NVIC configuration

4.3.1. NVIC
Interrupt Table | Enable | Preenmption Priority | SubPriority
Non maskable interrupt | true | 0 | 0
Hard fault interrupt | true | 0 | 0
Memory management fault | true | 0 | 0
Pre-fetch fault, memory access fault | true | 0 | 0
Undefined instruction or illegal state | true | 0 | 0
System service call via SWI instruction | true | 0 | 0
Debug monitor | true | 0 | 0
Pendable request for system service | true | 0 | 0
System tick timer | true | 0 | 0
TIM6 global interrupt, DAC1 and DAC2 underrun error interrupts | true | 15 | 0
USB On The Go FS global interrupt | true | 0 | 0
PVD interrupt through EXTI line 16 | | unused
Flash global interrupt | | unused
RCC global interrupt | | unused
ADC1, ADC2 and ADC3 global interrupts | | unused
I2C1 event interrupt | | unused
I2C1 error interrupt | | unused
USART3 global interrupt | | unused
SDIO global interrupt | | unused
SPI3 global interrupt | | unused
USART6 global interrupt | | unused
FPU global interrupt | | unused
4.3.2. NVIC Code generation

Enabled interrupt Table Select for init
sequence ordering
| | Generate IRQ
| | handler | Call HAL handler
Non maskable interrupt | false | true | false
Hard fault interrupt | false | true | false
Memory management fault | false | true | false
Pre-fetch fault, memory access fault | false | true | false
Undefined instruction or illegal state | false | true | false
System service call via SWI instruction | false | false | false
Debug monitor | false | true | false
Pendable request for system service | false | false | false
System tick timer | false | false | true
TIM6 global interrupt, DAC1 and DAC2 | false | true | true

Enabled interrupt Table | Select for init sequence ordering | Generate IRQ handler | Call HAL handler

underrun error interrupts
USB On The Go FS global interrupt | false | true | true

* User modified value

## 5. System Views

5.1. Category view
5.1.1. Current

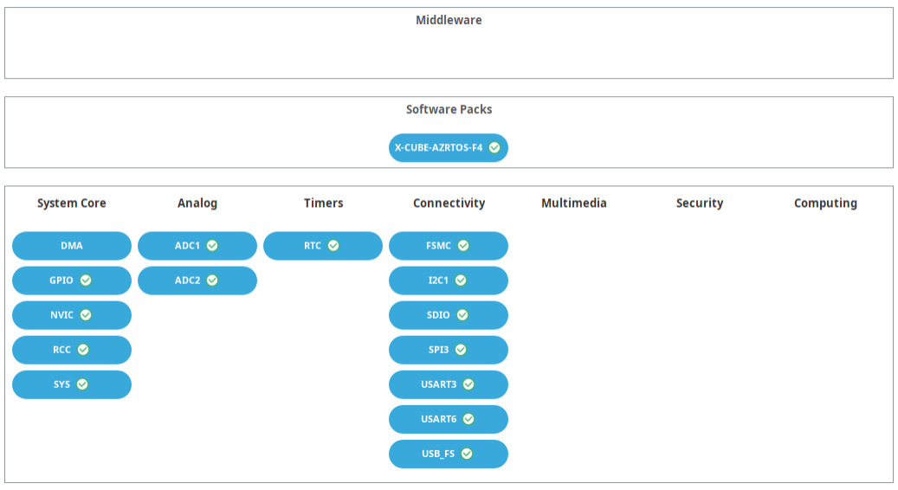
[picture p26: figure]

## 6. Software Pack Report
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

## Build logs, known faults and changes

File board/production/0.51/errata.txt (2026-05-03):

Power:
Power switch connects 5V to GND when off!
USB DFU:
STM PB5 MOSI messes up DFU:
i) Free PA7 by moving the ADC input to PB0.
ii) Free PB5 by moving SPI from PB5 to PA7.
iii) Potentially we need pull downs on PB5, PA10, PB11 (or gnd them). To be tested if it 'just works' or not.
iv) U32 D9/D10 are on input only FPGA pins! So we lose 1MB of SRAM without patching it. AA12/AB12. Spare pins for respin: T10, R14, T13. Bodge: Use A20 (unused) from both SRA chips for D9/D10.
v) G2 (DAC G) is also on an input only pin. Move to F1? Bodge: Use FPGA GPIO on bus switch side (+ cut trace)
vi) DAC is a bit noisy with only one pin per channel and sigma delta. Add a capacitor at a minimum, though most likely use a second pin at a lower level (part R2R and part pattern based or sigma delta - TBD).
vii) SIO.MOTOR does not go via the level shifter (so does not turn on). Also transistor is not fully on but is enough for 100mA which is within SIO specs I think.

Layout:
a) Move power switch and power in slightly further apart.
b) Add solder pads to DB9s
c) Add a power LED or at least an LED header

To consider:
a) USB power ic and VBUS plumbing
b) USB HS PHY

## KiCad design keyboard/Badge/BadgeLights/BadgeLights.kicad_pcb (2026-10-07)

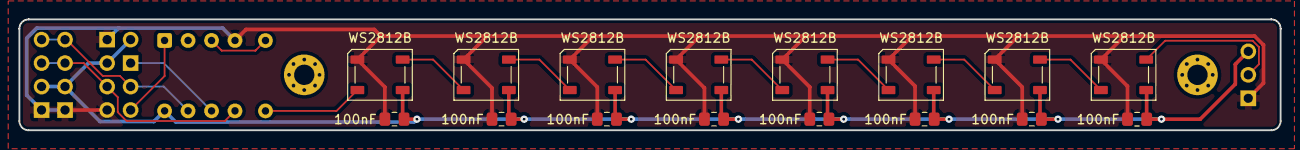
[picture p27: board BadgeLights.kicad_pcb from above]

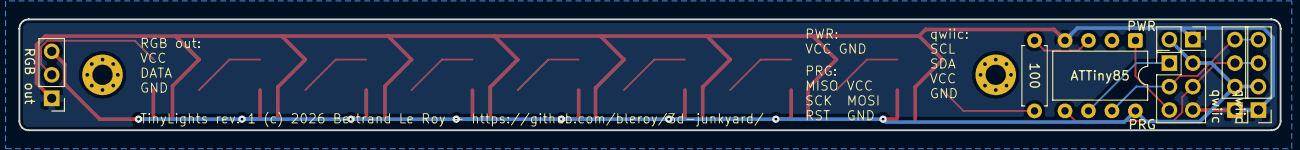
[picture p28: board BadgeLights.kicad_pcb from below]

Board: 2 copper layers, 136.5 x 12.0 mm, 25 parts (7 on the bottom side), 16 nets.

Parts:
C24, C25, C26, C27, C28, C29, C30, C31: 100nF; C_0805_2012Metric_Pad1.18x1.45mm_HandSolder
D1, D2, D3, D4, D5, D6, D7, D8: WS2812B; LED_WS2812B_PLCC4_5.0x5.0mm_P3.2mm
H1, H2: MountingHole_Pad; MountingHole_2.2mm_M2_Pad_Via
PRG: Conn_02x03_Odd_Even; PinHeader_2x03_P2.54mm_Vertical
PWR: Conn_01x02_Pin; PinHeader_1x02_P2.54mm_Vertical
R1: R; R_Axial_DIN0207_L6.3mm_D2.5mm_P7.62mm_Horizontal
RGB out: Conn_01x03_Pin; PinHeader_1x03_P2.54mm_Vertical
U1: ATtiny85-20P; DIP-8_W7.62mm
qwiic: Conn_01x04; PinHeader_1x04_P2.54mm_Vertical
qwiic#2: Conn_01x04; PinHeader_1x04_P2.54mm_Vertical

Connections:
+5V: C24.1, C25.1, C26.1, C27.1, C28.1, C29.1, C30.1, C31.1, D1.1 (VDD), D2.1 (VDD), D3.1 (VDD), D4.1 (VDD), D5.1 (VDD), D6.1 (VDD), D7.1 (VDD), D8.1 (VDD), PRG.2, PWR.2, RGB out.3, U1.8 (VCC), qwiic.2, qwiic#2.2
GND: C24.2, C25.2, C26.2, C27.2, C28.2, C29.2, C30.2, C31.2, D1.3 (VSS), D2.3 (VSS), D3.3 (VSS), D4.3 (VSS), D5.3 (VSS), D6.3 (VSS), D7.3 (VSS), D8.3 (VSS), PRG.6, PWR.1, RGB out.1, U1.4 (GND), qwiic.1, qwiic#2.1
unnamed: D1.4 (DIN), R1.2
unnamed: D1.2 (DOUT), D2.4 (DIN)
unnamed: D2.2 (DOUT), D3.4 (DIN)
unnamed: D3.2 (DOUT), D4.4 (DIN)
unnamed: D4.2 (DOUT), D5.4 (DIN)
unnamed: D5.2 (DOUT), D6.4 (DIN)
unnamed: D6.2 (DOUT), D7.4 (DIN)
unnamed: D7.2 (DOUT), D8.4 (DIN)
unnamed: D8.2 (DOUT), RGB out.2
unnamed: PRG.1, U1.6 (PB1)
unnamed: PRG.3, U1.7 (PB2), qwiic.4, qwiic#2.4
unnamed: PRG.4, U1.5 (AREF/PB0), qwiic.3, qwiic#2.3
unnamed: PRG.5, U1.1 (~RESET/PB5)
unnamed: R1.1, U1.3 (XTAL2/PB4)

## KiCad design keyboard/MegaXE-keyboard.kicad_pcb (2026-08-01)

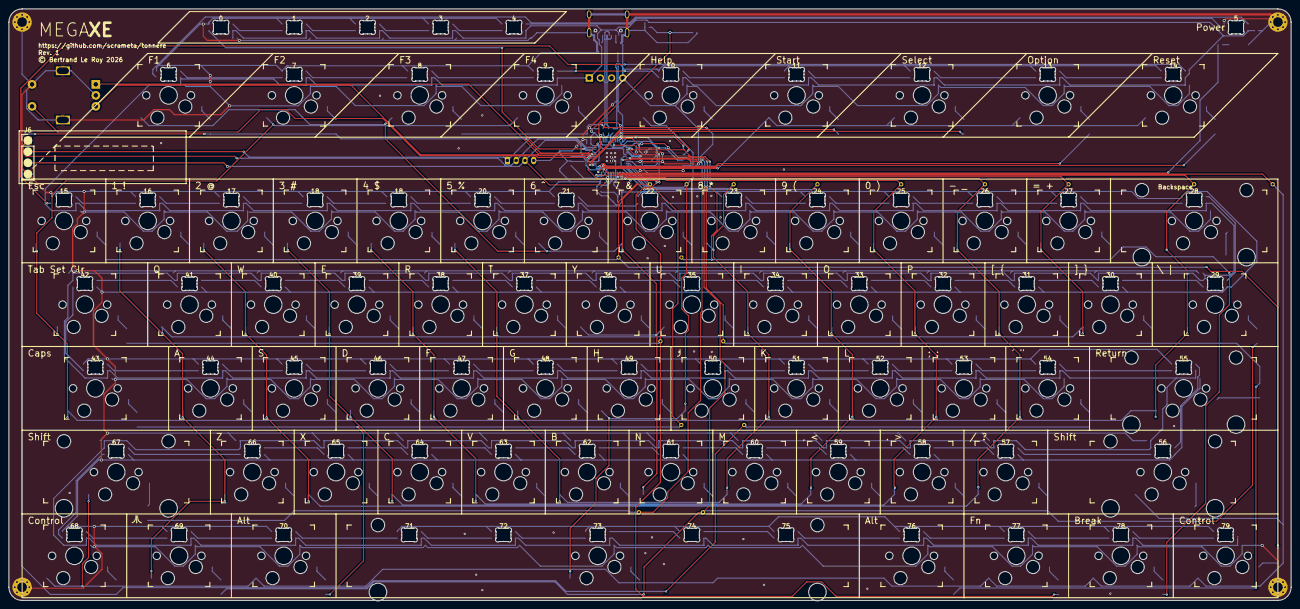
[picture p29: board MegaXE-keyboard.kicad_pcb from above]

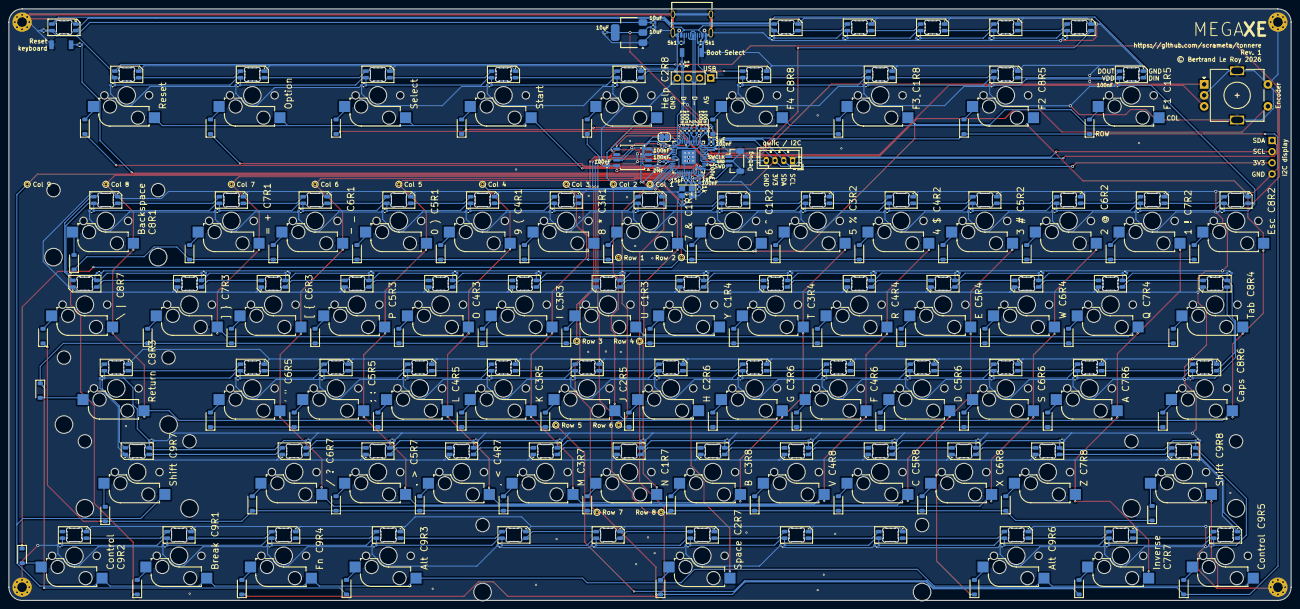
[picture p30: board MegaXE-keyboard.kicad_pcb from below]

Board: 2 copper layers, 291.8 x 134.6 mm, 359 parts (288 on the bottom side), 202 nets.

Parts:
C4, C6, C7, C8, C9, C10, C11, C12, C13, C42, C75, C76, C77, C78, C79, C80, C81, C82, C83, C84, C85, C86, C87, C88, C89, C90, C91, C92, C93, C94, C95, C96, C97, C98, C99, C100, C101, C102, C103, C104, C105, C106, C107, C108, C109, C110, C111, C112, C113, C114, C115, C116, C117, C118, C119, C120, C121, C123, C124, C125, C126, C127, C128, C129, C130, C131, C132, C133, C134, C135, C136, C137, C138, C139, C140, C141, C142, C143, C144, C145, C146, C147, C148, C149, C150, C151, C152, C153, C154, C155: 100nF; C_0402_1005Metric
C5, C14: 1uF; C_0402_1005Metric
C24, C25: 15pF; C_0402_1005Metric
C27, C28, C43: 10uF; C_0402_1005Metric
D17, D18, D19, D20, D21, D22, D23, D24, D25, D26, D27, D28, D29, D30, D31, D47, D49, D51, D53, D55, D57, D59, D61, D63, D65, D67, D69, D71, D73, D75, D77, D79, D81, D83, D85, D87, D89, D91, D93, D95, D97, D99, D101, D103, D105, D107, D109, D111, D113, D115, D119, D121, D123, D125, D127, D128, D129, D130, D131, D132, D133, D134, D135, D137, D139, D141, D143, D145, D147, D148: 1N4148W; D_SOD-123
D149, D150, D151, D152, D153, D154, D155, D156, D157, D158, D159, D160, D161, D162, D163, D164, D165, D166, D167, D168, D169, D170, D171, D172, D173, D174, D175, D176, D177, D178, D179, D180, D181, D182, D183, D184, D185, D186, D187, D188, D189, D190, D191, D192, D193, D194, D195, D197, D198, D199, D200, D201, D202, D203, D204, D205, D206, D207, D208, D209, D210, D211, D212, D213, D214, D215, D216, D217, D218, D219, D220, D221, D222, D223, D224, D225, D226, D227, D228, D229: SK6812MINI; LED_SK6812MINI-E_3.2x2.8mm_P1.5mm_ReverseMount
H1, H2, H3, H4: MountingHole_Pad; MountingHole_2.2mm_M2_Pad_Via
J1: Conn_01x04_Socket; JST_PH_B4B-PH-K_1x04_P2.00mm_Vertical
J4: Conn_01x04_Pin; PinHeader_1x04_P2.54mm_Vertical
J5: USB_C_Receptacle_USB2.0_16P; USB_C_Receptacle_C2765186
J6: Conn_01x04; PinHeader_1x04_P2.54mm_Vertical
J9: SM03B-SRSS-TB; JST_SH_BM03B-SRSS-TB_1x03-1MP_P1.00mm_Vertical
R6, R7: 5k1; R_0402_1005Metric
R26, R28: 27; R_0402_1005Metric
R30, R31, R32: 1k; R_0402_1005Metric
R36: DNF; R_0402_1005Metric
R37: 0; SolderJumper-2_P1.3mm_Bridged_RoundedPad1.0x1.5mm
SW1: RotaryEncoder_Switch; RotaryEncoder_Alps_EC11E-Switch_Vertical_H20mm
SW2: SW_BOOT_SELECT; TactileSwitch
SW3: SW_RESET; TactileSwitch
SW10, SW11, SW12, SW13, SW14, SW15, SW16, SW17, SW19, SW20, SW21, SW22, SW23, SW24, SW25, SW26, SW27, SW28, SW29, SW30, SW31, SW32, SW33, SW34, SW35, SW36, SW37, SW38, SW39, SW40, SW41, SW42, SW43, SW44, SW45, SW46, SW47, SW48, SW49, SW50, SW51, SW52, SW53, SW54, SW55, SW56, SW57, SW58, SW59, SW61, SW64, SW65, SW66, SW67, SW68, SW70, SW71, SW72, SW73, SW74, SW76, SW77, SW78, SW79, SW80: MX; Kailh_socket_MX_1-00U
SW18: MX; Kailh_socket_MX_6-25U
SW62, SW63, SW69, SW75: MX; Kailh_socket_MX_2-00U
TP1, TP2, TP3, TP4, TP5, TP6, TP7, TP8, TP9, TP10, TP11, TP12, TP13, TP14, TP15, TP16, TP17: TestPoint; TestPoint_THTPad_D1.0mm_Drill0.5mm
U4: NCP1117-3.3; SOT-223-3_TabPin2
U7: RP2040; QFN-56-1EP_7x7mm_P0.4mm_EP3.2x3.2mm
U9: W25Q128JVS; SOIC-8_5.3x5.3mm_P1.27mm
X1: 12MHz; Crystal_SMD_Abracon_ABM8AIG-4Pin_3.2x2.5mm

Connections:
+1V1: C4.1, C5.1, C6.1, U7.23 (DVDD), U7.45 (VREG_VOUT), U7.50 (DVDD)
+3V3: C7.1, C8.1, C9.1, C10.1, C11.1, C12.1, C13.1, C14.1, C27.1, C28.1, C42.1, J1.3, J6.3, R36.1, U4.2 (VO), U7.1 (IOVDD), U7.10 (IOVDD), U7.22 (IOVDD), U7.33 (IOVDD), U7.42 (IOVDD), U7.43 (ADC_AVDD), U7.44 (VREG_IN), U7.48 (USB_VDD), U7.49 (IOVDD), U9.8 (VCC)
/Controller/FLASH_SS: R36.2, R37.2, U9.1 (~CS)
/Controller/QSPI_SCLK: U7.52 (QSPI_SCLK), U9.6 (CLK)
/Controller/QSPI_SD0: U7.53 (QSPI_SD0), U9.5 (DI(IO0))
/Controller/QSPI_SD1: U7.55 (QSPI_SD1), U9.2 (DO(IO1))
/Controller/QSPI_SD2: U7.54 (QSPI_SD2), U9.3 (IO2)
/Controller/QSPI_SD3: U7.51 (QSPI_SD3), U9.7 (IO3)
/Controller/QSPI_SS: R30.1, R37.1, U7.56 (QSPI_SS)
/Controller/SCL: J1.1, J6.2, U7.41 (GPIO29_ADC3)
/Controller/SDA: J1.2, J6.1, U7.40 (GPIO28_ADC2)
/Controller/SWCLK: J9.1, U7.24 (SWCLK)
/Controller/SWD: J9.3, U7.25 (SWD)
/Controller/USB_D+: J4.3, J5.A6 (D+), J5.B6 (D+), R26.1
/Controller/USB_D-: J4.2, J5.A7 (D-), J5.B7 (D-), R28.1
/Controller/USB_DN: R28.2, U7.46 (USB_DM)
/Controller/USB_DP: R26.2, U7.47 (USB_DP)
/Controller/XIN: C24.1, U7.20 (XIN), X1.1
/Controller/XOUT: R31.2, U7.21 (XOUT)
/Controller/~USB_BOOT: R30.2, SW2.2
/Key0/RGB_IN: D169.4 (DOUT), D178.2 (DIN)
/Key0/RGB_OUT: D178.4 (DOUT), D185.2 (DIN)
/Key1/RGB_IN: D193.2 (DIN), D201.4 (DOUT)
/Key1/RGB_OUT: D186.2 (DIN), D193.4 (DOUT)
/Key2/RGB_OUT: D177.2 (DIN), D186.4 (DOUT)
/Key3/RGB_OUT: D170.2 (DIN), D177.4 (DOUT)
/Key4/RGB_OUT: D167.2 (DIN), D170.4 (DOUT)
/Key5/RGB_OUT: D151.2 (DIN), D167.4 (DOUT)
/Key6/RGB_OUT: D150.2 (DIN), D151.4 (DOUT)
/Key7/RGB_OUT: D150.4 (DOUT), D168.2 (DIN)
/Key8/RGB_OUT: D168.4 (DOUT), D169.2 (DIN)
/KeyA/RGB_IN: D197.2 (DIN), D202.4 (DOUT)
/KeyA/RGB_OUT: D188.2 (DIN), D197.4 (DOUT)
/KeyAlt/RGB_IN: D198.4 (DOUT), D227.2 (DIN)
/KeyAlt/RGB_OUT: D221.2 (DIN), D227.4 (DOUT)
/KeyB/RGB_IN: D155.4 (DOUT), D161.2 (DIN)
/KeyB/RGB_OUT: D161.4 (DOUT), D176.2 (DIN)
/KeyBackslash/RGB_IN: D204.4 (DOUT), D229.2 (DIN)
/KeyBackslash/RGB_OUT: D194.2 (DIN), D229.4 (DOUT)
/KeyBreak/RGB_IN: D210.2 (DIN), D226.4 (DOUT)
/KeyBreak/RGB_OUT: D210.4 (DOUT), D225.2 (DIN)
/KeyC/RGB_IN: D176.4 (DOUT), D184.2 (DIN)
/KeyC/RGB_OUT: D184.4 (DOUT), D187.2 (DIN)
/KeyCaps/RGB_IN: D202.2 (DIN), D206.4 (DOUT)
/KeyComma/RGB_IN: D175.2 (DIN), D179.4 (DOUT)
/KeyComma/RGB_OUT: D162.2 (DIN), D175.4 (DOUT)
/KeyControl/RGB_IN: D205.2 (DIN), D209.4 (DOUT)
/KeyControl/RGB_OUT: D198.2 (DIN), D205.4 (DOUT)
/KeyD/RGB_IN: D181.2 (DIN), D188.4 (DOUT)
/KeyD/RGB_OUT: D174.2 (DIN), D181.4 (DOUT)
/KeyDelete/RGB_IN: D195.4 (DOUT), D204.2 (DIN)
/KeyE/RGB_IN: D172.4 (DOUT), D183.2 (DIN)
/KeyE/RGB_OUT: D183.4 (DOUT), D189.2 (DIN)
/KeyEqual/RGB_IN: D185.4 (DOUT), D195.2 (DIN)
/KeyEsc/RGB_IN: D201.2 (DIN), D211.4 (DOUT)
/KeyF1/RGB_IN: D149.4 (DOUT), D154.2 (DIN)
/KeyF1/RGB_OUT: D154.4 (DOUT), D207.2 (DIN)
/KeyF2/RGB_OUT: D159.2 (DIN), D207.4 (DOUT)
/KeyF3/RGB_OUT: D159.4 (DOUT), D208.2 (DIN)
/KeyF4/RGB_OUT: D160.2 (DIN), D208.4 (DOUT)
/KeyF/RGB_OUT: D163.2 (DIN), D174.4 (DOUT)
/KeyFn/RGB_IN: D226.2 (DIN), D228.4 (DOUT)
/KeyG/RGB_OUT: D157.2 (DIN), D163.4 (DOUT)
/KeyH/RGB_OUT: D156.2 (DIN), D157.4 (DOUT)
/KeyHelp/RGB_OUT: D160.4 (DOUT), D214.2 (DIN)
/KeyI/RGB_IN: D166.2 (DIN), D171.4 (DOUT)
/KeyI/RGB_OUT: D152.2 (DIN), D166.4 (DOUT)
/KeyJ/RGB_OUT: D156.4 (DOUT), D164.2 (DIN)
/KeyK/RGB_OUT: D164.4 (DOUT), D173.2 (DIN)
/KeyL/RGB_OUT: D173.4 (DOUT), D182.2 (DIN)
/KeyLeftBracket/RGB_IN: D190.2 (DIN), D194.4 (DOUT)
/KeyLeftBracket/RGB_OUT: D180.2 (DIN), D190.4 (DOUT)
/KeyLeftShift/RGB_IN: D200.4 (DOUT), D209.2 (DIN)
/KeyM/RGB_OUT: D155.2 (DIN), D162.4 (DOUT)
/KeyO/RGB_IN: D171.2 (DIN), D180.4 (DOUT)
/KeyOption/RGB_IN: D212.2 (DIN), D213.4 (DOUT)
/KeyOption/RGB_OUT: D211.2 (DIN), D212.4 (DOUT)
/KeyPeriod/RGB_IN: D179.2 (DIN), D191.4 (DOUT)
/KeyQ/RGB_IN: D189.4 (DOUT), D199.2 (DIN)
/KeyQ/RGB_OUT: D199.4 (DOUT), D206.2 (DIN)
/KeyQuote/RGB_IN: D182.4 (DOUT), D192.2 (DIN)
/KeyQuote/RGB_OUT: D192.4 (DOUT), D203.2 (DIN)
/KeyR/RGB_IN: D165.4 (DOUT), D172.2 (DIN)
/KeyReturn/RGB_OUT: D203.4 (DOUT), D215.2 (DIN)
/KeyRightAlt/RGB_IN: D224.4 (DOUT), D228.2 (DIN)
/KeyRightShift/RGB_OUT: D191.2 (DIN), D215.4 (DOUT)
/KeySelect/RGB_IN: D213.2 (DIN), D214.4 (DOUT)
/KeySpace/RGB_IN: D158.2 (DIN), D222.4 (DOUT)
/KeySpace/RGB_OUT: D158.4 (DOUT), D223.2 (DIN)
/KeyT/RGB_IN: D153.4 (DOUT), D165.2 (DIN)
/KeyU/RGB_OUT: D152.4 (DOUT), D153.2 (DIN)
/KeyX/RGB_OUT: D187.4 (DOUT), D200.2 (DIN)
/Logo1/RGB_OUT: D216.4 (DOUT), D217.2 (DIN)
/Logo2/RGB_OUT: D217.4 (DOUT), D218.2 (DIN)
/Logo3/RGB_OUT: D218.4 (DOUT), D219.2 (DIN)
/Logo4/RGB_OUT: D219.4 (DOUT), D220.2 (DIN)
/Logo5/RGB_OUT: D149.2 (DIN), D220.4 (DOUT)
/Space1/RGB_OUT: D221.4 (DOUT), D222.2 (DIN)
/Space3/RGB_OUT: D223.4 (DOUT), D224.2 (DIN)
COL_1: SW10.1, SW11.1, SW12.1, SW13.1, SW14.1, SW15.1, SW19.1, TP1.1 (1_1), U7.11 (GPIO8)
COL_2: SW16.1, SW17.1, SW18.1, SW20.1, TP2.1 (1_1), U7.12 (GPIO9)
COL_3: SW21.1, SW22.1, SW23.1, SW24.1, SW25.1, SW26.1, SW27.1, SW28.1, TP3.1 (1_1), U7.13 (GPIO10)
COL_4: SW29.1, SW30.1, SW31.1, SW32.1, SW33.1, SW34.1, SW35.1, SW36.1, TP4.1 (1_1), U7.14 (GPIO11)
COL_5: SW37.1, SW38.1, SW39.1, SW40.1, SW41.1, SW42.1, SW43.1, SW44.1, TP5.1 (1_1), U7.15 (GPIO12)
COL_6: SW45.1, SW46.1, SW47.1, SW48.1, SW49.1, SW50.1, SW51.1, SW52.1, TP6.1 (1_1), U7.16 (GPIO13)
COL_7: SW53.1, SW54.1, SW55.1, SW56.1, SW57.1, SW58.1, SW59.1, TP7.1 (1_1), U7.17 (GPIO14)
COL_8: SW61.1, SW62.1, SW63.1, SW64.1, SW65.1, SW67.1, SW68.1, SW80.1, TP8.1 (1_1), U7.18 (GPIO15)
COL_9: SW66.1, SW69.1, SW70.1, SW75.1, SW76.1, SW77.1, SW78.1, SW79.1, TP9.1 (1_1), U7.27 (GPIO16)
CONSOLE: SW71.1, SW72.1, SW73.1, SW74.1, U7.28 (GPIO17)
EncoderA: SW1.A, U7.37 (GPIO25)
EncoderB: SW1.B, U7.36 (GPIO24)
EncoderSwitch: SW1.S1, U7.35 (GPIO23)
GND: C4.2, C5.2, C6.2, C7.2, C8.2, C9.2, C10.2, C11.2, C12.2, C13.2, C14.2, C24.2, C25.1, C27.2, C28.2, C42.2, C43.1, C75.2, C76.2, C77.2, C78.2, C79.2, C80.2, C81.2, C82.2, C83.2, C84.2, C85.2, C86.2, C87.2, C88.2, C89.2, C90.2, C91.2, C92.2, C93.2, C94.2, C95.2, C96.2, C97.2, C98.2, C99.2, C100.2, C101.2, C102.2, C103.2, C104.2, C105.2, C106.2, C107.2, C108.2, C109.2, C110.2, C111.2, C112.2, C113.2, C114.2, C115.2, C116.2, C117.2, C118.2, C119.2, C120.2, C121.2, C123.2, C124.2, C125.2, C126.2, C127.2, C128.2, C129.2, C130.2, C131.2, C132.2, C133.2, C134.2, C135.2, C136.2, C137.2, C138.2, C139.2, C140.2, C141.2, C142.2, C143.2, C144.2, C145.2, C146.2, C147.2, C148.2, C149.2, C150.2, C151.2, C152.2, C153.2, C154.2, C155.2, D149.1 (VSS), D150.1 (VSS), D151.1 (VSS), D152.1 (VSS), D153.1 (VSS), D154.1 (VSS), D155.1 (VSS), D156.1 (VSS), D157.1 (VSS), D158.1 (VSS), D159.1 (VSS), D160.1 (VSS), D161.1 (VSS), D162.1 (VSS), D163.1 (VSS), D164.1 (VSS), D165.1 (VSS), D166.1 (VSS), D167.1 (VSS), D168.1 (VSS), D169.1 (VSS), D170.1 (VSS), D171.1 (VSS), D172.1 (VSS), D173.1 (VSS), D174.1 (VSS), D175.1 (VSS), D176.1 (VSS), D177.1 (VSS), D178.1 (VSS), D179.1 (VSS), D180.1 (VSS), D181.1 (VSS), D182.1 (VSS), D183.1 (VSS), D184.1 (VSS), D185.1 (VSS), D186.1 (VSS), D187.1 (VSS), D188.1 (VSS), D189.1 (VSS), D190.1 (VSS), D191.1 (VSS), D192.1 (VSS), D193.1 (VSS), D194.1 (VSS), D195.1 (VSS), D197.1 (VSS), D198.1 (VSS), D199.1 (VSS), D200.1 (VSS), D201.1 (VSS), D202.1 (VSS), D203.1 (VSS), D204.1 (VSS), D205.1 (VSS), D206.1 (VSS), D207.1 (VSS), D208.1 (VSS), D209.1 (VSS), D210.1 (VSS), D211.1 (VSS), D212.1 (VSS), D213.1 (VSS), D214.1 (VSS), D215.1 (VSS), D216.1 (VSS), D217.1 (VSS), D218.1 (VSS), D219.1 (VSS), D220.1 (VSS), D221.1 (VSS), D222.1 (VSS), D223.1 (VSS), D224.1 (VSS), D225.1 (VSS), D226.1 (VSS), D227.1 (VSS), D228.1 (VSS), D229.1 (VSS), H1.1 (1_1), H2.1 (1_1), H3.1 (1_1), H4.1 (1_1), J1.4, J4.4, J5.A1 (GND), J5.A12 (GND), J5.B1 (GND), J5.B12 (GND), J5.S1 (SHIELD), J6.4, J9.2, J9.MP (MountPin), R6.2, R7.2, SW1.C, SW1.MP, SW1.S2, SW2.1, SW3.1, U4.1 (GND), U7.19 (TESTEN), U7.57 (GND), U9.4 (GND), X1.2, X1.4
unnamed: C25.2, R31.1, X1.3
unnamed: D17.2 (A), SW10.2
unnamed: D18.2 (A), SW11.2
unnamed: D19.2 (A), SW12.2
unnamed: D20.2 (A), SW13.2
unnamed: D21.2 (A), SW14.2
unnamed: D22.2 (A), SW15.2
unnamed: D23.2 (A), SW16.2
unnamed: D24.2 (A), SW17.2
unnamed: D25.2 (A), SW18.2
unnamed: D26.2 (A), SW19.2
unnamed: D27.2 (A), SW20.2
unnamed: D28.2 (A), SW21.2
unnamed: D29.2 (A), SW22.2
unnamed: D30.2 (A), SW23.2
unnamed: D31.2 (A), SW24.2
unnamed: D47.2 (A), SW25.2
unnamed: D49.2 (A), SW26.2
unnamed: D51.2 (A), SW27.2
unnamed: D53.2 (A), SW28.2
unnamed: D55.2 (A), SW29.2
unnamed: D57.2 (A), SW30.2
unnamed: D59.2 (A), SW31.2
unnamed: D61.2 (A), SW32.2
unnamed: D63.2 (A), SW33.2
unnamed: D65.2 (A), SW34.2
unnamed: D67.2 (A), SW35.2
unnamed: D69.2 (A), SW36.2
unnamed: D71.2 (A), SW37.2
unnamed: D73.2 (A), SW38.2
unnamed: D75.2 (A), SW39.2
unnamed: D77.2 (A), SW40.2
unnamed: D79.2 (A), SW41.2
unnamed: D81.2 (A), SW42.2
unnamed: D83.2 (A), SW43.2
unnamed: D85.2 (A), SW44.2
unnamed: D87.2 (A), SW45.2
unnamed: D89.2 (A), SW46.2
unnamed: D91.2 (A), SW47.2
unnamed: D93.2 (A), SW48.2
unnamed: D95.2 (A), SW49.2
unnamed: D97.2 (A), SW50.2
unnamed: D99.2 (A), SW51.2
unnamed: D101.2 (A), SW52.2
unnamed: D103.2 (A), SW53.2
unnamed: D105.2 (A), SW54.2
unnamed: D107.2 (A), SW55.2
unnamed: D109.2 (A), SW56.2
unnamed: D111.2 (A), SW57.2
unnamed: D113.2 (A), SW58.2
unnamed: D115.2 (A), SW59.2
unnamed: D119.2 (A), SW61.2
unnamed: D121.2 (A), SW62.2
unnamed: D123.2 (A), SW63.2
unnamed: D125.2 (A), SW64.2
unnamed: D127.2 (A), SW65.2
unnamed: D128.2 (A), SW80.2
unnamed: D129.2 (A), SW66.2
unnamed: D130.2 (A), SW76.2
unnamed: D131.2 (A), SW67.2
unnamed: D132.2 (A), SW78.2
unnamed: D133.2 (A), SW68.2
unnamed: D134.2 (A), SW79.2
unnamed: D135.2 (A), SW69.2
unnamed: D137.2 (A), SW70.2
unnamed: D139.2 (A), SW71.2
unnamed: D141.2 (A), SW72.2
unnamed: D143.2 (A), SW73.2
unnamed: D145.2 (A), SW74.2
unnamed: D147.2 (A), SW75.2
unnamed: D148.2 (A), SW77.2
unnamed: J5.A5 (CC1), R7.1
unnamed: J5.B5 (CC2), R6.1
unnamed: R32.2, SW3.2
unnamed: R32.1, U7.26 (RUN)
OPTION: D141.1 (K), U7.30 (GPIO19)
RESET: D139.1 (K), U7.29 (GPIO18)
RGB: D216.2 (DIN), U7.38 (GPIO26_ADC0)
ROW_1: D17.1 (K), D53.1 (K), D55.1 (K), D71.1 (K), D89.1 (K), D103.1 (K), D123.1 (K), D137.1 (K), TP10.1 (1_1), U7.2 (GPIO0)
ROW_2: D18.1 (K), D51.1 (K), D57.1 (K), D73.1 (K), D87.1 (K), D105.1 (K), D119.1 (K), D130.1 (K), TP11.1 (1_1), U7.3 (GPIO1)
ROW_3: D19.1 (K), D49.1 (K), D59.1 (K), D75.1 (K), D93.1 (K), D113.1 (K), D121.1 (K), D134.1 (K), TP12.1 (1_1), U7.4 (GPIO2)
ROW_4: D20.1 (K), D47.1 (K), D61.1 (K), D77.1 (K), D99.1 (K), D111.1 (K), D131.1 (K), D148.1 (K), TP13.1 (1_1), U7.5 (GPIO3)
ROW_5: D21.1 (K), D23.1 (K), D31.1 (K), D63.1 (K), D79.1 (K), D97.1 (K), D125.1 (K), D129.1 (K), TP14.1 (1_1), U7.6 (GPIO4)
ROW_6: D24.1 (K), D30.1 (K), D65.1 (K), D81.1 (K), D95.1 (K), D109.1 (K), D127.1 (K), D132.1 (K), TP15.1 (1_1), U7.7 (GPIO5)
ROW_7: D22.1 (K), D25.1 (K), D29.1 (K), D67.1 (K), D83.1 (K), D91.1 (K), D115.1 (K), D128.1 (K), D147.1 (K), TP16.1 (1_1), U7.8 (GPIO6)
ROW_8: D26.1 (K), D27.1 (K), D28.1 (K), D69.1 (K), D85.1 (K), D101.1 (K), D107.1 (K), D133.1 (K), D135.1 (K), TP17.1 (1_1), U7.9 (GPIO7)
SELECT: D143.1 (K), U7.31 (GPIO20)
START: D145.1 (K), U7.32 (GPIO21)
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

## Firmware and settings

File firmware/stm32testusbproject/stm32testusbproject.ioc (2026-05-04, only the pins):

Mcu.UserName=STM32F407ZGTx
PA0-WKUP.Signal=ADCx_IN0
PA1.Signal=ADCx_IN1
PA11.Signal=USB_OTG_FS_DM
PA12.Signal=USB_OTG_FS_DP
PA13.Signal=SYS_JTMS-SWDIO
PA14.Signal=SYS_JTCK-SWCLK
PA2.Signal=ADCx_IN2
PA3.Signal=ADCx_IN3
PA4.Signal=ADCx_IN4
PA5.Signal=ADCx_IN5
PA6.Signal=ADCx_IN6
PA7.Signal=ADCx_IN7
PB10.Signal=USART3_TX
PB11.Signal=USART3_RX
PB12.GPIO_Label=USART_CK
PB12.Signal=GPIO_Input
PB13.GPIO_Label=USART_CTS
PB13.Signal=GPIO_Input
PB14.GPIO_Label=USART_RTS
PB14.Signal=GPIO_Input
PB3.Signal=SPI3_SCK
PB4.Signal=SPI3_MISO
PB5.Signal=SPI3_MOSI
PB6.GPIO_Label=SPI_CS1
PB6.Signal=GPIO_Output
PB7.GPIO_Label=SPI_CS2
PB7.Signal=GPIO_Output
PB8.Signal=I2C1_SCL
PB9.Signal=I2C1_SDA
PC0.Signal=ADCx_IN10
PC1.Signal=ADCx_IN11
PC10.Signal=SDIO_D2
PC11.Signal=SDIO_D3
PC12.Signal=SDIO_CK
PC13-ANTI_TAMP.GPIO_Label=SD_DETECT
PC13-ANTI_TAMP.Signal=GPIO_Input
PC14-OSC32_IN.Signal=RCC_OSC32_IN
PC15-OSC32_OUT.Signal=RCC_OSC32_OUT
PC2.Signal=ADCx_IN12
PC3.Signal=ADCx_IN13
PC5.GPIO_Label=STM_I2CRESET
PC5.Signal=GPIO_Output
PC6.Signal=USART6_TX
PC7.Signal=USART6_RX
PC8.Signal=SDIO_D0
PC9.Signal=SDIO_D1
PD0.Signal=FSMC_D2_DA2
PD1.Signal=FSMC_D3_DA3
PD10.Signal=FSMC_D15_DA15
PD11.Signal=FSMC_A16_CLE
PD12.Signal=FSMC_A17_ALE
PD13.Signal=FSMC_A18
PD14.Signal=FSMC_D0_DA0
PD15.Signal=FSMC_D1_DA1
PD2.Signal=SDIO_CMD
PD3.GPIO_Label=SD_WP
PD3.Signal=GPIO_Input
PD4.Signal=FSMC_NOE
PD5.Signal=FSMC_NWE
PD6.Signal=FSMC_NWAIT
PD7.Signal=FSMC_NE1
PD8.Signal=FSMC_D13_DA13
PD9.Signal=FSMC_D14_DA14
PE0.Signal=FSMC_NBL0
PE1.Signal=FSMC_NBL1
PE10.Signal=FSMC_D7_DA7
PE11.Signal=FSMC_D8_DA8
PE12.Signal=FSMC_D9_DA9
PE13.Signal=FSMC_D10_DA10
PE14.Signal=FSMC_D11_DA11
PE15.Signal=FSMC_D12_DA12
PE3.Signal=FSMC_A19
PE4.Signal=FSMC_A20
PE5.Signal=FSMC_A21
PE6.Signal=FSMC_A22
PE7.Signal=FSMC_D4_DA4
PE8.Signal=FSMC_D5_DA5
PE9.Signal=FSMC_D6_DA6
PF0.Signal=FSMC_A0
PF1.Signal=FSMC_A1
PF10.GPIO_Label=GPIO5
PF10.Signal=GPIO_Output
PF12.Signal=FSMC_A6
PF13.Signal=FSMC_A7
PF14.Signal=FSMC_A8
PF15.Signal=FSMC_A9
PF2.Signal=FSMC_A2
PF3.Signal=FSMC_A3
PF4.Signal=FSMC_A4
PF5.Signal=FSMC_A5
PF6.GPIO_Label=GPIO1
PF6.Signal=GPIO_Output
PF7.GPIO_Label=GPIO2
PF7.Signal=GPIO_Output
PF8.GPIO_Label=GPIO3
PF8.Signal=GPIO_Output
PF9.GPIO_Label=GPIO4
PF9.Signal=GPIO_Output
PG0.Signal=FSMC_A10
PG1.Signal=FSMC_A11
PG11.GPIO_Label=FPGA_PS_N
PG11.Signal=GPIO_Input
PG12.GPIO_Label=FPGA_IRQ
PG12.Signal=GPIO_Input
PG13.GPIO_Label=FPGA_CONFIG_N
PG13.Signal=GPIO_Input
PG14.GPIO_Label=FPGA_STATUS_N
PG14.Signal=GPIO_Input
PG15.GPIO_Label=FPGA_CONF_DONE
PG15.Signal=GPIO_Input
PG2.Signal=FSMC_A12
PG3.Signal=FSMC_A13
PG4.Signal=FSMC_A14
PG5.Signal=FSMC_A15
PG6.GPIO_Label=ESP_BOOT
PG6.Signal=GPIO_Input
PG7.GPIO_Label=ESP_EN
PG7.Signal=GPIO_Input
PH0-OSC_IN.Signal=RCC_OSC_IN
PH1-OSC_OUT.Signal=RCC_OSC_OUT

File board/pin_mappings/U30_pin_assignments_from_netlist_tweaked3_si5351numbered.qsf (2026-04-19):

set_location_assignment PIN_A3 -to FPGA_IRQ    # /FPGA/FPGA.IRQ
set_location_assignment PIN_A4 -to FPGA_GPIO[4]    # /AtariInterfaces/FPGA.GPIO4
set_location_assignment PIN_A5 -to FSMC_A[8]    # /FPGA/FSMC.A8
set_location_assignment PIN_A6 -to FSMC_A[11]    # /FPGA/FSMC.A11
set_location_assignment PIN_A7 -to FSMC_D[6]    # /FPGA/FSMC.D6
set_location_assignment PIN_A8 -to FSMC_D[9]    # /FPGA/FSMC.D9
set_location_assignment PIN_A9 -to FSMC_D[12]    # /FPGA/FSMC.D12
set_location_assignment PIN_A10 -to FSMC_D[15]    # /FPGA/FSMC.D15
set_location_assignment PIN_A12 -to CLK27_A12    # Net-(U30J-CLK8)
set_location_assignment PIN_A13 -to FSMC_A[12]    # /FPGA/FSMC.A12
set_location_assignment PIN_A14 -to FSMC_A[15]    # /FPGA/FSMC.A15
set_location_assignment PIN_A15 -to PBI_A[3]    # /AtariInterfaces/PBI.A3
set_location_assignment PIN_A16 -to PBI_A[9]    # /AtariInterfaces/PBI.A9
set_location_assignment PIN_A17 -to PBI_A[13]    # /AtariInterfaces/PBI.A13
set_location_assignment PIN_A18 -to PBI_D[0]    # /AtariInterfaces/PBI.D0
set_location_assignment PIN_A19 -to PBI_D[3]    # /AtariInterfaces/PBI.D3
set_location_assignment PIN_A20 -to PBI_D[6]    # /AtariInterfaces/PBI.D6
set_location_assignment PIN_B3 -to FPGA_GPIO[1]    # /AtariInterfaces/FPGA.GPIO1
set_location_assignment PIN_B4 -to FPGA_GPIO[3]    # /AtariInterfaces/FPGA.GPIO3
set_location_assignment PIN_B5 -to FSMC_A[7]    # /FPGA/FSMC.A7
set_location_assignment PIN_B6 -to FSMC_A[10]    # /FPGA/FSMC.A10
set_location_assignment PIN_B7 -to FSMC_D[5]    # /FPGA/FSMC.D5
set_location_assignment PIN_B8 -to FSMC_D[8]    # /FPGA/FSMC.D8
set_location_assignment PIN_B9 -to FSMC_D[11]    # /FPGA/FSMC.D11
set_location_assignment PIN_B10 -to FSMC_D[14]    # /FPGA/FSMC.D14
set_location_assignment PIN_B13 -to FSMC_A[13]    # /FPGA/FSMC.A13
set_location_assignment PIN_B14 -to FSMC_A[14]    # /FPGA/FSMC.A14
set_location_assignment PIN_B15 -to PBI_A[1]    # /AtariInterfaces/PBI.A1
set_location_assignment PIN_B16 -to PBI_A[10]    # /AtariInterfaces/PBI.A10
set_location_assignment PIN_B17 -to PBI_A[14]    # /AtariInterfaces/PBI.A14
set_location_assignment PIN_B18 -to PBI_D[1]    # /AtariInterfaces/PBI.D1
set_location_assignment PIN_B19 -to PBI_D[4]    # /AtariInterfaces/PBI.D4
set_location_assignment PIN_B20 -to PBI_D[7]    # /AtariInterfaces/PBI.D7
set_location_assignment PIN_B21 -to PBI_PHI[2]    # /AtariInterfaces/PBI.PHI2
set_location_assignment PIN_B22 -to PBI_EXTSEL    # /AtariInterfaces/PBI.EXTSEL
set_location_assignment PIN_C3 -to FPGA_GPIO[0]    # /AtariInterfaces/FPGA.GPIO0
set_location_assignment PIN_C4 -to FPGA_GPIO[2]    # /AtariInterfaces/FPGA.GPIO2
set_location_assignment PIN_C6 -to FSMC_A[9]    # /FPGA/FSMC.A9
set_location_assignment PIN_C7 -to FSMC_D[4]    # /FPGA/FSMC.D4
set_location_assignment PIN_C8 -to FSMC_D[7]    # /FPGA/FSMC.D7
set_location_assignment PIN_C10 -to FSMC_D[13]    # /FPGA/FSMC.D13
set_location_assignment PIN_C13 -to FSMC_D[1]    # /FPGA/FSMC.D1
set_location_assignment PIN_C15 -to PBI_A[0]    # /AtariInterfaces/PBI.A0
set_location_assignment PIN_C17 -to PBI_A[15]    # /AtariInterfaces/PBI.A15
set_location_assignment PIN_C19 -to PBI_D[5]    # /AtariInterfaces/PBI.D5
set_location_assignment PIN_C20 -to PBI_HALT    # /AtariInterfaces/PBI.HALT
set_location_assignment PIN_C21 -to PBI_MPD    # /AtariInterfaces/PBI.MPD
set_location_assignment PIN_C22 -to PBI_EXTENB    # /AtariInterfaces/PBI.EXTENB
set_location_assignment PIN_D1 -to SPI_MOSI    # /FPGA/SPI.MOSI
set_location_assignment PIN_D2 -to FPGAAUD_BCK    # /Audio/FPGAAUD.BCK
set_location_assignment PIN_D6 -to FSMC_A[4]    # /FPGA/FSMC.A4
set_location_assignment PIN_D7 -to FSMC_A[1]    # /FPGA/FSMC.A1
set_location_assignment PIN_D10 -to FSMC_NBL[0]    # /FPGA/FSMC.NBL0
set_location_assignment PIN_D13 -to FSMC_NWE    # /FPGA/FSMC.NWE
set_location_assignment PIN_D15 -to PBI_A[4]    # /AtariInterfaces/PBI.A4
set_location_assignment PIN_D17 -to PBI_A[12]    # /AtariInterfaces/PBI.A12
set_location_assignment PIN_D19 -to PBI_D[2]    # /AtariInterfaces/PBI.D2
set_location_assignment PIN_D20 -to PBI_CAS    # /AtariInterfaces/PBI.CAS
set_location_assignment PIN_D21 -to PBI_RD[4]    # /AtariInterfaces/PBI.RD4
set_location_assignment PIN_D22 -to PBI_S4_N    # /AtariInterfaces/PBI.S4_N
set_location_assignment PIN_E1 -to VDAC_R    # /FPGA/VDAC.R
set_location_assignment PIN_E2 -to SPI_CS[2]    # /FPGA/SPI.CS2
set_location_assignment PIN_E5 -to FSMC_A[6]    # /FPGA/FSMC.A6
set_location_assignment PIN_E6 -to FSMC_A[5]    # /FPGA/FSMC.A5
set_location_assignment PIN_E7 -to FSMC_A[2]    # /FPGA/FSMC.A2
set_location_assignment PIN_E9 -to FSMC_D[10]    # /FPGA/FSMC.D10
set_location_assignment PIN_E10 -to FSMC_NBL[1]    # /FPGA/FSMC.NBL1
set_location_assignment PIN_E11 -to FSMC_A[18]    # /FPGA/FSMC.A18
set_location_assignment PIN_E12 -to FSMC_D[0]    # /FPGA/FSMC.D0
set_location_assignment PIN_E13 -to FSMC_NOE    # /FPGA/FSMC.NOE
set_location_assignment PIN_E14 -to FSMC_D[2]    # /FPGA/FSMC.D2
set_location_assignment PIN_E15 -to PBI_A[5]    # /AtariInterfaces/PBI.A5
set_location_assignment PIN_E16 -to PBI_A[7]    # /AtariInterfaces/PBI.A7
set_location_assignment PIN_E21 -to PBI_RDY    # /AtariInterfaces/PBI.RDY
set_location_assignment PIN_E22 -to SIO_DATA_IN    # /AtariInterfaces/SIO.DATA_IN
set_location_assignment PIN_F7 -to FSMC_A[3]    # /FPGA/FSMC.A3
set_location_assignment PIN_F8 -to FSMC_A[22]    # /FPGA/FSMC.A22
set_location_assignment PIN_F9 -to FSMC_A[20]    # /FPGA/FSMC.A20
set_location_assignment PIN_F10 -to FSMC_A[19]    # /FPGA/FSMC.A19
set_location_assignment PIN_F11 -to FSMC_A[17]    # /FPGA/FSMC.A17
set_location_assignment PIN_F13 -to FSMC_NWAIT    # /FPGA/FSMC.NWAIT
set_location_assignment PIN_F14 -to FSMC_D[3]    # /FPGA/FSMC.D3
set_location_assignment PIN_F15 -to PBI_A[8]    # /AtariInterfaces/PBI.A8
set_location_assignment PIN_F16 -to PBI_A[6]    # /AtariInterfaces/PBI.A6
set_location_assignment PIN_F17 -to PBI_RW_N    # /AtariInterfaces/PBI.RW_N
set_location_assignment PIN_F19 -to PBI_IRQ    # /AtariInterfaces/PBI.IRQ
set_location_assignment PIN_F20 -to SIO_COMMAND    # /AtariInterfaces/SIO.COMMAND
set_location_assignment PIN_F21 -to SIO_CLOCK_IN    # /AtariInterfaces/SIO.CLOCK_IN
set_location_assignment PIN_F22 -to SIO_CLOCK_OUT    # /AtariInterfaces/SIO.CLOCK_OUT
set_location_assignment PIN_G2 -to VDAC_G    # /FPGA/VDAC.G
set_location_assignment PIN_G5 -to FPGAAUD_LR    # /Audio/FPGAAUD.LR
set_location_assignment PIN_G8 -to FSMC_A[0]    # /FPGA/FSMC.A0
set_location_assignment PIN_G9 -to FSMC_A[21]    # /FPGA/FSMC.A21
set_location_assignment PIN_G11 -to FSMC_A[16]    # /FPGA/FSMC.A16
set_location_assignment PIN_G16 -to PBI_A[11]    # /AtariInterfaces/PBI.A11
set_location_assignment PIN_G17 -to PBI_RST    # /AtariInterfaces/PBI.RST
set_location_assignment PIN_G18 -to PBI_D1XX    # /AtariInterfaces/PBI.D1XX
set_location_assignment PIN_G21 -to PLL2[0]    # Net-(U30J-CLK4)
set_location_assignment PIN_G22 -to PLL2[1]    # Net-(U30J-CLK5)
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

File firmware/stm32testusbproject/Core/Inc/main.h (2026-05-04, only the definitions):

#define SD_DETECT_Pin GPIO_PIN_13
#define SD_DETECT_GPIO_Port GPIOC
#define GPIO1_Pin GPIO_PIN_6
#define GPIO1_GPIO_Port GPIOF
#define GPIO2_Pin GPIO_PIN_7
#define GPIO2_GPIO_Port GPIOF
#define GPIO3_Pin GPIO_PIN_8
#define GPIO3_GPIO_Port GPIOF
#define GPIO4_Pin GPIO_PIN_9
#define GPIO4_GPIO_Port GPIOF
#define GPIO5_Pin GPIO_PIN_10
#define GPIO5_GPIO_Port GPIOF
#define STM_I2CRESET_Pin GPIO_PIN_5
#define STM_I2CRESET_GPIO_Port GPIOC
#define USART_CK_Pin GPIO_PIN_12
#define USART_CK_GPIO_Port GPIOB
#define USART_CTS_Pin GPIO_PIN_13
#define USART_CTS_GPIO_Port GPIOB
#define USART_RTS_Pin GPIO_PIN_14
#define USART_RTS_GPIO_Port GPIOB
#define ESP_BOOT_Pin GPIO_PIN_6
#define ESP_BOOT_GPIO_Port GPIOG
#define ESP_EN_Pin GPIO_PIN_7
#define ESP_EN_GPIO_Port GPIOG
#define SD_WP_Pin GPIO_PIN_3
#define SD_WP_GPIO_Port GPIOD
#define FPGA_PS_N_Pin GPIO_PIN_11
#define FPGA_PS_N_GPIO_Port GPIOG
#define FPGA_IRQ_Pin GPIO_PIN_12
#define FPGA_IRQ_GPIO_Port GPIOG
#define FPGA_CONFIG_N_Pin GPIO_PIN_13
#define FPGA_CONFIG_N_GPIO_Port GPIOG
#define FPGA_STATUS_N_Pin GPIO_PIN_14
#define FPGA_STATUS_N_GPIO_Port GPIOG
#define FPGA_CONF_DONE_Pin GPIO_PIN_15
#define FPGA_CONF_DONE_GPIO_Port GPIOG
#define SPI_CS1_Pin GPIO_PIN_6
#define SPI_CS1_GPIO_Port GPIOB
#define SPI_CS2_Pin GPIO_PIN_7
#define SPI_CS2_GPIO_Port GPIOB

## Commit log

2026-04-19 First commit, from 0.51 test production
    [10cl040.xls, ESP32_pinlist.csv, ESP32_pinlist.xlsx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]
2026-05-01 First hello world. Tried toggling a pin then tried using FSMC to test SRAM. LSE startup takes a few seconds so disabled that for now.
2026-05-01 Added SIO MOTOR issue
2026-05-03 RTOS working to some degree: toggling IO on a thread, logging over UART and USB working with the hub.
2026-07-15 Boots to ready prompt with internal ram
    [usbDeviceActelTop.stp]
2026-07-19 SDRAM version of hello world. Boots from SIO too!
    [usbDeviceActelTop.stp]
2026-08-01 PCB badge
    [Badge.kicad_pcb, Badge.kicad_sch]
2026-08-01 Keyboard firmware updte
    Add Ctrl+arrows shortcuts
    Update readme with the new shortcuts
    Fix bug with special lighting control keys
    [keymap.c]
2026-08-01 Keyboard case
    Keyboard enclosure
    [MegaXE-Console key.3mf, MegaXE-Keyboard-case-Bottom.3mf, MegaXE-Keyboard-case-Top.3mf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]
2026-08-01 Minor keyboard PCB updates
    [MegaXE-keyboard.kicad_pcb, MegaXE-plate.kicad_pcb]
2026-08-03 Console key refinements
    Removed the stabilizing columns that are not really useful and can cause jams
    Enlarged the switch cavity to prevent jams
    [MegaXE-Console key.3mf, MegaXE_keyboard_case.FCStd]
2026-08-12 Motherboard enclosure
    [MegaXE-Case-Back-panel.3mf, MegaXE-Case-Bottom.3mf, MegaXE-Case-Joystick-port-frame.3mf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]
2026-08-18 Minor keyboard schematics adjustments
    No impact on the PCB
    [key.kicad_sch, minor_switch.kicad_sch]
2026-08-18 Minor keyboard case adjustments
    [MegaXE_keyboard_case.FCStd]
2026-08-26 Add a chamfer over the right ports on the top of the case
    [MegaXE-Case-Top.3mf, MegaXE_case.FCStd]
2026-08-26 Remove clip paths from keyboard glyphs to make them easier to print
2026-08-27 Made audio connector stacked. Added S/PDIF toslink output
    [audio.kicad_sch, cycloneve.kicad_sch, tonnere.kicad_pcb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]
2026-10-16 Changed USB C flag connector to one with longer pins. JLCPCB did not like the existing one.
2026-10-18 Moved ADC pins around in order to have a dummy rank to stop bleed at high frequency sampling
2026-10-24 After simulation change video dac capacitance from 4.7pF to 1.8pF. Added square for JLCPCB qr code.

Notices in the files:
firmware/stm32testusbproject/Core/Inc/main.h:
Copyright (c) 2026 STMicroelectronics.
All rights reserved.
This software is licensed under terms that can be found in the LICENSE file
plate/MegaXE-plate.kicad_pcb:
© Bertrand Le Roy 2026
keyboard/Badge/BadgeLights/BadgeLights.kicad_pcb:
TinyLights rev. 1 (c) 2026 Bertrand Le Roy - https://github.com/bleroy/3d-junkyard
